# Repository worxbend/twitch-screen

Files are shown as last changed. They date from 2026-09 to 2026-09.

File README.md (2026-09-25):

<div align="center">

<p>🟣 STREAM CULTURE. TINY HARDWARE. BIG DESK ENERGY.</p>
<h1>✨ Twitch Screen</h1>
<p><strong>Your stream’s tiny desk bestie.</strong><br>
Live stats, little celebrations, and a front-row seat to the chaos.</p>

<p>
  
  
  
  
  
</p>

<p>
  <a href="docs/README.md"><strong>📖 Guidebook</strong></a> ·
  <a href="docs/guides/first-simulated-stream.md">🚀 Try the demo</a> ·
  <a href="docs/guides/device-build.md">🛠️ Build one</a> ·
  <a href="docs/guides/twitch-app-setup.md">🔗 Connect Twitch</a> ·
  <a href="CONTRIBUTING.md">💜 Contribute</a>
</p>

<a href="twitch-screen-cad-design/output/preview/01_front_hero.png">
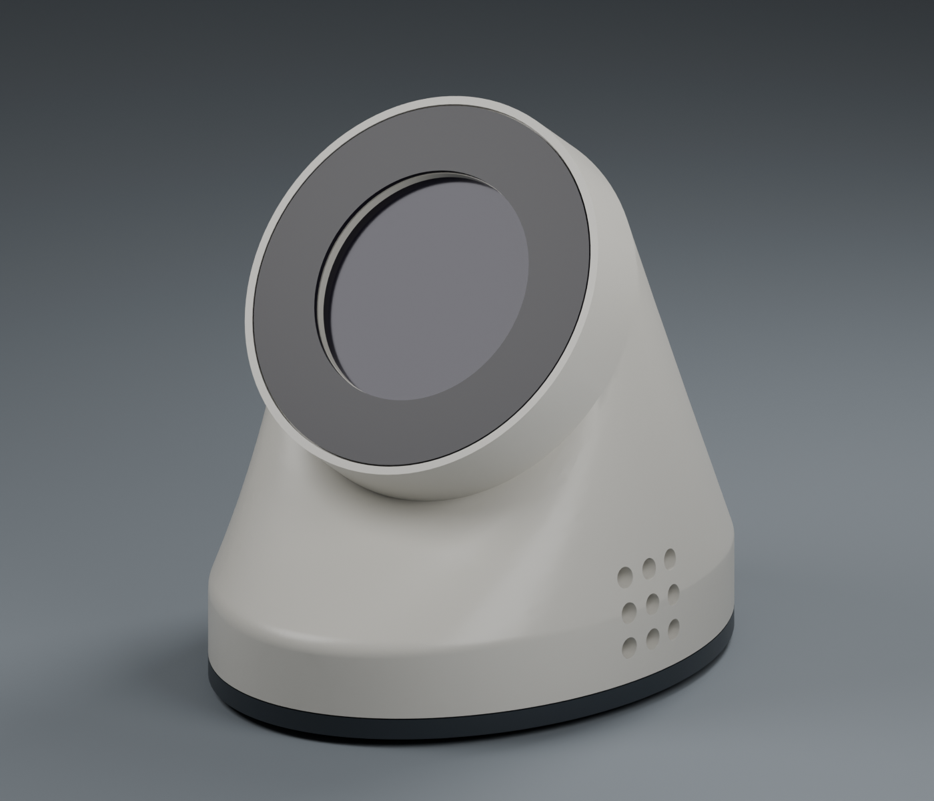
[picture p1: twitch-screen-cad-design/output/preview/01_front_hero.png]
CAD render of Twitch Screen: a warm white curved enclosure, tilted circular display, side vents, and dark removable base
  
</a>
<p><sub>Actual enclosure CAD render · screen shown unpowered · physical fit still needs validation</sub></p>

</div>

**Twitch Screen is a DIY ESP32 desk display that brings your Twitch stream into the physical world.** A 240 × 240 round LCD shows live viewers, uptime, followers, subscribers, and chat activity. Follow, sub, gift, raid, and bits events get their own animated notification cards. A Scala relay does the Twitch work; a printable little pod gives it a home. 🏡

Start with a simulated stream on your computer. Add the display when you’re ready. Connect your own Twitch channel after that. The full path is in the **[guidebook](docs/README.md)**.

## 📸 On a real desk

<p align="center">
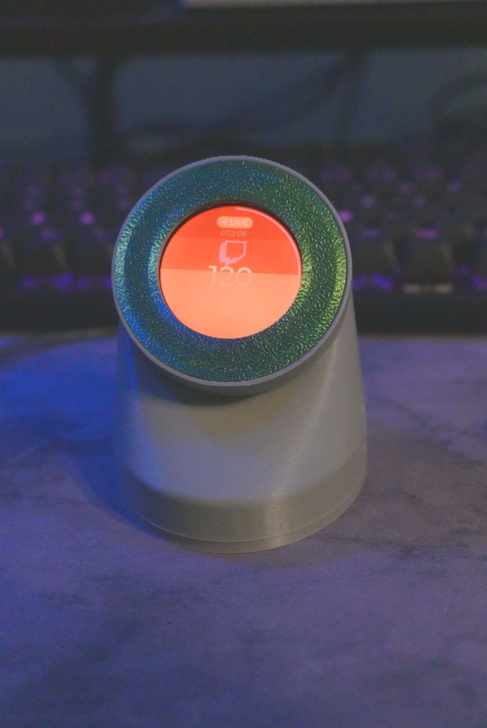
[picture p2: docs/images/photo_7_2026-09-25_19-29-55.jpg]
Assembled Twitch Screen showing live viewer stats
  
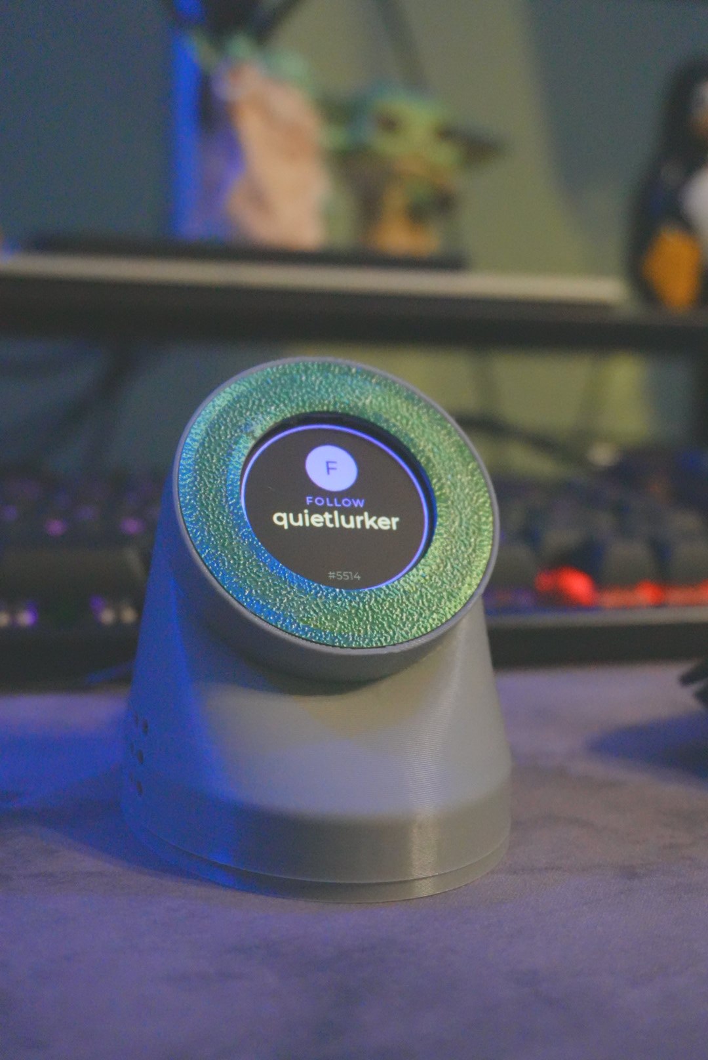
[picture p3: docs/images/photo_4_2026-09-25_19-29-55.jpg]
Front view of the assembled display showing a follow notification
  
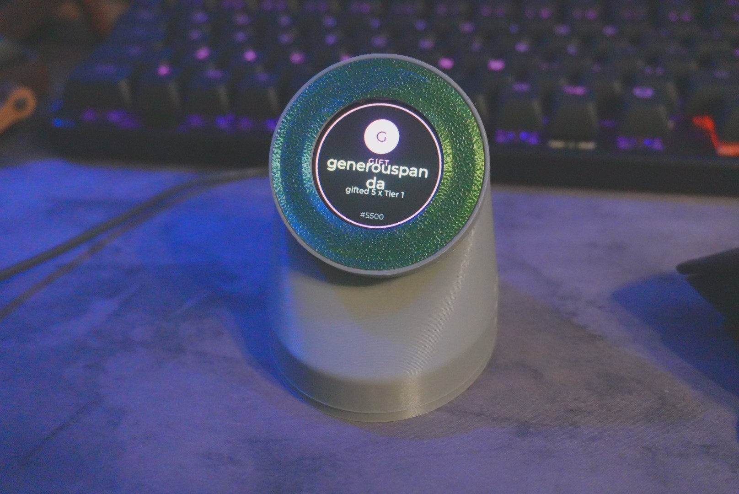
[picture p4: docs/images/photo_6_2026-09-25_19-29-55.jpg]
Assembled display showing a gift subscription notification
  
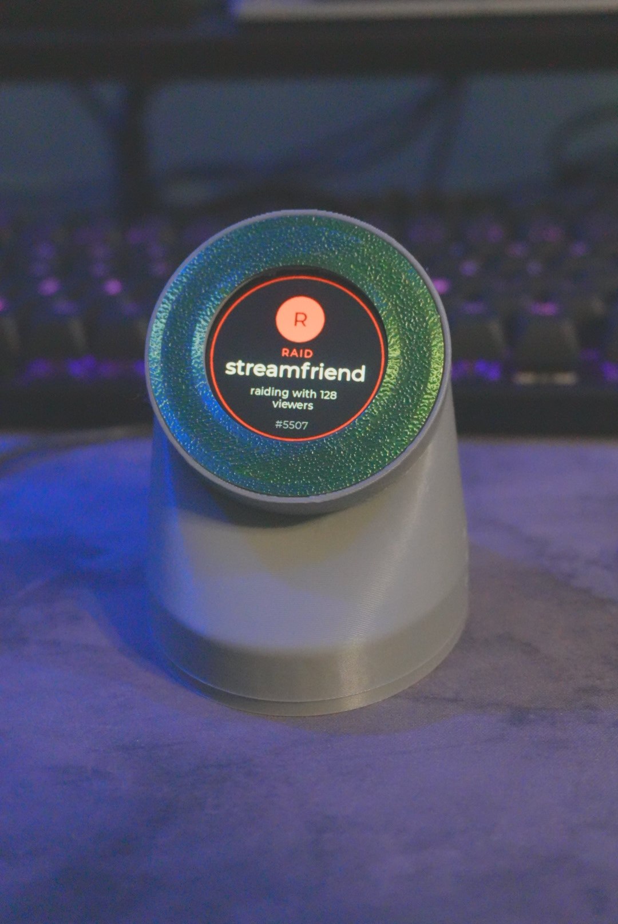
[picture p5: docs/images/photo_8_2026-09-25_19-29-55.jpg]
Front view of the assembled display showing a raid notification
  
</p>
<p align="center">
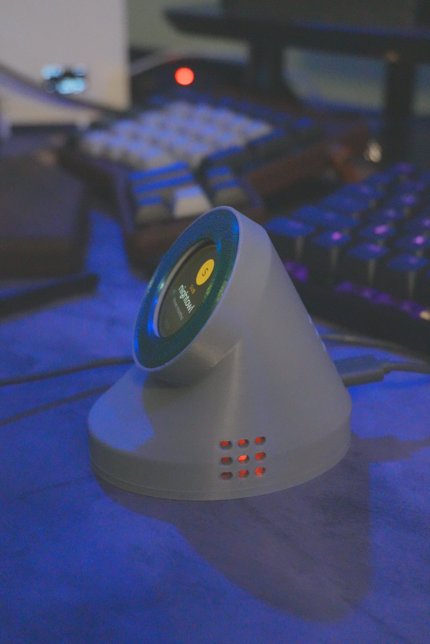
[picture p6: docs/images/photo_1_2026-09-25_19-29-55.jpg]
Side view of the assembled display on a desk
  
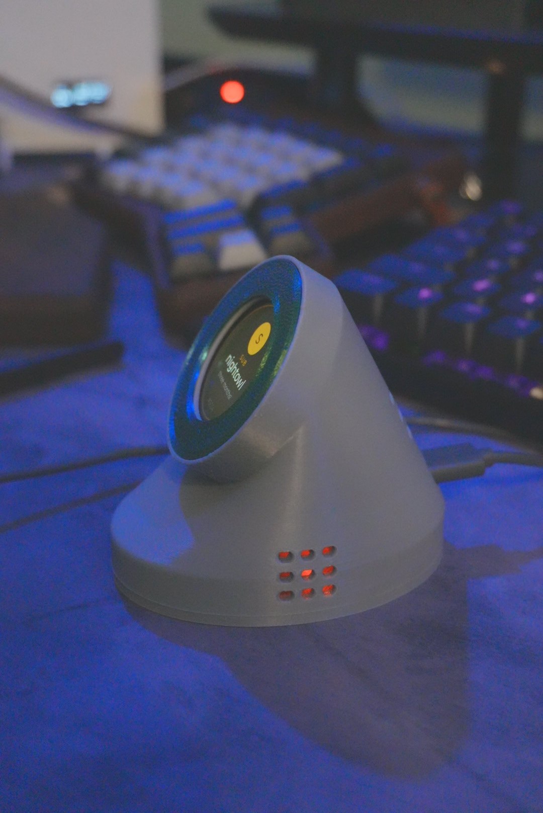
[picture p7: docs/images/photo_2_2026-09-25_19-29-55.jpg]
Angled view of the display enclosure and illuminated side vents
  
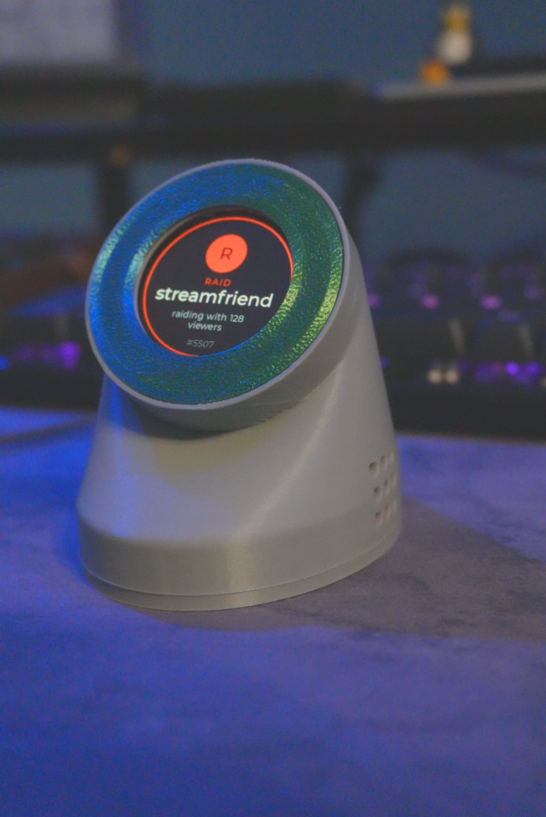
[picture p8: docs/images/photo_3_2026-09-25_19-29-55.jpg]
Angled view of the assembled display showing a raid notification
  
  <a href="docs/images/photo_5_2026-09-25_19-29-55.jpg">Side view of the enclosure showing the tilted screen and vent pattern</a>
</p>
<p align="center"><sub>Assembled prototype · select a photo to see it full size</sub></p>

## 👀 Small screen. Main-character energy.

| On your desk | Under the hood |
| :--- | :--- |
| 📊 **Stats at a glance** — live/offline state, audience totals, uptime, and a chat activity ring | LVGL 9 UI on a GC9A01 round LCD |
| 🎉 **A little celebration** — cards for follows, subs, gifts, bits, and raids | Twitch Helix, anonymous IRC, and EventSub feed the relay |
| 🧪 **No stream? Still a vibe.** — try a scripted audience without Twitch credentials | The real relay runs in `simulated` mode |
| 🔌 **Reconnect and carry on** — bounded replay helps recover recent notifications | Binary TSB/3 over one persistent TCP connection; replay lives in memory |
| 🖨️ **Print your desk buddy** — curved shell, dark base, rear USB-C | Four printable parts; editable FreeCAD, STEP, STL, and 3MF files included |
| 🛠️ **Make it yours** — inspect devices, disconnect a session, send test cards | Authenticated HTTP management API with Swagger UI |

Chat cards are hidden by default; chat still contributes to activity stats. No touch controls or on-device setup menu are implemented. Configure Wi-Fi and the relay address before flashing.

## 🧭 Pick your side quest

| You’re here to… | Start here | You’ll end up with… |
| :--- | :--- | :--- |
| **See what it does** 👋 | [First simulated stream](docs/guides/first-simulated-stream.md) | A working relay and observable events; no hardware or Twitch account needed |
| **Build the whole thing** 🔧 | [Parts, wiring & assembly](docs/guides/device-build.md) | A measured, wired, printed device ready for firmware |
| **Flash an ESP32** ⚡ | [Firmware setup](docs/guides/firmware-setup.md) | Wi-Fi, a relay address, and firmware on your board |
| **Use a real channel** 🟣 | [Twitch app setup](docs/guides/twitch-app-setup.md) | A registered app and broadcaster authorization |
| **Host the backend** 🖥️ | [Relay setup](docs/guides/relay-setup.md) | A configured local or Docker service with persistent tokens |
| **Use an assembled device** ☕ | [Everyday use](docs/guides/device-use.md) | An understanding of the screen, cards, and reconnect behavior |
| **Hack on the project** 🧑‍💻 | [Developer guide](docs/guides/development.md) | The toolchains, checks, source map, and contribution path |

## 🚀 First run: summon the pretend chat

You need Git, a POSIX shell (Linux, macOS, or WSL), `curl`, OpenSSL, and JDK 25 on your `PATH` for this setup. The included Mill launcher downloads its pinned tooling and Temurin JDK; older Linux systems use a JVM launcher that needs an existing Java installation to bootstrap. Follow the [Java setup notes](docs/guides/development.md#checkout-and-prerequisites) and allow network access and time for the initial build.

Run this in a terminal:

```sh
git clone https://github.com/worxbend/twitch-screen.git
cd twitch-screen/twitch-screen-relay
export RELAY_HTTP_AUTH_API_TOKEN="$(openssl rand -hex 32)"
RELAY_HTTP_HOST=127.0.0.1 RELAY_DEVICE_HOST=127.0.0.1 \
  RELAY_TWITCH_MODE=simulated ./mill run
```

Keep that terminal open. The generated token protects management routes, including in simulation. In a second terminal:

```sh
curl --fail http://localhost:8080/api/v1/health
curl --fail http://localhost:8080/api/v1/stats
```

Health returns `{"status":"Up"}`. Stats change as the simulator runs; allow around 30 seconds for the first audience telemetry snapshot. Open **[Swagger UI](http://localhost:8080/docs)** to explore the API. Public health and aggregate stats work without a token; management actions require authentication.

**🎯 First win unlocked:** the backend runs without Twitch credentials or an ESP32. Follow the [annotated tutorial](docs/guides/first-simulated-stream.md) for protected requests and a test notification. Stop the relay with **Ctrl+C**.

To connect real hardware, follow [relay setup](docs/guides/relay-setup.md) to listen on a trusted LAN interface, then [configure and flash the firmware](docs/guides/firmware-setup.md). The quick start above listens only on your computer.

## 🏡 Meet the pod

<table>
  <tr>
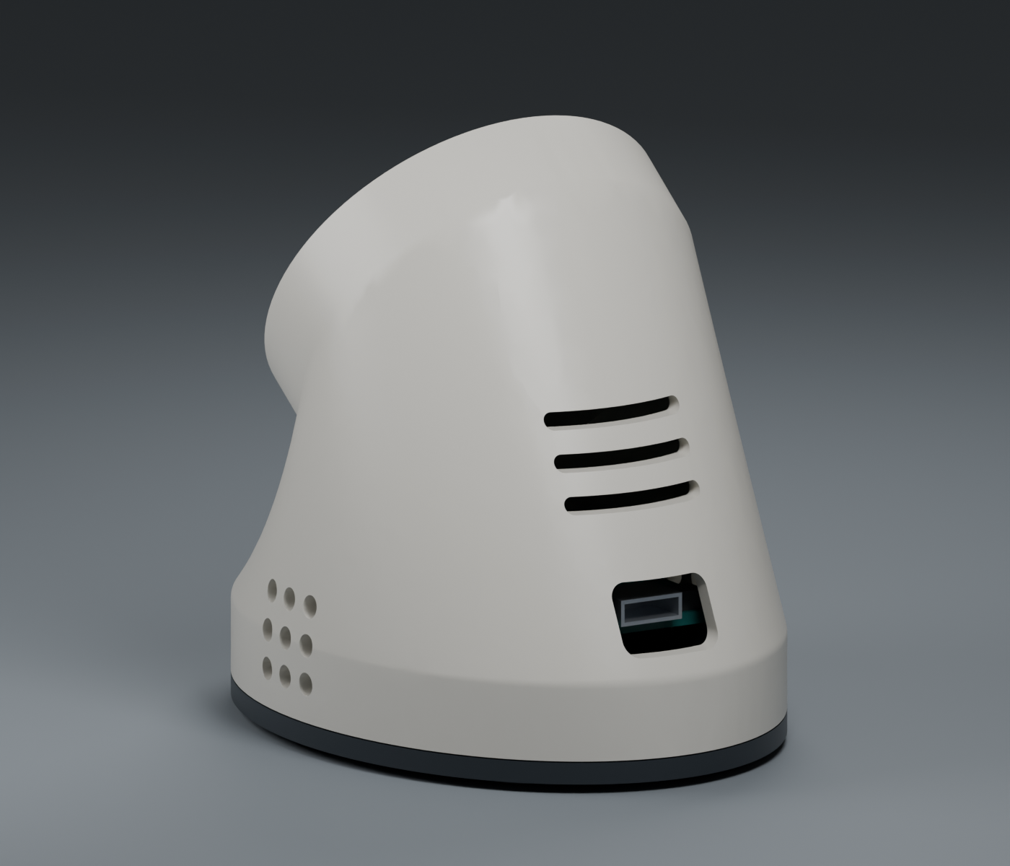
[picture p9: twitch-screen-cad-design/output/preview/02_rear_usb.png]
Rear CAD render showing the USB-C opening and ventilation
    <td align="center" width="50%"><br><strong>Business in the back 🔌</strong><br><sub>Rear USB-C and a removable base</sub></td>
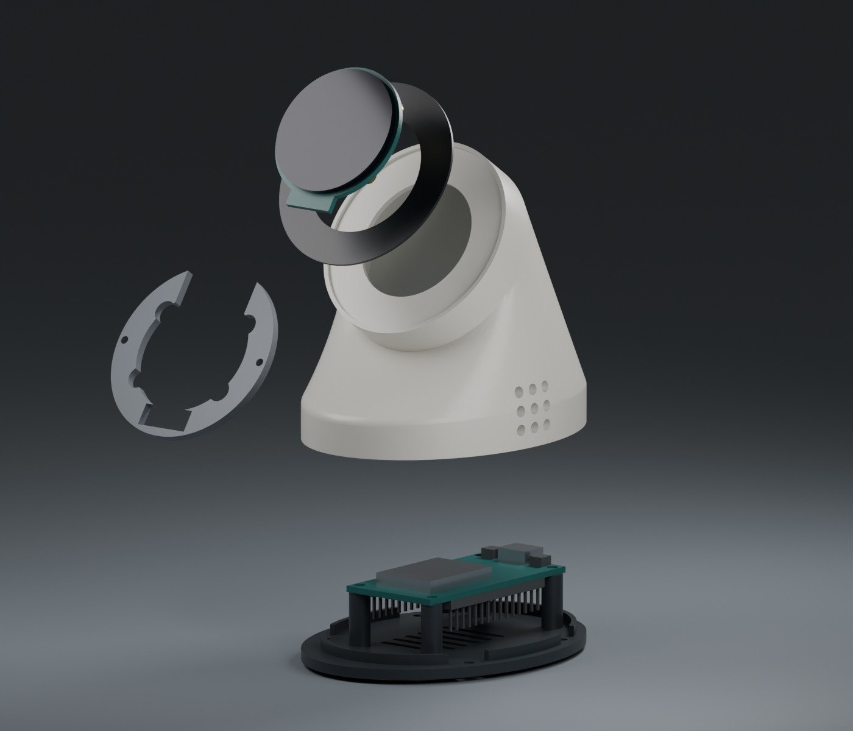
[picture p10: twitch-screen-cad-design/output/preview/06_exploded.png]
Exploded CAD render showing the round LCD, face insert, retainer, shell, ESP32, and base
    <td align="center" width="50%"><br><strong>Some assembly, much personality 🧩</strong><br><sub>Four printed parts around two boards</sub></td>
  </tr>
</table>

The nominal enclosure is **64 × 86 × 78.1 mm** before feet, with a **55° face tilt**. It targets a **30-pin ESP32 DevKit V1 Type-C** and **Waveshare 1.28inch LCD Module**. Clone boards vary: use the [measurement checklist](twitch-screen-cad-design/docs/measurement_checklist.md) before printing. Renders and automated geometry checks establish the design; a physical build must confirm fit and tolerances.

**[🖨️ Print plate](twitch-screen-cad-design/output/3mf/print_plate.3mf)** · **[📐 Editable CAD](twitch-screen-cad-design/output/freecad/TwitchScreen.FCStd)** · **[🔍 Cutaway render](twitch-screen-cad-design/output/preview/05_section.png)** · **[🛠️ Full build guide](docs/guides/device-build.md)**

## 🧠 How the magic gets to your desk

```mermaid
flowchart LR
    Twitch["🟣 Twitch<br>Helix · IRC · EventSub"] --> Relay["🖥️ Scala relay"]
    Demo["🧪 Simulated stream"] --> Relay
    Relay -->|"TSB/3 · TCP 8099"| ESP["⚡ ESP32"]
    ESP -->|SPI| LCD["📺 Round LCD"]
    Admin["🛠️ Management client"] <-->|"HTTP 8080"| Relay
```

The relay manages Twitch authorization, gathers events and stats, and pushes compact binary frames to the screen. The ESP32 manages Wi-Fi, the connection, and the UI. Live mode uses EventSub WebSocket by default, so a public webhook endpoint is unnecessary. Read the [architecture guide](docs/reference/architecture.md) for the event flow and trade-offs.

The device connection is **plain TCP without device authentication**. Keep port 8099 on a trusted LAN or private network; do not expose it directly to the internet. Remote management needs HTTPS in front of the relay. [Deployment details →](docs/guides/relay-setup.md)

## 🗂️ One repo, three workbenches

| Directory | What lives here | Tools |
| :--- | :--- | :--- |
| [`twitch-screen-relay/`](twitch-screen-relay/README.md) | Twitch integration, device server, HTTP API | Scala 3 · Mill · JDK 25 |
| [`twitch-screen-firmware/`](twitch-screen-firmware/README.md) | ESP32 firmware, UI assets, TSB/3 implementation | PlatformIO · Arduino · TFT_eSPI · LVGL 9 |
| [`twitch-screen-cad-design/`](twitch-screen-cad-design/README.md) | Parametric enclosure, print files, renders | FreeCAD · Blender |
| [`docs/`](docs/README.md) | Tutorials, setup guides, configuration and API references | GitHub Markdown |

Run each project’s commands from its own directory. There is no shared root build. The old Python demo server has been removed: its NDJSON v2 format is incompatible with the current TSB/3 firmware. Use the [Scala simulator](docs/guides/first-simulated-stream.md).

## 🧰 Commands you’ll actually use

| Working directory | Command | Purpose |
| :--- | :--- | :--- |
| `twitch-screen-relay` | `./mill test` | Relay tests |
| `twitch-screen-relay` | `./mill mill.scalalib.scalafmt/checkFormatAll` | Scala formatting check |
| `twitch-screen-relay` | `docker compose up --build` | Run the simulated relay in Docker; set management credentials first |
| `twitch-screen-firmware` | `pio run -e esp32dev` | Build firmware after creating `src/credentials.h` |
| `twitch-screen-firmware` | `pio run -e esp32dev -t upload --upload-port /dev/ttyUSB0` | Flash your board; replace the example port |
| `twitch-screen-firmware` | `pio test -e native` | Host protocol/session tests |
| Repository root | `python3 tools/check_protocol_vectors.py` | Check shared protocol vectors |

Tool installation, credentials, serial-port selection, sanitizers, containers, and CAD commands are covered in the [developer guide](docs/guides/development.md) and [guidebook](docs/README.md).

## 💜 Build with us

Found a weird pixel? A confusing setup step? A better way to mount the board? Contributions are welcome. Read **[CONTRIBUTING.md](CONTRIBUTING.md)**, run the relevant checks, and include what you observed. Hardware reports are especially useful with board measurements and photos.

[GitHub Actions](.github/workflows/ci.yml) covers relay compilation, tests, formatting and dependency auditing; firmware native/sanitizer tests and compilation; protocol vectors; CAD script syntax; and container build/smoke checks. Physical display behavior, live Twitch authorization, and printed fit need separate validation. Existing [review findings](tasks/review-status.md) and [verification evidence](tasks/review-judge.md) document those boundaries. Temporary [dependency audit exceptions](tasks/review-dependencies.md) expire on **2026-10-25**.

**Stuck?** Start with [troubleshooting](docs/guides/troubleshooting.md), then [open an issue](https://github.com/worxbend/twitch-screen/issues). Remove tokens, Wi-Fi passwords, and personal data from logs first.

**Project notes:** this is an independent DIY project, not an official Twitch product. No `LICENSE` file is currently checked in.

<div align="center">
<hr>
<p><strong>Made for the “one more stream” crowd. 🌙</strong><br>
<sub>May your packets arrive and your first layer stick.</sub></p>
</div>

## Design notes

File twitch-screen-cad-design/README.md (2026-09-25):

<div align="center">

<h1>🛠️ Twitch Screen · The Enclosure</h1>

<p><strong>A tiny pod with extremely important desk-job energy.</strong></p>
<p>Parametric FreeCAD · Four printable parts · Rear USB-C · 55° display face</p>

<p>
  <a href="../docs/guides/device-build.md">Build guide</a> ·
  <a href="output/3mf/print_plate.3mf">Print plate</a> ·
  <a href="docs/measurement_checklist.md">Measure your hardware</a> ·
  <a href="../docs/README.md">Guidebook</a>
</p>

CAD render of the warm-colored round display pod on its dark removable base

<p><em>Rendered from the project CAD. Nominal design validated; physical print and fit still require testing.</em></p>

</div>

Parametric FreeCAD enclosure for the photographed **30-pin ESP32 DevKit V1
Type-C** and **Waveshare 1.28inch LCD Module**, based on `PLAN.md`.

The circular face tilts 55° from horizontal. A warm-coloured pod meets a dark
removable base; all fasteners are concealed from the front. USB-C faces the rear.
Nominal envelope: **64 × 86 × 78.1 mm**, before adhesive feet.

## ✨ Take the tour

| Backstage access 🔌 | Every layer, explained 🧩 |
| --- | --- |
| Rear CAD render showing the recessed USB-C opening | Exploded CAD render showing the four printed parts and electronics |

New to the build? The [step-by-step device guide](../docs/guides/device-build.md) covers the parts list, exact GPIO wiring, slicer starting points and assembly. Prove the electronics with the [LAN-reachable simulated relay](../docs/guides/firmware-setup.md#start-a-relay-the-physical-device-can-reach), then close the case. 💜

All four hardware photos and five added concept screenshots were inspected.
The exterior follows their light curved pod, thin rim/dark face, side and rear
ventilation, vented underside and low base seam. The conflicting front USB in
one screenshot is overridden by PLAN.md's rear-only requirement.
See [reference analysis](docs/reference_analysis.md) and the
[measurement checklist](docs/measurement_checklist.md). Clone dimensions and
LCD thickness/connector dimensions remain provisional and editable.

## Repository layout

```
twitch-screen-cad-design/
├── parameters.json         all 57 design parameters — the input to everything
├── TwitchScreen.FCMacro    interactive entry point (must stay at this level)
├── scripts/                the model and the pipeline (must stay at this level)
│   ├── pod_geometry.py     pure BRep builder, no file I/O
│   ├── pod_document.py     wraps geometry in FreeCAD document objects
│   ├── export_project.py   writes every STEP/STL/3MF/FCStd + render meshes
│   ├── verify_*.py         exports, assembly and wall-thickness checks
│   ├── render_previews.py  Blender Cycles previews
│   └── package_project.py  gallery, manifest and deliverables zip
├── docs/                   reference analysis, measurement checklist, audit
├── refs/                   input imagery this design was derived from
│   ├── hardware/           photos of the actual ESP32 and LCD
│   ├── concepts/           concept screenshots
│   └── datasheets/         Waveshare dimension drawings
├── output/                 everything below is generated — see note
│   ├── freecad/            editable FCStd masters
│   ├── step/ stl/ 3mf/     CAD interchange and printable meshes
│   ├── preview/            Cycles renders + the Blender scene
│   ├── render_meshes/      intermediate meshes, consumed only by Blender
│   └── reports/            the four validation JSON reports
└── logs/                   run logs (ignored by git)
```

`output/` is committed on purpose: regenerating it needs FreeCAD 1.1.3 and
Blender 5.2, so on a machine without them these files are the only copy of the
design. `output/manifest.json` and `output/index.html` are the exceptions —
they are release artifacts, regenerated by `package_project.py`, and are
ignored by git because they go stale the moment any source file changes.

> **Do not move `scripts/` or `TwitchScreen.FCMacro`.** Every script derives
> its project root from `Path(__file__).resolve().parents[1]`, and the macro
> uses `.parent`, so both depend on their current depth. The saved `.FCStd`
> files also embed `module="pod_document"` with no path, so `pod_geometry.py`
> and `pod_document.py` must keep their filenames and stay side by side or
> existing documents can no longer recompute.

## Deliverables

| Use | File |
| --- | --- |
| Editable master | [TwitchScreen.FCStd](output/freecad/TwitchScreen.FCStd) |
| Open with parametric code loaded | [TwitchScreen.FCMacro](TwitchScreen.FCMacro) |
| CAD interchange assembly | [TwitchScreen_assembly.step](output/step/TwitchScreen_assembly.step) |
| Arranged printable parts | [print_plate.3mf](output/3mf/print_plate.3mf) |
| Individual printable meshes | [shell.stl](output/stl/shell.stl), [base.stl](output/stl/base.stl), [lcd_retainer.stl](output/stl/lcd_retainer.stl), [face_bezel.stl](output/stl/face_bezel.stl) |
| Rendered overview | [front](output/preview/01_front_hero.png), [rear USB](output/preview/02_rear_usb.png), [section](output/preview/05_section.png), [exploded](output/preview/06_exploded.png) |

Every printed part also has an individual STEP, 3MF and FCStd under `output/`.
STEP/FCStd preserve assembly coordinates. Individual STL/3MF files are rotated
into print orientation and placed on Z=0. The combined print plate contains
only four printed parts with 10 mm spacing. Files named `assembly_view_only`
include electronics reference shapes and are for inspection, not slicing.
Preview PNGs and the Blender scene are in `output/preview/`.

## Rebuild and verify

Uses the installed FreeCAD 1.1.3 Flatpak and Blender 5.2. No third-party FreeCAD
workbench is required. From this directory:

```sh
flatpak run --env=QT_QPA_PLATFORM=offscreen --command=FreeCADCmd org.freecad.FreeCAD -c 'import sys; sys.path.insert(0,"scripts"); import export_project; export_project.main()'
uv run --with trimesh --with numpy --with networkx python scripts/verify_exports.py
flatpak run --env=QT_QPA_PLATFORM=offscreen --command=FreeCADCmd org.freecad.FreeCAD -c 'import sys; sys.path.insert(0,"scripts"); import verify_assembly, verify_walls; verify_assembly.main(); verify_walls.main()'
blender -b --threads 8 --python scripts/render_previews.py
python scripts/package_project.py
```

If using a native FreeCAD installation, replace the Flatpak command prefix
with its `FreeCADCmd` executable. For interactive editing, run the supplied
macro from FreeCAD's Macro menu; keep it beside `scripts/` and `parameters.json`.
FCStd includes saved BRep shapes and can be inspected without the script, but
the feature proxies require the local geometry module to recompute.

`output/reports/geometry_validation.json` records exact solid checks, hardware
interference, rear-port position, mesh-volume comparison and STEP/FCStd reopen
checks. `mesh_validation.json` independently checks the written STL/3MF meshes
for closed surfaces, orientation, connectedness, dimensions and print placement.
`assembly_validation.json` covers screw-head envelopes, component insertion and
base extraction at 1 mm sampled positions (not continuous swept-volume proof),
editable-parameter recompute, and reopening
all native files. `wall_validation.json` records 695 exact surface-distance
samples; the minimum is the intended 1.5 mm bezel seat. These checks establish
nominal CAD validity, not physical fit or a tested print.

## Printing and assembly

Four printed parts: shell, base, LCD retainer and matte black face insert. Suggested starting settings:
PETG, 0.4 mm nozzle, 0.2 mm layers, four perimeters, five top/bottom layers and
20–30% infill. These are starting settings, not a tested printer profile.

The shell is supplied face-down; use supports for internal screw bosses and
inspect the rear USB roof in your slicer. Keep support interfaces away from
the LCD seat. The base prints underside-down, with its posts upward. The
retainer and face insert print flat. A brim can help the shell's narrow first-layer annulus.
The four-part plate uses two rows; inspect its reported dimensions in
`output/reports/mesh_validation.json` before adding brim/support expansion.
The current plate footprint is approximately **197 × 151 mm**; print parts
individually when your bed, brim or color choices call for a different layout.

Additional parts: the two electronic boards and supplied eight-wire loom;
four M2 × 6 mm pan-head screws (Ø3.8 mm heads) for the ESP32, four M2.5 × 8 mm low-profile
pan-head screws for the base, two M2 × 5 mm pan-head screws for the retainer,
four Ø8 × approximately 1.5 mm adhesive rubber feet, and 0.15 mm double-sided
adhesive film for the face insert. Screw heads must fit
the model's recesses (base Ø5.2 mm × 1.3 mm deep). Pilot holes are intended for
carefully formed plastic threads; verify fit on a coupon before committing.

1. Attach the matte black face insert inside the fine front rim using 0.15 mm
   adhesive film. Keep adhesive clear of the display opening and use film rated
   for the intended filament.
2. Remove the LCD protective film. Seat the LCD from inside the shell, with its
   tab down and rear connector up. The glass rests behind the bezel, with the
   active area unobstructed.
3. Fit the retaining ring behind the PCB, aligning the connector notch and tab
   relief. Tighten the two M2 screws lightly and evenly into the shell bosses.
4. Fix the ESP32 onto the four base posts. Its USB-C connector points toward
   +Y (rear); the PCB antenna points toward -Y (front). Connect the LCD loom to
   the appropriate GPIOs using your firmware's pin mapping.
5. Route wires through the side cavity, away from screw posts, antenna and glass.
   Leave a service loop so the base can be lowered before disconnecting wires.
6. Seat the locating lip and close the four underside base screws. Check cable
   insertion from the rear. EN/BOOT are reached by removing the base.
7. Attach the four feet in the shallow underside recesses.

No firmware, mains-power circuit, battery, or undocumented touch-screen variant
is part of this mechanical project. Hardware representations are fit envelopes,
not detailed manufacturer CAD. Physical assembly and print tolerances must be
confirmed against the actual boards using the measurement checklist.
The single rounded `cable_route` body is a Ø4.4 mm reserved corridor for the
eight-wire loom, not one thick wire or an electrical pin-mapping diagram.

## 📚 Next stops

- [Full device build guide](../docs/guides/device-build.md) — BOM, exact wiring and ordered assembly.
- [Firmware setup](../docs/guides/firmware-setup.md) — configure, build and upload over USB.
- [Using the device](../docs/guides/device-use.md) — understand the dashboard and event cards.
- [Troubleshooting](../docs/guides/troubleshooting.md) — fit checks, USB clearance and display issues.
- [Project overview](../README.md) and [complete guidebook](../docs/README.md).

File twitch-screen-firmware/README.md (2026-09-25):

<div align="center">

<h1>⚡ Twitch Screen · Firmware</h1>

<p><strong>240 × 240 pixels. A surprising amount of personality.</strong></p>
<p>ESP32 · Arduino · TFT_eSPI · LVGL 9 · TSB/3</p>

<p>
  <a href="../docs/guides/firmware-setup.md">Flash your device</a> ·
  <a href="../docs/guides/device-build.md">Wiring & build</a> ·
  <a href="../docs/guides/device-use.md">Daily use</a> ·
  <a href="../docs/README.md">Guidebook</a>
</p>

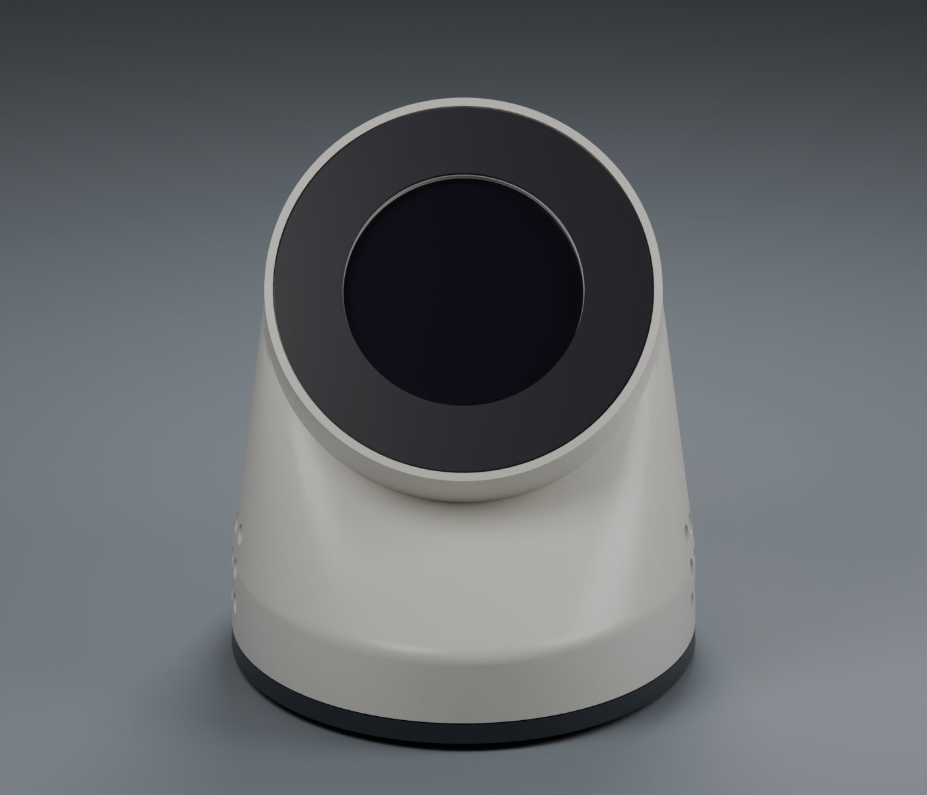
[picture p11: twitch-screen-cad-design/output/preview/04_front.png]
Front CAD render of the round display enclosure


<p><em>CAD visualization of the enclosure; physical fit remains to be validated.</em></p>

</div>

This firmware turns a classic ESP32 DevKit V1 and Waveshare GC9A01 LCD into an always-on stream dashboard. The [relay](../twitch-screen-relay/README.md) sends telemetry and notifications over persistent TCP; the device handles its own presentation, queue and reconnect loop. Your desk gets a tiny hype department. 💜

## ✨ What runs on the screen

- Animated **CONNECTING**, **OFFLINE** and **LIVE** states.
- Viewer count, stream uptime, follower/subscriber totals and observed chat total.
- A chat-activity ring and event cards for follows, subs, gifts, raids, Bits, chat and stream transitions.
- Automatic retries and bounded replay after connection interruptions.
- Custom INFO, MESSAGE, WARNING and ALERT cards supplied by the relay.

The current build has no touch/menu input, on-device provisioning, PWM brightness setting or OTA updater. Wi-Fi and relay settings are compiled in; USB is the update path. [Daily use](../docs/guides/device-use.md) explains timing, ASCII text support and recovery limits.

## 🚀 Quick start

From the **repository root**, install the pinned CLI and create the private header without replacing an existing one:

```sh
python3 -m venv .venv-pio
.venv-pio/bin/python -m pip install platformio==6.1.18
cd twitch-screen-firmware
if [ ! -e src/credentials.h ]; then
  cp src/credentials.example.h src/credentials.h
fi
```

Edit `src/credentials.h`: enter your Wi-Fi credentials, the relay computer's **LAN address**, TCP port `8099`, and optionally a unique device name. Leave `DEVICE_ID` empty for an automatic chip-derived identity. Do not commit this header or share a firmware binary containing your private settings.

The Wi-Fi password is recoverable from the firmware image/flash: this build does not enable flash encryption or secure boot. Use a trusted home network and physical device access; changing provisioning/security requires a separate migration with device recovery planning. HELLO identity/version control and non-ASCII bytes are replaced with `_` before transmission. The device TCP link is plaintext and unauthenticated; see the [protocol threat model](docs/PROTOCOL.md#2-transport-and-endianness).

Run these commands sequentially from `twitch-screen-firmware/`:

```sh
../.venv-pio/bin/pio test -e native
../.venv-pio/bin/pio run -e esp32dev
```

On Linux, also run the sanitizer gate:

```sh
../.venv-pio/bin/pio test -e native-sanitized
```

Once the correct device is connected, upload and inspect it:

```sh
../.venv-pio/bin/pio run -e esp32dev -t upload
../.venv-pio/bin/pio device monitor
```

The monitor uses 115200 baud. Close it before another upload. For explicit port selection, OS setup and BOOT-button recovery, use the complete [firmware setup guide](../docs/guides/firmware-setup.md).

Before first boot, start the [LAN-reachable simulated relay](../docs/guides/firmware-setup.md#start-a-relay-the-physical-device-can-reach) and leave it running. The [first simulated stream tutorial](../docs/guides/first-simulated-stream.md) is a separate local exercise whose loopback-only listener cannot accept a physical ESP32. Management authentication is required even in simulated mode. The old Python/NDJSON demo is incompatible with TSB/3.

## 🔌 Wiring

Disconnect power before changing connections.

| LCD | ESP32 label | GPIO |
| --- | --- | --- |
| VCC | 3V3 | — |
| GND | GND | — |
| DIN | D23 | 23 |
| CLK | D18 | 18 |
| CS | D5 | 5 |
| DC | RX2 | 16 |
| RST | D4 | 4 |
| BL | D15 | 15 |

The authoritative configuration is in [platformio.ini](platformio.ini): GC9A01, 240 × 240, 40 MHz SPI, `huge_app.csv`, pinned libraries and compiler flags. TFT_eSPI receives its setup through those flags; there is no library `User_Setup.h` to edit.

## 🧭 Source map

| File | Responsibility |
| --- | --- |
| [main.cpp](src/main.cpp) | Arduino setup/loop, queue admission and display dispatch |
| [link_client.cpp](src/link_client.cpp) | Transport-independent TSB/3 session, deadlines and retry state |
| [link_transport_esp32.cpp](src/link_transport_esp32.cpp) | ESP32 Wi-Fi, DNS and nonblocking TCP integration |
| [proto_codec.cpp](src/proto_codec.cpp) | Bounded binary encoder, decoder and stream framing |
| [notify_queue.h](src/notify_queue.h) | Eight-entry waiting queue, replay position and admission policy |
| [notification_wire.h](src/notification_wire.h) | Protocol fields converted into display notifications |
| [lv_port.cpp](src/lv_port.cpp) | LVGL/TFT bridge; one 19,200-byte synchronous partial draw buffer |
| [ui_idle.cpp](src/ui_idle.cpp) / [ui_notify.cpp](src/ui_notify.cpp) | Dashboard states and notification cards |
| [presentation.h](src/presentation.h) | Compact counts and readable chat colors |
| [include/lv_conf.h](include/lv_conf.h) | Project LVGL configuration |
| [test/](test/) | Host codec, queue, session, presentation and parser regressions |
| [tools/build_version.py](tools/build_version.py) | Source commit identifier embedded in the device greeting |

LVGL and application callbacks remain on the Arduino loop. Network work must keep that loop responsive. When the queue is full, event consumption pauses; defensive refusal reconnects before a later sequence can cross the gap. ACK reports queue admission, not completed on-screen presentation.

## 🧪 Verification and limits

From the repository root:

```sh
python3 tools/check_protocol_vectors.py
.venv-pio/bin/python twitch-screen-firmware/tools/test_runner_contract.py
```

This checks the shared normative protocol vectors. Native tests and an ESP32 compile establish software results; they do not establish physical LCD rendering, Wi-Fi outage recovery or watchdog behavior on hardware. Record those observations separately after any upload.

Boot logs report watchdog initialization/subscription status and the configured 10-second timeout. Every minute the loop reports its minimum free stack in bytes. Exercise live cards, long text, replay bursts and reconnects before recording hardware headroom; no measured minimum is asserted by host tests. LVGL allocation/assertion failures halt rendering with a repeated serial diagnostic while keeping the idle task/watchdog fed, avoiding an allocation-triggered reboot loop. UART diagnostics are dropped when the output buffer is full so replay cannot block the display loop.

Replay cards appear immediately without entrance effects. Routine live cards slide once; WARNING/ALERT retain the attention flash. Hidden dashboard timers and animations pause until visible again. Full-queue input pauses end after twice the relay's advertised idle timeout (180 seconds for the default 90-second idle), then reconnect for replay without advancing the queue sequence.

PlatformIO commands share a package store: do not run installs/builds concurrently. If an old global virtual environment stops importing PlatformIO after a Python update, use the isolated setup above.

## 📚 Keep exploring

- [TSB/3 specification](docs/PROTOCOL.md) — the normative wire contract and finite replay guarantees.
- [Hardware build guide](../docs/guides/device-build.md) — parts, printing, wiring and assembly.
- [Troubleshooting](../docs/guides/troubleshooting.md) — display colors, upload failures and connection logs.
- [Relay setup](../docs/guides/relay-setup.md) and [Twitch application setup](../docs/guides/twitch-app-setup.md).
- [PLAN.md](PLAN.md) — historical design notes and roadmap; some earlier status entries predate the current relay and enclosure.
- [Project overview](../README.md).

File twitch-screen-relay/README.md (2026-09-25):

<div align="center">

# 🛰️ twitch-screen-relay

**Your stream's backstage crew. Your tiny screen's very chatty friend.**

Twitch activity → Scala relay → TSB/3 → ESP32 desk display ✨

[🏠 Project overview](../README.md) · [📚 Guidebook](../docs/README.md) · [🎮 Connect Twitch](../docs/guides/twitch-app-setup.md) · [🔌 HTTP API](../docs/reference/http-api.md)

</div>

The relay watches a Twitch channel, turns activity into notification cards and live stats, and pushes them to ESP32 displays over persistent TCP. It also provides an authenticated management API, a simulator, diagnostics, and Swagger UI.

Built with **Scala 3**, **Ox**, synchronous **Tapir/Netty**, **jsoniter-scala**, **PureConfig**, **MacWire**, and **Twitch4J**. Versions are pinned in [build.mill](build.mill); the stack follows the [VirtusLab Scala Stack](https://vss.virtuslab.com/) approach.

## 🚀 First run: no Twitch account required

Have a Linux/macOS-style shell, Git, curl, OpenSSL, and **JDK 25 on `PATH`** ready. Mill's JVM launcher needs an installed Java runtime before it can download the pinned toolchain on platforms that cannot use its native launcher. See [native relay setup](../docs/guides/relay-setup.md#native-development-) for prerequisites and configuration.

From this directory:

```sh
export RELAY_HTTP_AUTH_API_TOKEN="$(openssl rand -hex 32)"
RELAY_TWITCH_MODE=simulated ./mill run
```

The launcher downloads the pinned Mill **1.1.9** and Temurin **25** toolchain on first use. Keep the generated management token privately; other terminals must use that same value. Management authentication is required in all modes.

Open **`http://localhost:8080/docs`** for Swagger UI. Check liveness:

```sh
curl --fail --silent --show-error http://localhost:8080/api/v1/health
```

Expected: `{"status":"Up"}`. The simulator produces a repeating stream of events, even with no device attached. Set firmware `SERVER_HOST` to this machine's LAN address and `SERVER_PORT` to **8099** to connect the display.

Send your first card from a terminal with the same token:

```sh
curl --fail --silent --show-error \
  -H "Authorization: Bearer $RELAY_HTTP_AUTH_API_TOKEN" \
  -H 'Content-Type: application/json' \
  --data '{"type":"info","title":"Hello, tiny world","body":"The desk lore begins."}' \
  http://localhost:8080/api/v1/notifications
```

Want the guided version? Start with [your first simulated stream](../docs/guides/first-simulated-stream.md), then [run the relay](../docs/guides/relay-setup.md).

## 🎛️ Pick a mode

| Mode | What happens | Twitch credentials |
|---|---|---|
| `disabled` | Manual API notifications and device services | None |
| `simulated` | Synthetic follows, subs, gifts, raids, Bits, chat, totals, and an initial stream-start event | None |
| `live` | Real Twitch Helix, IRC, and EventSub integration | Client ID/secret, then broadcaster consent |

The native default is `disabled`; the supplied Compose file uses `simulated`. Chat cards default to **hidden** so follows and raids can have their moment. Accepted chat still contributes to counters.

## 🎮 Connect your channel

Use the [complete Twitch setup guide](../docs/guides/twitch-app-setup.md) to register a **Confidential** app, set the exact callback, configure live mode, and grant consent as the broadcaster. The relay resolves the broadcaster's numeric ID from the channel login.

The default callback is `http://localhost:8080/api/v1/twitch/callback`. Start consent at the **management-protected** `/api/v1/twitch/authorize`; use Basic browser login or obtain the redirect with a Bearer-capable client. Tokens are saved in `data/twitch-token.json`, refreshed before expiry, and validated periodically. The ESP32 never stores Twitch credentials.

Default EventSub delivery uses an outbound **WebSocket**, which suits a home LAN. Webhooks are also supported with a public HTTPS callback. Live event sources are deliberately split:

| Source | Responsibility |
|---|---|
| Anonymous IRC | Chat, subscriptions, gifts, Bits, raids |
| EventSub | Follows, stream online/offline, channel updates |
| Helix polling | Viewer, follower, and subscriber totals |

Default scopes are `moderator:read:followers` and `channel:read:subscriptions`. IRC event types are not backed up by EventSub subscriptions in this version. Real-account provider acceptance and sustained recovery still require validation with actual Twitch credentials.

## 🧠 How it fits together

```mermaid
flowchart LR
  Twitch["Twitch: IRC / EventSub / Helix"] --> Source["TwitchSource"]
  Simulator["Simulated source"] --> Source
  Source --> Bus["EventBus"]
  Bus --> Router["NotificationRouter"]
  Bus --> Stats["StatsAggregator"]
  Bus --> Diagnostics["Activity / alerts / metrics"]
  Router --> Hub["DeviceHub"]
  Stats --> Hub
  API["HTTP notification API"] --> Hub
  Hub -->|"TSB/3 · TCP 8099"| ESP32["ESP32 displays"]
```

`DeviceHub` serializes sequence allocation and retains two bounded replay rings: **64 non-chat notifications** by default and **16 chat notifications**. A reconnect can replay retained events; relay restarts reset that history. TSB/3 provides best-effort replay, not durable delivery.

Internal consumers have bounded queues so slow diagnostics cannot stall Twitch ingestion. Per-device backpressure protects event ordering: a failed event enqueue closes the affected connection before later events can pass it; stats frames may be dropped. Device sessions and workers live inside the application lifetime managed by Ox.

The binary [TSB/3 specification](../twitch-screen-firmware/docs/PROTOCOL.md) defines the shared contract. NDJSON v2 peers cannot connect. Device TCP trusts the LAN and has **no authentication or TLS**; keep it private.

## 🐳 Docker, persistence, and configuration

From this directory, with your management token exported:

```sh
docker compose up --build -d
docker compose logs --tail=100 relay
```

Compose publishes ports **8080** and **8099**, starts simulated mode, sets a **512 MiB** starting memory budget, and persists the token directory in a named volume. See [relay deployment](../docs/guides/relay-setup.md) for live-mode overrides, private environment files, backups, HTTPS, and headless consent.

Common settings:

| Variable | Default | Purpose |
|---|---|---|
| `RELAY_HTTP_AUTH_API_TOKEN` | None | Management Bearer credential; Basic is an alternative |
| `RELAY_HTTP_PORT` | `8080` | Management listener |
| `RELAY_DEVICE_PORT` | `8099` | ESP32 TCP listener |
| `RELAY_TWITCH_MODE` | `disabled` | Select source |
| `RELAY_CHAT_NOTIFICATIONS` | `hide` | Show/hide individual chat cards |
| `RELAY_NOTIFICATION_TTL` | `8 seconds` | Default duration for manually posted cards |
| `RELAY_STATS_INTERVAL` | `5 seconds` | Device dashboard push cadence |

The [complete configuration reference](../docs/reference/relay-configuration.md) distinguishes environment overrides from advanced HOCON settings. Config is read at startup; authenticated `GET /api/v1/config` shows effective values with secrets masked. OpenTelemetry exports are opt-in through standard `OTEL_*` variables.

## 🔌 Your control room

| Endpoint | Use |
|---|---|
| `GET /api/v1/health` | Public HTTP liveness |
| `GET /api/v1/stats` | Public aggregate stats |
| `GET /api/v1/status` | Authenticated integration/device readiness |
| `GET /api/v1/devices` | Device identities and traffic diagnostics |
| `POST /api/v1/notifications` | Publish a card to all connected displays |
| `GET /api/v1/activity`, `/alerts`, `/logs` | Recent activity and operational diagnostics |

Swagger is at `/docs`. The [HTTP API reference](../docs/reference/http-api.md) covers every route, authentication, filters, response contracts, and the current stream-kind JSON spelling limitation. Notification POST returns **200**; retries can publish duplicates.

Use an HTTPS proxy or SSH tunnel for management requests across networks. The relay requires at least one valid Basic or Bearer method; health, stats, documentation, and protocol-validated callbacks remain public.

## 🧑‍💻 Developer commands

Run these from `twitch-screen-relay/`:

| Command | Purpose |
|---|---|
| `./mill compile` | Compile with warnings treated as errors |
| `./mill test` | MUnit suites, including HTTP and real-socket regressions |
| `./mill test.testOnly twitchscreen.relay.http.ApiSuite` | Focused HTTP API suite |
| `./mill run` | Start with the current environment |
| `./mill assembly` | Build `out/assembly.dest/out.jar` |
| `./mill mill.scalalib.scalafmt/` | Format Scala sources |
| `./mill mill.scalalib.scalafmt/checkFormatAll` | Check formatting |

Run repository-wide checks from the repository root:

```sh
python3 tools/check_protocol_vectors.py
python3 tools/audit_relay_dependencies.py
docker build -t twitch-screen-relay:review twitch-screen-relay
python3 tools/smoke_container.py
```

The dependency audit uses OSV and fails on new advisories or incomplete scans. Existing exact exceptions expire on **2026-10-25**; see the [dependency assessment](../tasks/review-dependencies.md). The container smoke exercises the selected image under its memory budget, HTTP protection/redaction, TSB/3 handshake, and shutdown.

## 🗂️ Find your way around

| Location | Responsibility |
|---|---|
| `Main.scala`, `ApplicationLifetime.scala` | Entry point and application lifecycle |
| `Dependencies.scala`, `Apis.scala` | Dependency and endpoint assembly |
| `config/` | Typed configuration and validation |
| `protocol/` | TSB/3 types, frame readers, encoders/decoders |
| `device/` | TCP listener, sessions, replay hub, notification API |
| `twitch/` | Live/simulated/disabled sources, OAuth, IRC/EventSub/Helix adapters |
| `bus/`, `stats/` | Internal events and aggregate stream state |
| `activity/`, `alerts/`, `health/` | Operational state and diagnostics |
| `http/`, `observability/` | HTTP infrastructure, authentication, logging, telemetry |
| `test/src/` | Regression suites |

Paths are under `src/twitchscreen/relay/` unless stated otherwise. One small [Java factory](src/twitchscreen/relay/twitch/EventSubFactory.java) bridges Twitch4J's Lombok-generated builder types; the surrounding integration remains Scala.

Contributors should keep protocol changes coordinated with firmware, preserve direct-style resource ownership, and run relevant suites. Start with the [guidebook](../docs/README.md) and [protocol](../twitch-screen-firmware/docs/PROTOCOL.md). New endpoints declare public, callback, or management access explicitly; unclassified routes fail startup.

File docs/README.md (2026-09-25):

<div align="center">
<h1>📖 The Twitch Screen guidebook</h1>
<p><strong>From “cute little screen” to “I built that.” ✨</strong><br>
A home for streamers, makers, and the people who read the source for fun.</p>
<p><a href="../README.md">🏠 Project overview</a> · <a href="guides/first-simulated-stream.md">🚀 First run</a> · <a href="guides/troubleshooting.md">🧯 Get unstuck</a></p>
</div>

Twitch Screen has three pieces: a relay running on a computer, ESP32 firmware driving a round LCD, and a printable enclosure. You can learn the relay first without buying parts or registering a Twitch app.

## 🧭 Choose your starting point

| Your starting point | Your path |
| :--- | :--- |
| **Curious, no hardware yet** | [First simulated stream](guides/first-simulated-stream.md) → [Architecture](reference/architecture.md) |
| **Building from scratch** | [Parts & assembly](guides/device-build.md) → [Relay setup](guides/relay-setup.md) → [Firmware setup](guides/firmware-setup.md) → [Twitch app setup](guides/twitch-app-setup.md) |
| **Already have an assembled device** | [Relay setup](guides/relay-setup.md) → [Firmware setup](guides/firmware-setup.md) → [Twitch app setup](guides/twitch-app-setup.md) → [Everyday use](guides/device-use.md) |
| **Developing or contributing** | [Developer guide](guides/development.md) → [Architecture](reference/architecture.md) → [Contribution guide](../CONTRIBUTING.md) |

## 🛠️ The complete build journey

Follow these milestones in order. Each guide supplies the detailed steps and checks.

| Step | Guide | Checkpoint before moving on |
| :--- | :--- | :--- |
| **1 · Meet the software** 🧪 | [First simulated stream](guides/first-simulated-stream.md) | Relay health responds; simulated stats and activity appear |
| **2 · Gather and measure** 📏 | [Device build](guides/device-build.md) | Your actual ESP32, LCD, connector, and screws match the intended fit |
| **3 · Wire on the bench** 🔌 | [Wiring and assembly](guides/device-build.md) | Unpowered connections match the firmware pin map |
| **4 · Host the relay** 🖥️ | [Relay setup](guides/relay-setup.md) | Management auth works and TCP 8099 is reachable from your trusted LAN |
| **5 · Configure and flash** ⚡ | [Firmware setup](guides/firmware-setup.md) | Board joins Wi-Fi and receives simulated stats/cards |
| **6 · Print and close up** 🖨️ | [Printing and assembly](guides/device-build.md) | Fit, cable routing, and USB access pass a real inspection |
| **7 · Bring your channel** 🟣 | [Twitch app setup](guides/twitch-app-setup.md) | App registration, callback, and broadcaster consent succeed |
| **8 · Stream with it** 🎉 | [Everyday use](guides/device-use.md) | You understand live/offline states, cards, and recovery |

Test the electronics before closing the enclosure. CAD validation and a render cannot prove that your particular clone board fits.

## 📚 Guides by task

| Guide | What you’ll find |
| :--- | :--- |
| [First simulated stream](guides/first-simulated-stream.md) | A linear, annotated lesson using only your computer |
| [Register and authorize a Twitch app](guides/twitch-app-setup.md) | Developer Console, client credentials, exact redirect URL, scopes, consent, and optional webhook setup |
| [Configure and run the relay](guides/relay-setup.md) | Native and Docker startup, authentication, network exposure, storage, and operations |
| [Build the device](guides/device-build.md) | Bill of materials, wiring, measurements, printing, assembly, and fit checks |
| [Configure and flash firmware](guides/firmware-setup.md) | PlatformIO, Wi-Fi credentials, device identity, upload, serial monitor, and display checks |
| [Use your screen](guides/device-use.md) | What appears on screen, notification behavior, restarts, and everyday care |
| [Develop the project](guides/development.md) | Repository layout, toolchains, tests, quality gates, and CAD regeneration |
| [Troubleshoot a problem](guides/troubleshooting.md) | Symptom → diagnostic check → next action |

## 🔎 Reference shelf

| Reference | Use it when… |
| :--- | :--- |
| [Relay configuration](reference/relay-configuration.md) | You need a setting’s exact name, default, or environment override |
| [HTTP API](reference/http-api.md) | You need endpoints, authentication, request bodies, and response behavior |
| [Architecture](reference/architecture.md) | You want to understand event flow, ownership, and system limits |
| [TSB/3 wire protocol](../twitch-screen-firmware/docs/PROTOCOL.md) | You are changing or implementing a device/relay protocol peer |
| [CAD measurement checklist](../twitch-screen-cad-design/docs/measurement_checklist.md) | You need to confirm dimensions before printing |
| [CAD completion audit](../twitch-screen-cad-design/docs/completion_audit.md) | You want the scope and limits of mechanical validation |
| [Documentation decisions](decisions/README.md) | You are changing how this guidebook is organized |

## 🧑‍💻 Component workbenches

**[Relay README](../twitch-screen-relay/README.md)** · **[Firmware README](../twitch-screen-firmware/README.md)** · **[CAD README](../twitch-screen-cad-design/README.md)**

The root README is the tour. This guidebook is the route map. Component READMEs are the workbench notes you want beside a terminal or soldering station.

## 🧾 About this documentation

The guides describe the checked-in implementation. Historical plans and review reports remain available, but current source and configuration win when they disagree. Configuration defaults and third-party setup instructions were reviewed on **2026-09-25**; official Twitch links are included where the provider’s requirements matter.

The [documentation maintenance guide](maintaining-documentation.md) explains source checking, visuals, tone, and review. [Documentation validation notes](../tasks/docs-quality-review.md) record what was verified and what still requires a real device or Twitch account.

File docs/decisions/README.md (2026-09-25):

# 🧾 Documentation decisions

Architecture decision records preserve the context behind consequential choices. This directory starts with the documentation structure chosen for this guidebook. It does not retroactively assign approval dates or rejected alternatives to the existing firmware and relay.

| Record | Status | Scope |
| :--- | :--- | :--- |
| [0001 — Organize the guidebook around reader journeys](0001-guidebook-structure.md) | Accepted | Documentation |
| [0002 — Make the device-link trust boundary explicit](0002-device-link-trust-boundary.md) | Accepted | TSB/3 deployment security |

New records use sequential four-digit filenames, a short title, and the sections **Status**, **Date**, **Context**, **Decision**, **Alternatives considered**, and **Consequences**. Preserve old records; a replacement should reference the record it supersedes.

For the current system’s architecture and source-backed trade-offs, read [Architecture](../reference/architecture.md). For writing and reviewing a guide, read [Documentation maintenance](../maintaining-documentation.md).

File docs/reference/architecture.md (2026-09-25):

# Architecture

Twitch Screen separates internet integration from a small embedded display. A Scala relay ingests Twitch observations, keeps the current stream state, and sends compact binary frames to an ESP32. The ESP32 owns Wi-Fi, connection recovery, its card queue, and the 240 × 240 round interface. The CAD project supplies the enclosure and exported manufacturing files.

This page describes the implementation and the reasoning recorded in source comments, the normative protocol, and commit history. It does not introduce new architectural decisions or assign retrospective approval to undocumented alternatives. For a runnable introduction, start with [your first simulated stream](../guides/first-simulated-stream.md).

## System boundaries

```mermaid
flowchart LR
  subgraph Sources
    TW[Twitch: IRC, EventSub, Helix]
    SIM[Deterministic simulation]
  end
  subgraph Relay
    FILTER[Display-name bot filter]
    BUS[Internal event bus]
    ROUTER[Notification routing]
    STATS[Statistics fold]
    DIAG[Activity, alerts, metrics]
    HUB[Device hub]
    HTTP[HTTP management API]
    TCP[TCP device sessions]
    FILTER --> BUS
    BUS --> ROUTER
    BUS --> STATS
    BUS --> DIAG
    ROUTER --> HUB
    STATS --> HUB
    HTTP --> HUB
    HUB --> TCP
  end
  subgraph Device
    LINK[TSB/3 client]
    QUEUE[Eight-card queue]
    UI[LVGL interface]
    LCD[TFT_eSPI and GC9A01]
    LINK --> QUEUE
    QUEUE --> UI
    LINK --> UI
    UI --> LCD
  end
  TW --> FILTER
  SIM --> FILTER
  TCP --> LINK
```

| Boundary | Contract | Responsibility |
|---|---|---|
| Twitch → relay | IRC, Helix, EventSub via twitch4j | Translate provider observations into domain events and maintain authorization/recovery. |
| Inside relay | `RelayEvent` on a bounded event bus | Keep ingestion independent of cards, statistics, and diagnostics. |
| Operator → relay | HTTP `/api/v1`, default port 8080 | Configuration inspection, diagnostics, manual cards, device control, and live Twitch authorization. |
| Relay ↔ firmware | TSB/3 over device-initiated TCP, default port 8099 | Negotiate capabilities, push events and absolute statistics, heartbeat, report teardown, and attempt bounded replay. |
| Firmware → LCD | LVGL → TFT_eSPI → SPI | Render the local idle screen and notification cards. |
| CAD source → deliverables | `parameters.json` and Python geometry pipeline | Generate and validate enclosure solids, printable meshes, assemblies, and previews. |

The HTTP API and TSB/3 are separate interfaces. JSON sent to `/api/v1/notifications` is a management request, not a device wire frame. The device does not use HTTP or Twitch credentials. The former Python `demo-server` and its retirement notice have been removed; use the Scala relay's simulated mode for TSB/3 events.

## Relay assembly and lifetime

The relay uses Scala 3, Ox structured concurrency on JVM virtual threads, synchronous Tapir endpoints on Netty, PureConfig for HOCON configuration, jsoniter for JSON, and MacWire for compile-time wiring. Exact versions belong in [build.mill](../../twitch-screen-relay/build.mill).

[Dependencies.scala](../../twitch-screen-relay/src/twitchscreen/relay/Dependencies.scala) assembles the graph in dependency order. It creates the bus and hub, registers activity/alert/metric consumers, then installs notification routing and statistics aggregation before selecting a Twitch source. Registering consumers before producers prevents initial events from disappearing into an empty bus. It then creates the device listener and HTTP APIs.

[Main.scala](../../twitch-screen-relay/src/twitchscreen/relay/Main.scala) starts HTTP and then starts live ingestion. The live integration can therefore receive callbacks before registering subscriptions. The simulated source publishes its initial observations when it is created, after the consumers are registered; it does not need the live startup callback.

The application scope owns listeners, device sessions, consumers, and the live Twitch resources. [ApplicationLifetime](../../twitch-screen-relay/src/twitchscreen/relay/ApplicationLifetime.scala) gives the hub a bounded shutdown phase before cancelling that scope. The hub queues `SERVER_SHUTDOWN` BYE messages, permits device writers to drain for up to two seconds, and closes the sockets. This ordering matters because cancelling writers first would prevent an orderly goodbye from reaching a device.

## From a source observation to a card

[TwitchSource](../../twitch-screen-relay/src/twitchscreen/relay/twitch/TwitchSource.scala) chooses one of three implementations:

| Mode | Behavior | Required Twitch credentials |
|---|---|---|
| `disabled` | No Twitch ingestion; HTTP card publishing and device connections still work. | None. |
| `simulated` | Fixed scripts publish a stream-start observation, audience events, chat, and totals. | None. |
| `live` | twitch4j integrates IRC, Helix polling, and the selected EventSub transport. | Application credentials and, for scoped operations, a broadcaster user grant. |

The simulator and live source share the downstream bus, filter, routing, and aggregation. This is why simulated development exercises the production card path without needing a live account. Simulation does not prove that Twitch accepts the configured application or grant.

For live mode, IRC supplies chat, subscriptions, gifted subscriptions, cheers, and raids. EventSub handles follows, stream lifecycle, and channel updates. Helix supplies viewer, follower, and subscriber totals. The default EventSub transport is WebSocket; the webhook alternative has callback authentication and deduplication. See [Twitch application setup](../guides/twitch-app-setup.md) for its authorization and network prerequisites.

[BotFilter](../../twitch-screen-relay/src/twitchscreen/relay/twitch/BotFilter.scala) rejects configured display names before publication. Matching uses trimmed, lowercase **display names**, not Twitch user IDs or logins. This early placement prevents a filtered account from consuming bus capacity, a sequence number, a replay slot, or chat statistics. Display-name changes can therefore change whether a sender is filtered.

[NotificationRouter](../../twitch-screen-relay/src/twitchscreen/relay/device/NotificationRouter.scala) maps audience observations to structured `EventRequest` values. A person goes in `actor`, their message in `text`, and event-specific counts and tiers remain numeric. For example, a raid retains its viewer count instead of burying it in a sentence. Bits are a count; the current integration has no donation source or monetary values.

Manual HTTP notification requests enter the hub directly. They supply generic title/body content and a display duration, even when the request names an audience or lifecycle kind. Posting a card is not equivalent to observing a Twitch event: a manually posted follow does not update follower totals, and a manually posted stream-start card does not change the observed stream state.

## Statistics and lifecycle ordering

[StatsState](../../twitch-screen-relay/src/twitchscreen/relay/stats/StatsState.scala) folds observations into a value: offline/live state, viewers, followers, subscribers, recent chat timestamps, and the cumulative non-bot chat count. The current totals come from observations; a follow card does not itself increment the follower total.

The cumulative message count resets when a stream starts and remains available after a stream ends. Chat rate uses a one-minute sliding window by default. Hiding chat cards does not suppress either count because visibility is decided later, at device delivery.

[StatsAggregator](../../twitch-screen-relay/src/twitchscreen/relay/stats/StatsAggregator.scala) merges events and timer ticks into one stateful flow, avoiding shared mutable state between those inputs. It normally publishes every five seconds. Stream start and end are special: the resulting lifecycle card and its updated statistics pass through one hub operation, so the device receives the event followed by the corresponding snapshot. This prevents a new lifecycle card from being followed by stale state from before that transition.

The wire `STATS` payload is an absolute snapshot. A missed earlier frame does not need to be reconstructed before the next snapshot makes sense. `GET /api/v1/stats` exposes a summary of the hub's latest statistics: state, viewers, followers, subscribers, uptime, and chat rate. It does not expose every wire field, including the cumulative message count.

## Concurrency and bounded memory

The relay has two distinct ordering boundaries.

- [EventBus](../../twitch-screen-relay/src/twitchscreen/relay/bus/EventBus.scala) gives every subscriber its own bounded queue and worker. A slow subscriber loses events once its queue fills; it cannot stop Twitch ingestion or another consumer. Concurrent producers have no global ordering guarantee on the bus. `/api/v1/status` exposes delivery and drop counters per subscriber.
- [DeviceHub](../../twitch-screen-relay/src/twitchscreen/relay/device/DeviceHub.scala) serializes device attachment, sequence assignment, replay storage, and outbound publication in an actor. Device-visible sequence order is established here. The actor offers messages without blocking; session writers encode and write frames outside it.
- **Actor mailboxes.** Every relay actor is created with Ox's `Actor.create` and keeps Ox's default mailbox of 16 pending operations; the relay sets no `BufferCapacity` override. The four actors are DeviceHub, the Twitch credential transitions in [TwitchAuth](../../twitch-screen-relay/src/twitchscreen/relay/twitch/TwitchAuth.scala), [ChannelStateTracker](../../twitch-screen-relay/src/twitchscreen/relay/twitch/ChannelStateTracker.scala), and [TwitchRuntimeHealth](../../twitch-screen-relay/src/twitchscreen/relay/twitch/TwitchRuntimeHealth.scala). When a mailbox is full, `ask` blocks the calling thread until a slot frees: EventSub and other Twitch callback threads, the Helix poller, the token maintenance loop, HTTP handler threads, and device-session threads. That is backpressure, not dropping. The bound therefore relies on every actor operation being short: operations never block on a socket or a queue, and network calls to Twitch (token exchange, refresh, validation, revocation) run outside the actor. The one exception is credential persistence, which writes or deletes the small local token file inside the credential actor. `DeviceHub.connectedCount` reads an atomic counter and deliberately bypasses the mailbox.

Encoding per session keeps the hub independent of slow sockets and permits a per-device text policy. The current firmware does not advertise `CAP_UTF8_TEXT`; the relay applies its wire text policy accordingly. That is separate from the UTF-8 JSON management interface.

The default capacities are explicit and finite:

| Resource | Default or fixed limit | Full-capacity behavior |
|---|---:|---|
| Internal bus subscriber queue | 1,024 events | That subscriber drops further offers and increments its drop counter. |
| TCP sessions, including handshakes | 64 | Additional accepted sockets are closed. |
| Per-device outbound queue | 128 frames | An event delivery gap closes that device connection; replaceable statistics can be dropped. |
| Relay actor mailbox (DeviceHub, credential transitions, channel state tracker, Twitch runtime health) | 16 pending operations (Ox default) | `ask` blocks the calling thread until a slot frees; nothing is dropped. See [Actor mailboxes](#actor-mailboxes). |
| Non-chat replay ring | 64 events | Oldest records are evicted. |
| Chat replay ring | 16 events | Oldest chat records are evicted without evicting non-chat records. |
| Firmware card queue | 8 cards | Pauses EVENT consumption until a slot frees; defensive refusal preserves the accepted sequence and reconnects. |
| Activity history | 500 entries | Retains a bounded recent history. |
| Alert history | 100 entries | Retains a bounded alert history. |
| Log history | 500 records | Retains a bounded recent log tail. |

Configuration defaults are in [application.conf](../../twitch-screen-relay/resources/application.conf); protocol limits and invariants are in [PROTOCOL.md](../../twitch-screen-firmware/docs/PROTOCOL.md). A protected diagnostic request can reveal a dropped-event condition, but diagnostics do not turn these bounded queues into durable storage.

## Reconnects and delivery limits

The [TSB/3 specification](../../twitch-screen-firmware/docs/PROTOCOL.md) is the authoritative contract for both independent implementations. It defines fixed-offset little-endian payloads, an eight-byte checked header, a 256-byte maximum frame, and explicit handshake/refusal behavior. Fixed records make field layout unambiguous across Scala and C++; absolute telemetry makes a captured snapshot useful when diagnosing the screen.

```mermaid
sequenceDiagram
  participant ESP as ESP32
  participant Relay as Relay session and hub
  ESP->>Relay: TCP connect and HELLO(last_seq, capabilities)
  Relay->>ESP: WELCOME(latest_seq, negotiated capabilities)
  opt Eligible reconnect with retained newer events
    Relay->>ESP: EVENT frames in ascending sequence, REPLAY flag set
  end
  Relay->>ESP: STATS snapshot
  Relay->>ESP: Live EVENT and periodic STATS
  ESP->>Relay: ACK for accepted event sequence
  Note over ESP,Relay: Heartbeats run independently of card presentation
```

On a fresh boot, the device sends `last_seq = 0`. It baselines to the relay's current sequence and receives no historical backlog. A reconnect with `0 < last_seq <= latest_seq` is eligible for retained events newer than that mark, subject to device capabilities and chat policy. A device ahead of the relay's current sequence rebaselines. The random relay session ID is diagnostic; it is not a persistent recovery identity.

The device's sequence mark tracks **accepted cards**, not cards already shown. An ACK therefore does not prove that a viewer saw a notification. While the queue is full, the link pauses EVENT consumption so queued cards can finish rendering. If queue admission nevertheless refuses a card, the firmware preserves the earlier accepted cards and high-water mark and reconnects for a replay attempt.

Replay is best effort within finite memory. Evicted events are lost; a device reboot loses its queue; a relay restart loses its rings and sequence state. After a restart, a numeric sequence overlap cannot establish that the device and relay refer to the same old event history. TSB/3 does not provide durable delivery or an end-to-end exactly-once guarantee.

The relay maintains one active connection per claimed device ID, reclaiming an older session when that ID reconnects and bounding repeated reclaims. IDs are not credentials. The TCP link has no TLS or cryptographic device authentication and belongs on a trusted network. HTTP management authentication protects a different boundary and does not secure port 8099.

## Firmware ownership and rendering

[main.cpp](../../twitch-screen-firmware/src/main.cpp) runs LVGL pumping, connection progress, queue consumption, and card presentation on the Arduino loop. Display callbacks remain on that loop. The transport adapter handles platform-specific network work; the transport-independent [link_client.cpp](../../twitch-screen-firmware/src/link_client.cpp) can also run in native tests with a controlled transport.

The receive path is a resumable parser with fixed buffers and per-loop work budgets. The display continues to pump during connection attempts and partial network frames. The notification queue and presentation helpers are separately testable without Arduino or an LCD.

[lv_port.cpp](../../twitch-screen-firmware/src/lv_port.cpp) uses one static 19,200-byte partial draw buffer: 240 pixels × 40 lines × two bytes. LVGL renders swapped RGB565 for the GC9A01's SPI byte order; flushing is synchronous through TFT_eSPI. This concrete arrangement is why changes to color format or SPI transfer ownership need physical display checks as well as compilation.

The idle UI displays connection and stream state plus statistics. The card UI displays one accepted notification at a time for its assigned duration before advancing the queue. A locally ticking uptime label is re-anchored by incoming statistics snapshots. Rendering tests on a host do not establish the panel's colors, wiring, Wi-Fi behavior, or watchdog behavior on a board.

## Management, observability, and persistence

Management endpoints require configured Basic authentication or a Bearer token, including in simulated and disabled modes. Missing or invalid credential configuration fails startup. Health, aggregate statistics, and Swagger UI are public. Live OAuth and EventSub callbacks use their own state/signature checks. [Http](../../twitch-screen-relay/src/twitchscreen/relay/http/Http.scala) classifies each endpoint; [ManagementAuth](../../twitch-screen-relay/src/twitchscreen/relay/http/ManagementAuth.scala) refuses unclassified endpoints during assembly.

Health is deliberately a liveness check. It stays useful when Twitch is unavailable; the richer protected status endpoint reports component health, connected devices, queue drops, and diagnostic counts. Alert acknowledgement records that an operator has seen an alert; it does not make an unresolved condition disappear. OpenTelemetry configuration is supplied through standard `OTEL_*` environment variables. The application installs context propagation for its virtual-thread work so traces and log context can remain connected.

| State | Location | Survives process or device restart? |
|---|---|---|
| Relay configuration | HOCON defaults and process environment | Only through the configuration supplied on the next start. |
| Twitch access and refresh tokens | Configured token file; `data/twitch-token.json` by default | Yes, while that file persists; Compose mounts its directory in `relay-data`. |
| Card replay, sequence counter, stream statistics | Relay memory | No. |
| Activity, alerts, buffered logs | Relay memory | No; external log or telemetry collection is separate. |
| Firmware Wi-Fi and relay settings | Ignored `credentials.h`, compiled into the firmware | Yes, as part of the flashed image. |
| Firmware accepted-card queue and sequence mark | Device memory | No. |
| Enclosure design and exported models | CAD source and versioned `output/` | Yes, as repository files. |

See [relay setup](../guides/relay-setup.md) for configuration and [troubleshooting](../guides/troubleshooting.md) for the observation sequence used to diagnose failures.

## Mechanical project and recorded design context

The enclosure is an independent parametric FreeCAD project. [parameters.json](../../twitch-screen-cad-design/parameters.json) feeds geometry and document creation; export, validation, rendering, and packaging are separate scripts. Versioned STEP, STL, 3MF, FCStd, and preview files let a reader inspect the design without running the CAD toolchain. The release manifest, gallery, and delivery ZIP are generated packaging artifacts.

The model's source layout is part of its recompute contract: scripts locate the project by their path depth, and stored FreeCAD proxies refer to `pod_document`. Moving or renaming those modules can leave an existing document readable but unable to recompute. Nominal geometry checks and sampled assembly clearances do not establish tolerances against a printed part or a particular board clone. See [device build](../guides/device-build.md) and the [CAD README](../../twitch-screen-cad-design/README.md).

The repository already records design rationale rather than a separate ADR series:

- [Protocol section 1](../../twitch-screen-firmware/docs/PROTOCOL.md#1-decisions-taken-from-the-design-review) records the binary record layout, absolute statistics, sequencing, and unsupported monetary fields.
- Commit `eb00a94` replaced NDJSON v2 with TSB/3 on both sides; the legacy demo remains retired.
- Commit `12a6737` paired lifecycle cards with their resulting statistics; `fd42e6a` added supervised Twitch recovery and serialized lifecycle transitions.
- Commit `a9cce0e` closed device connections before event gaps; `390a93f` ordered shutdown so writers can drain before application cancellation.
- [Review status](../../tasks/review-status.md) and [validation evidence](../../tasks/review-judge.md) record the remaining boundaries of exercised behavior.

Future decisions can be documented when they are made, with their actual alternatives and consequences. Existing source comments and history should remain evidence rather than being rewritten as new decisions.

Continue with [development and verification](../guides/development.md), or return to the [guidebook](../README.md).

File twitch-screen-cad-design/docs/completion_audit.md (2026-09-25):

# Completion audit against PLAN.md and requested deliverables

Scope: a complete nominal mechanical CAD project and exported artifacts.
The plan explicitly permits unverified hardware dimensions when exposed as
parameters requiring measurement. Physical manufacture/fit was not performed.

| Requirement | Evidence |
| --- | --- |
| Recursively inspect project; identify and view every relevant supplied image | Four original JPGs and five later-added screenshots individually opened; all classified in `reference_analysis.md` |
| Separate hardware evidence from industrial-design references | Four owned-hardware photos distinguished from five concept/appearance screenshots; concept dimensions and internals not treated as measured facts |
| Identify owned hardware without substituting another dev board | 30-pin DevKit V1 TYPEC, four corner holes, two headers, EN/BOOT and Type-C; Waveshare non-touch eight-wire LCD; clone maker/revision remains unknown |
| Do not infer manufacturing dimensions from perspective photos | Manufacturer LCD specification/drawing saved and cited; all unverified fit dimensions listed in measurement checklist and parameters |
| Document nine image-analysis topics before geometry implementation | `docs/reference_analysis.md`: inspected files, classifications, appearance brief, visible constraints, verified/unverified dimensions, assumptions and internal layout |
| Explicit coordinate and front/back convention | Analysis and geometry use +X right, +Y back, +Z up; front display faces -Y |
| Tilted circular face, wedge/pod, curved transitions, bezel and rounded base | Actual CAD views; dark fascia inside fine light rim, curved loft, 3 mm shoulder blend, side/rear/bottom ventilation, low base seam and four foot pockets |
| Independently valid internal architecture | Board envelopes, LCD perimeter retainer, connector/harness space, screw supports and removable base; four brass-mount reliefs use explicitly provisional, measurable parameters and do not assume a mating LCD thread |
| USB-C faces back; opening on back only | `usb_placement()` applies board placement to connector position; same result creates socket and rear cutout; geometry report checks +Y and probes intact front wall |
| Mechanically valid nominal solids | Four single, valid BRep solids; pairwise print-part/hardware clearance checks; exact cavity containment; sampled wall separation; base and LCD assembly-path checks |
| Editable FreeCAD output | Master plus four per-part FCStd files reopen; module-backed feature proxies update USB position and display angle; opening macro loads geometry code |
| STEP output | Four printed-part STEP files plus labelled full assembly; solid validity and roundtrip checks |
| STL output | Four oriented print meshes and a full assembly view mesh; printed meshes pass independent watertightness, winding, component and volume checks |
| 3MF output | Four individual parts, separated print plate, and full assembly view; real millimetre OPC/3MF packages with named mesh objects |
| Preview renders | Ten PNGs: front hero, rear USB, side, front, section, exploded, and individual views of shell, base, retainer and face insert; generated from CAD meshes |
| Reproducibility and handoff | Source, parameters, build commands, measurement checklist, assembly/printing instructions, reports, file index and checksummed package |

## Limits of the evidence

The exact clone PCB dimensions, stack heights and cable dimensions still require
caliper measurements. Concept dimensions were changed to fit the nominal real
hardware envelope; one concept's front USB was explicitly rejected. Hardware
objects are fit envelopes; the loom is a reserved routing corridor. Assembly
sweeps and wall checks are explicitly sampled, not exhaustive motion planning or
structural analysis. Default PETG settings have not been tested on a printer.

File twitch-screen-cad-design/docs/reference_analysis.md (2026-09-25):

# Reference analysis — before CAD implementation

The initial recursive inspection found four hardware photos, all opened on
2026-09-25. A final scan found five newly added enclosure screenshots; all were
opened and the model was revised to incorporate them. PLAN.md is the supplied
written plan. Both the initial hardware study and later design study are below.

| File | Classification | Observations |
| --- | --- | --- |
| `refs/hardware/1000011984.jpg` | Physical hardware, underside | ESP32 DEVKIT V1 TYPEC label; two populated header rows; four corner mounting holes; connector at one short end. |
| `refs/hardware/1000011986.jpg` | Physical hardware, component side | 30 pins (15 per side), ESP-32 metal shield, PCB antenna at opposite end from Type-C, CP2102-family bridge marking, EN and BOOT buttons beside USB. Manufacturer/revision cannot be established from visible markings. |
| `refs/hardware/1000011987.jpg` | Physical hardware, LCD rear / wiring | Waveshare 1.28inch LCD Module 240×240, eight-way side-entry connector with installed loom, four brass mounting points; board is round with a tab. |
| `refs/hardware/1000011988.jpg` | Physical hardware, LCD front | Circular glass, flat/tab at the ribbon end, protective film still attached; cable assembly visible. |
| `refs/concepts/screenshot_2026-09-25_06-08-08.png` | Previous concept/blueprint; shape, proportions and orientation reference | Front round display, tapered curved pod, 60° face concept, side 3×3 vents, rear horizontal slots/USB, low removable base and feet. Printed 60×55×62 dimensions are concept annotations, not hardware measurements. |
| `refs/concepts/screenshot_2026-09-25_06-08-21.png` | Desired appearance and previous detail concept | Light smooth shell, thin light outer rim, dark circular face, low dark base, rear horizontal vents, side perforations. USB, vent and boss dimensions are design examples, not verified owned-board dimensions. |
| `refs/concepts/screenshot_2026-09-25_06-08-40.png` | Concept section / internal layout reference | Display above a horizontal ESP32 with wiring space and screw base. The depicted 51 mm board, 8 mm posts, LCD stack and mount layout are not copied as facts; photographed Type-C hardware and current fit model govern. |
| `refs/concepts/screenshot_2026-09-25_06-09-02.png` | Desired frontal appearance; conflicting previous orientation | Large dark face with fine light rim and a subtle base seam. Front USB is explicitly rejected by PLAN.md. |
| `refs/concepts/screenshot_2026-09-25_06-09-10.png` | Base appearance / assembly concept | Rounded footprint, four circular feet, six underside ventilation slots and understated perimeter seam. |

At first only the written industrial-design brief was available. The final
design now incorporates all five added screenshots: a dark circular face insert
with a 1.15 mm light outer rim, sloping curved pod, 3×3 side perforations, three
rear horizontal slots, six underside slots, four foot recesses and a dark base
seam. The rear-only USB rule takes precedence over the conflicting frontal image.

The real 32.4 mm active LCD area cannot fill a concept's roughly 50 mm black
face. A thin black printed fascia surrounds the actual display instead of
enlarging or inventing the LCD. The 64 × 86 × 78.1 mm enclosure is larger than
the concept because the provisional 55 mm Type-C board, downward headers,
plug, screw heads and wire housings need real clearance. The conceptual 55 mm
depth cannot enclose a 55 mm PCB plus connector and walls. The 55° face is an
adjustable design choice close to the concept's tilted display language.

## Coordinates

Millimetres. +X device right, +Y device rear, +Z upward. FRONT is the display
side (negative Y); BACK is USB-C side (positive Y). The display local axes are
u = +X, v = up the tilted face, n = outward toward the viewer. Rotate local
coordinates about +X by the face angle. The ESP32 is horizontal with USB toward
+Y and its antenna toward -Y. USB cutout comes from the connector transform.

## Authoritative dimensions and uncertainty

[Waveshare's official product documentation](https://docs.waveshare.net/1.28inch_LCD_Module/)
identifies SKU 19192, GC9A01, active display diameter 32.4 mm, overall module
40.4 × 37.5 mm, 240×240 resolution and eight SPI/power signals. These dimensions
are used without estimating scale from photographs.

No authoritative mechanical drawing for the exact ESP32 Type-C clone has been
identified. Do not substitute an Espressif DevKitC or micro-USB DOIT outline.
Provisional starting envelope: 55 × 28 × 1.6 mm; all connector positions,
heights, mounting-hole centres, diameter, pin projection and component heights
must be measured on the user's board. Likewise LCD stack thickness, rear
connector envelope, mounting-thread size and hole pattern need verification.
The CAD parameter definitions and measurement checklist distinguish these
assumptions from verified dimensions. The output is a complete nominal CAD
design; physical fit remains conditional on those measurements.

The official [dimensioned outline image](https://www.waveshare.com/img/devkit/LCD/1.28inch-LCD-Module/1.28inch-LCD-Module-details-size.jpg)
was subsequently retrieved and visually inspected as `refs/datasheets/waveshare_dimensions.jpg`.
It confirms the 37.50 mm circular outline, 40.40 mm overall length and 14.28 mm
tab width (3.59 mm lower tab segment). It does not dimension hole centres or
thickness. `refs/datasheets/waveshare_rear.jpg` was also inspected; despite the filename,
it is the official development-board wiring/use photograph, not another owned
hardware photo or an enclosure design reference. It confirms a flexible loom.

## Proposed arrangement and design assumptions

- 55° display plane from horizontal, circular bezel on a smooth lofted pod.
- Horizontal ESP32 on four base standoffs; header pins face downward with space
  for female jumper housings. EN/BOOT are accessible after removing the base.
- LCD behind the integral front bezel, retained from inside by a removable
  peripheral ring; connector, tab and four brass mounts receive explicit
  clearance. Brass mount envelopes/pattern remain provisional parameters;
  the retainer does not fasten into their undocumented threads.
- Eight-wire harness routes through the side cavity to the downward headers;
  keep slack to separate base from shell during servicing.
- USB insertion direction +Y, rear opening projected from the board's actual
  connector location. A plug-overmould keepout is checked as well as the socket.
- Shell and base close with recessed underside screws into pilot-hole bosses;
  no front USB port. Small replaceable feet are purchased adhesive parts.
- A 0.8 mm matte black fascia is attached with 0.15 mm double-sided adhesive;
  the original 1.5 mm structural bezel remains intact underneath it. This keeps
  the thin-rim appearance without making the LCD or the shell wall fictitious.
- Printed parts are nominal PETG, 0.4 mm nozzle, with assembly clearance exposed
  as a parameter. These are manufacturing choices, not measured hardware facts.

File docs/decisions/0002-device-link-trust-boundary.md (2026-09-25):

# ADR-0002: Make the TSB/3 deployment trust boundary explicit

## Status

Accepted for the Kimi review remediation. Reaffirmed by the owner on
2026-09-25: no device-link authentication (API key/HMAC) or TLS will be added;
the trusted-home-LAN boundary is the deployment requirement.

## Date

2026-09-25

## Context

TSB/3 sends display events over plaintext TCP and identifies a device by its
self-declared name. Review finding H2 correctly identifies impersonation and
replacement attacks. Adding a token to HELLO would change its frozen layout and
would not authenticate a rogue relay or hide credentials on the LAN.

## Decision

Use H2's explicit trusted-home-LAN option for the existing protocol. Document the
trust boundary and impersonation consequences in [PROTOCOL §2](../../twitch-screen-firmware/docs/PROTOCOL.md#2-transport-and-endianness).
Operators must restrict the listener to a segment whose hosts they trust. HTTP
management authentication is a separate boundary and requires HTTPS when
credentials cross an untrusted network.

Retain the protocol's uncapped `retry_after_s` minimum, including its maximum
65535-second suppression, as a trusted-relay instruction. Bound local queue
backpressure separately so a lost relay does not leave a device apparently
online indefinitely. Document that firmware credentials in unencrypted flash
also assume trusted physical access.

## Alternatives considered

Pinned-certificate TLS could authenticate the relay and protect traffic. It
requires provisioning, certificate rotation and device recovery design, plus
physical validation. A pre-shared HELLO token alone protects neither secrecy nor
relay identity and requires a versioned wire migration. These remain options for
deployments outside the documented trust boundary.

## Consequences

Existing devices retain byte-compatible TSB/3. This change does not add network
authentication, encrypted flash, secure boot or OTA. A malicious reachable LAN
host can still impersonate a peer. Such networks need an authenticated encrypted
transport before this deployment assumption is valid.

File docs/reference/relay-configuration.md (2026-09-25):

# ⚙️ Relay configuration reference

[Guidebook](../README.md) · [Relay setup](../guides/relay-setup.md) · [Twitch setup](../guides/twitch-app-setup.md) · [HTTP API](http-api.md)

The source of truth is [resources/application.conf](../../twitch-screen-relay/resources/application.conf), with startup validation in [Config.scala](../../twitch-screen-relay/src/twitchscreen/relay/config/Config.scala) and [HttpAuthConfig.scala](../../twitch-screen-relay/src/twitchscreen/relay/config/HttpAuthConfig.scala). Settings are read at startup. The HTTP configuration endpoint is read-only.

The tables below list **every explicit `RELAY_*` environment override** in the shipped configuration. Advanced settings further down have HOCON keys only; an invented environment name has no effect.

## Management HTTP and authentication 🔑

| Environment variable | HOCON key | Default | Meaning / constraint |
|---|---|---|---|
| `RELAY_HTTP_HOST` | `http.host` | `0.0.0.0` | HTTP bind address |
| `RELAY_HTTP_PORT` | `http.port` | `8080` | HTTP port, 1–65535 |
| `RELAY_HTTP_AUTH_API_TOKEN` | `http.auth.api-token` | Empty | Bearer credential; at least 32 UTF-8 bytes in the accepted ASCII alphabet |
| `RELAY_HTTP_AUTH_BASIC_USERNAME` | `http.auth.basic-username` | Empty | Basic username; no colon, control characters, or surrounding whitespace |
| `RELAY_HTTP_AUTH_BASIC_PASSWORD_HASH` | `http.auth.basic-password-hash` | Empty | Salted PBKDF2-SHA256 verifier; requires a Basic username |

At least one complete authentication method is mandatory **in every mode**. If both are configured, either can authorize a request. Half-configured Basic credentials fail startup even with a valid Bearer token.

The Bearer alphabet is `A–Z`, `a–z`, `0–9`, `.`, `_`, `~`, `+`, `/`, `-`, with optional trailing `=`. `openssl rand -hex 32` generates an accepted 64-character random value. An ordinary sentence, token with spaces, or short default is rejected.

The exact Basic verifier format is `pbkdf2-sha256$600000$<base64-salt>$<base64-key>`, with a 16–64-byte salt and 32-byte derived key. Generate it with `python3 tools/hash_management_password.py` from `twitch-screen-relay/`. Keep literal dollar signs by single-quoting a saved verifier in shell or Compose environment files.

Neither listener terminates TLS. See the [network guide](../guides/relay-setup.md#network-boundaries-and-https-) before exposing management credentials beyond localhost.

## Device listener 📡

| Environment variable | HOCON key | Default | Meaning / constraint |
|---|---|---|---|
| `RELAY_DEVICE_HOST` | `device-link.host` | `0.0.0.0` | TCP bind address |
| `RELAY_DEVICE_PORT` | `device-link.port` | `8099` | TCP port, 1–65535; match firmware `SERVER_PORT` |
| `RELAY_DEVICE_IDLE_TIMEOUT` | `device-link.idle-timeout` | `90 seconds` | Accepted duration must have 1–65535 whole seconds; longer than ping interval |

The listener accepts **TSB/3** only. The firmware connects to the relay's reachable address, not the listener's `0.0.0.0` wildcard. There is no device authentication or encryption; use a trusted device network.

## Twitch mode and application 🎮

| Environment variable | HOCON key | Default | Meaning / constraint |
|---|---|---|---|
| `RELAY_TWITCH_MODE` | `twitch.mode` | `disabled` | `disabled`, `simulated`, or `live`; case-insensitive |
| `RELAY_TWITCH_CHANNEL` | `twitch.channel` | Empty | Channel **login**, without URL or `#`; mandatory in live mode |
| `RELAY_TWITCH_CLIENT_ID` | `twitch.client-id` | Empty | Twitch application Client ID; mandatory in live mode |
| `RELAY_TWITCH_CLIENT_SECRET` | `twitch.client-secret` | Empty | Twitch application secret; mandatory in live mode |
| `RELAY_TWITCH_POLL_INTERVAL` | `twitch.poll-interval` | `30 seconds` | Positive Helix polling interval |
| `RELAY_SIMULATION_INTERVAL` | `twitch.simulation.interval` | `12 seconds` | Positive interval between scripted synthetic events |

| Mode | Source behavior | Needs Twitch application credentials? |
|---|---|---|
| `disabled` | No Twitch connection; manual notification API still works | No |
| `simulated` | Repeating synthetic stream activity and chat | No |
| `live` | Helix polling, anonymous IRC, and EventSub | Yes, plus broadcaster consent for scoped data |

The Dockerfile defaults to `disabled`; **Compose overrides this to `simulated`**. The numeric broadcaster ID is resolved from the login. The selected mode determines which Twitch HTTP routes exist.

## Broadcaster OAuth 🔐

| Environment variable | HOCON key | Default | Meaning / constraint |
|---|---|---|---|
| `RELAY_TWITCH_REDIRECT_URL` | `twitch.oauth.redirect-url` | `http://localhost:8080/api/v1/twitch/callback` | Exact registered callback; path must be `/api/v1/twitch/callback` |
| `RELAY_TWITCH_SCOPES` | `twitch.oauth.scopes` | `moderator:read:followers,channel:read:subscriptions` | Comma-separated requested scopes; replaces defaults |
| `RELAY_TWITCH_TOKEN_FILE` | `twitch.oauth.token-file` | `data/twitch-token.json` | Nonempty storage path in live mode; relative to process working directory |

Live callback validation accepts HTTPS or HTTP on the recognized loopback hosts `localhost`, `127.0.0.1`, and IPv6 loopback. It rejects a query string, fragment, user-info, or any different path. Register the exact chosen URL with Twitch; the default localhost spelling is the documented setup path.

The backend receives access and refresh tokens through consent; there is **no user-access-token environment setting**. The grant's login must match `RELAY_TWITCH_CHANNEL`. A missing grant keeps relevant integrations awaiting authorization; it is not a reason to paste a Twitch token into firmware.

Changing scope configuration requires a new consent round to obtain new permissions. Readiness checks require only configured scopes. Reduced-scope grants still receive scope-free stream lifecycle and channel updates; follow and subscriber polling require their respective scopes. Scope names must be distinct and nonblank; an empty list is supported.

## EventSub transport 📬

| Environment variable | HOCON key | Default | Meaning / constraint |
|---|---|---|---|
| `RELAY_TWITCH_EVENTSUB_TRANSPORT` | `twitch.event-sub.transport` | `websocket` | `websocket` or `webhook`; case-insensitive |
| `RELAY_TWITCH_EVENTSUB_CALLBACK_URL` | `twitch.event-sub.callback-url` | Empty | Required for live webhook mode; HTTPS on port 443, path `/api/v1/twitch/eventsub` |
| `RELAY_TWITCH_EVENTSUB_SECRET` | `twitch.event-sub.secret` | Empty | Required for live webhook mode; 10–100 ASCII characters |

WebSocket transport opens an outbound connection. Webhook transport requires Twitch to reach your HTTPS callback. Its URL cannot include user-info, a query, or a fragment. See [Twitch setup](../guides/twitch-app-setup.md#optional-use-eventsub-webhooks-) for callback routing and secret-rotation limitations.

## Notifications and display cadence ✨

| Environment variable | HOCON key | Default | Meaning / constraint |
|---|---|---|---|
| `RELAY_NOTIFICATION_TTL` | `notifications.default-ttl` | `8 seconds` | Default for manual HTTP notifications only; 1–6553500 milliseconds |
| `RELAY_CHAT_NOTIFICATIONS` | `notifications.chat` | `hide` | `show` or `hide`; case-insensitive |
| `RELAY_IGNORED_DISPLAY_NAMES` | `notifications.ignored-display-names` | `streamelements,nightbot,moobot,streamlabs,fossabot,sery_bot` | Comma-separated display names; replaces the default list |
| `RELAY_STATS_INTERVAL` | `stats.broadcast-interval` | `5 seconds` | Positive interval between device stats broadcasts |

Chat `hide` suppresses individual chat **cards**; accepted chat still feeds counters. Ignored display names are filtered **at source**, so their authored events also do not enter the bus, replay, or chat counters. Matching uses a trimmed, lowercase **display name**, not a stable user ID or login. A renamed bot can evade this list, and a person choosing a matching display name can be suppressed.

Customizing the ignored list replaces it wholesale. Include the defaults in your value when you want to add one more bot. List parsing accepts either a HOCON list or a comma-separated environment value.

Live and simulated Twitch event cards use protocol-defined TTLs: follows/chat 6 seconds; subs/gifts/Bits and generic kinds 8 seconds; raids and stream transitions 10 seconds. `RELAY_NOTIFICATION_TTL` affects only `POST /api/v1/notifications` when `ttlMs` is omitted. Wire TTL is encoded in deciseconds; see the [protocol](../../twitch-screen-firmware/docs/PROTOCOL.md) for rounding and payload limits.

## Activity and alerts 🚨

| Environment variable | HOCON key | Default | Meaning / constraint |
|---|---|---|---|
| `RELAY_ACTIVITY_BUFFER_SIZE` | `activity.buffer-size` | `500` | 1–65536 retained activity entries |
| `RELAY_ALERT_NO_DEVICES_FOR` | `alerts.no-devices-connected-for` | `2 minutes` | Positive duration before the no-device rule triggers |
| `RELAY_ALERT_TWITCH_DISCONNECTED_FOR` | `alerts.twitch-disconnected-for` | `1 minute` | Positive duration for the Twitch-disconnected rule |
| `RELAY_ALERT_STREAM_OFFLINE_FOR` | `alerts.stream-offline-for` | Unset | Positive duration to enable the offline-stream rule |

Alert evaluation runs every 15 seconds by default. Leaving `RELAY_ALERT_STREAM_OFFLINE_FOR` unset retains the normal behavior: an offline stream alone does not trigger that optional rule. For rules enabled by an application default, merely unsetting the environment variable restores the default; use a HOCON `null` override to disable an optional duration. Zero or a negative duration is invalid.

## Advanced HOCON settings 🧩

These settings have **no explicit environment override** in the shipped file:

| HOCON key | Default | Constraint / purpose |
|---|---|---|
| `device-link.protocol-version` | `3` | Must be exactly 3 |
| `device-link.accept-backlog` | `16` | Positive TCP accept backlog |
| `device-link.handshake-timeout` | `5 seconds` | At least 1 ms to receive the device greeting |
| `device-link.ping-interval` | `20 seconds` | 1–65535 whole seconds; shorter than idle timeout |
| `device-link.outbound-queue-capacity` | `128` | Must hold at least `replay-buffer-size + 18` greeting frames; at most 65553 |
| `device-link.replay-buffer-size` | `64` | 1–65535 retained non-chat notifications; chat has a separate fixed 16-record ring |
| `device-link.max-frame-length` | `256` | Must be exactly 256 bytes, including header |
| `twitch.oauth.refresh-before` | `15 minutes` | Positive lead time for token refresh |
| `twitch.simulation.chat-interval` | `2 seconds` | Positive synthetic-chat interval |
| `bus.subscriber-queue-capacity` | `1024` | 1–65536 entries per consumer |
| `stats.chat-rate-window` | `1 minute` | Positive rolling rate window |
| `alerts.evaluation-interval` | `15 seconds` | Positive rule evaluation cadence |
| `alerts.buffer-size` | `100` | 1–65536 retained alerts |
| `alerts.error-rate-threshold` | `10` | Nonnegative threshold within the error-rate window |
| `alerts.error-rate-window` | `5 minutes` | At least 1 second |
| `observability.log-buffer-size` | `500` | 1–65536 retained log records |

For a standalone JAR, an external HOCON file can include application defaults and override selected keys. For example, save this as `data/relay-local.conf` beneath `twitch-screen-relay/`:

```hocon
include classpath("application.conf")

alerts.no-devices-connected-for = null
observability.log-buffer-size = 1000
```

From that directory, with your authentication environment configured and the assembly built:

```sh
java -Dconfig.file=data/relay-local.conf -jar out/assembly.dest/out.jar
```

This disables the no-device duration rule and retains 1000 log records. Explicit values in the external file override the included values; the environment substitutions still apply to settings you leave inherited. Keep secret values in the configured environment rather than this sample file.

**Unknown keys fail startup.** Every key inside the relay's sections (`http`, `http.auth`, `device-link`, `twitch` and its `oauth`, `event-sub` and `simulation` subsections, `notifications`, `bus`, `stats`, `activity`, `alerts`, `observability`) must be one the relay reads. A misspelled key such as `twitch.client-secert` in `application.conf` or a `-Dconfig.file` source stops startup with `Unknown key` and its full path; every unknown key is listed, not just the first. Upgrade note: earlier versions silently ignored such a key and ran with the intended setting unset, so check any external HOCON file before upgrading. Keys supplied **only** as JVM `-D` system properties are exempt, because the JDK's own `http.proxyHost`, `http.nonProxyHosts`, `http.auth.preference` and similar properties share the `http` namespace. A misspelled relay key passed only as `-D` is therefore ignored without an error; prefer the `RELAY_*` variables or a config file. Keys outside the relay's sections are not checked.

Polling, simulation, aggregation and alert evaluation intervals must be at least 1 ms; statistics and failure-rate windows must be at least 1 second. TCP accept backlog is bounded to 1–1024.

Additional fixed limits in code include 64 simultaneous TCP sessions, 128 HTTP connections, 65536-byte HTTP request bodies, and list `pageSize` values of 1–500. They are not deployment knobs in this version. HTTP connections also have a 30-second decoded-read deadline, including incomplete headers, and each request has a 30-second whole-request deadline from its decoded headers to its final body chunk that a slowly trickled body cannot extend; Tapir bounds response production and idle connections. Non-loopback plaintext HTTP emits a startup warning: use a trusted TLS proxy and restrict direct access.

## OpenTelemetry and JVM options 📊

OpenTelemetry uses standard `OTEL_*` settings independently of the `RELAY_*` tree. Traces, metrics, and logs default to exporter `none`; service name defaults to `twitch-screen-relay`.

| Variable | Typical value | Use |
|---|---|---|
| `OTEL_SERVICE_NAME` | `twitch-screen-relay` | Service identity in your telemetry backend |
| `OTEL_TRACES_EXPORTER` | `otlp` | Enable trace export |
| `OTEL_METRICS_EXPORTER` | `otlp` | Enable metrics export |
| `OTEL_LOGS_EXPORTER` | `otlp` | Enable log export |
| `OTEL_EXPORTER_OTLP_ENDPOINT` | `http://collector:4317` | Reachable collector endpoint |
| `JAVA_OPTS` | `-XX:MaxRAMPercentage=70 -XX:+ExitOnOutOfMemoryError` | Consumed by the Docker entrypoint; not automatically applied by a direct `java -jar` invocation |

The base Compose file forwards only its listed environment keys. Add additional `RELAY_*` or `OTEL_*` values to an override file to pass them into the container. An arbitrary variable in your host shell or Compose `.env` does not become a container variable by itself.

## Verify the effective configuration ✅

```sh
curl --fail --silent --show-error \
  -H "Authorization: Bearer $RELAY_HTTP_AUTH_API_TOKEN" \
  http://localhost:8080/api/v1/config
```

The response is `{"settings":{...}}`, using dotted HOCON keys and string values. The Basic verifier, API token, Twitch client secret, and EventSub secret are replaced by `***`, and so is any key in a relay section that the relay does not read, such as an ignored `-D` system property. The broadcaster token is not part of this configuration endpoint. `/config` is still protected because settings reveal deployment details.

Values such as `"30 seconds"` require shell quoting when assigned on a command line. Durations must be finite; use readable units rather than guessing milliseconds. For malformed settings, the relay fails startup with validation context instead of silently running a partially configured integration.

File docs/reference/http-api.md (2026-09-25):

# 🔌 Relay HTTP API

[Guidebook](../README.md) · [Relay setup](../guides/relay-setup.md) · [Configuration](relay-configuration.md)

Base URL for local development: `http://localhost:8080/api/v1`. Open **`http://localhost:8080/docs`** on the running relay for generated Swagger UI and schemas. The device itself uses binary TCP on port 8099; these HTTP endpoints manage the relay and publish cards.

## Authentication and shared behavior 🔑

Protected requests accept **one** `Authorization` header, using either:

```http
Authorization: Bearer <your-relay-management-token>
```

or HTTP Basic credentials. `curl --user admin` prompts for the plaintext management password. The relay stores a PBKDF2 verifier for Basic login. Twitch's Client Secret and broadcaster access token are separate credentials and cannot authenticate management requests.

Health, aggregate stats, Swagger documentation, and the exact OAuth/EventSub callbacks are public. Callbacks validate their own protocol credentials. Every other route below requires management authentication. Basic password verification permits two concurrent checks; excess checks receive `503` and can retry. Bearer authentication does not use that budget. Only `401` includes `WWW-Authenticate`. Cross-site browser requests using Basic credentials can receive `403`; use the relay directly in the address bar and preserve the public Host header through an HTTPS proxy.

| Contract | Behavior |
|---|---|
| Error body | JSON object with an `error` string, including ordinary route/decode errors |
| Diagnostic list query | Notifications, activity, logs, and alerts accept `pageSize` from **1 to 500**, newest first. Devices and alert rules are unpaged. |
| List envelopes | Named arrays such as `devices`, `notifications`, `entries`, `alerts`, or `records` |
| Enum casing | Most management enums use names such as `Live`, `Offline`, `Warning`, `Info`; notification kinds use lowercase JSON names |
| HTTP body limit | **65536 bytes**, including chunked requests |
| Persistence | Diagnostic lists and replay history are in memory and reset on restart |
| Delivery | A successful publication does not prove a device displayed the card |

## Route map 🗺️

All paths in this table are relative to `/api/v1`.

| Method | Path | Access | Result |
|---|---|---|---|
| `GET` | `/health` | Public | HTTP liveness |
| `GET` | `/stats` | Public | Latest aggregate stream stats sent to devices |
| `GET` | `/status` | Management | Integration readiness, device/bus/buffer counts |
| `GET` | `/config` | Management | Effective configuration with secrets masked |
| `GET` | `/devices` | Management | All current device connections |
| `GET` | `/devices/{connection}` | Management | One current connection |
| `POST` | `/devices/{connection}:disconnect` | Management | Close one connection; return its snapshot |
| `GET` | `/notifications` | Management | Retained notification records |
| `POST` | `/notifications` | Management | Publish one card to all attached devices |
| `GET` | `/activity` | Management | Recent activity records |
| `POST` | `/activity:export` | Management | Plain-text activity report download |
| `GET` | `/alerts` | Management | Raised alert records |
| `GET` | `/alertRules` | Management | Configured rules |
| `POST` | `/alerts/{id}:acknowledge` | Management | Acknowledge an active alert |
| `GET` | `/logs` | Management | Buffered application log records |
| `GET` | `/twitch/authorize` | Management; live mode | `302` redirect to Twitch consent |
| `GET` | `/twitch/callback` | OAuth state; live mode | HTML consent success/failure page |
| `GET` | `/twitch/authorization` | Management; live mode | Held grant's identity, scopes, and expiry |
| `DELETE` | `/twitch/authorization` | Management; live mode | Forget grant and attempt Twitch revocation |
| `POST` | `/twitch/eventsub` | Twitch HMAC; live webhook mode | EventSub challenge or delivery response |

Disabled/simulated modes do not mount the Twitch OAuth routes. The EventSub callback also requires webhook transport. A `404` for one of these routes can therefore be a mode mismatch.

## Send a card 💌

Use the same token as the running relay:

```sh
curl --fail --silent --show-error \
  -H "Authorization: Bearer $RELAY_HTTP_AUTH_API_TOKEN" \
  -H 'Content-Type: application/json' \
  --data '{"type":"info","title":"Desk check","body":"The tiny screen has entered the chat.","ttlMs":8000}' \
  http://localhost:8080/api/v1/notifications
```

HTTP `200` returns the assigned replay record. Example shape, with illustrative sequence/time:

```json
{
  "seq": 1,
  "id": "ntf-0001",
  "type": "info",
  "title": "Desk check",
  "body": "The tiny screen has entered the chat.",
  "at": "2026-09-25T12:00:00Z",
  "ttlMs": 8000
}
```

| Input field | Required? | Contract |
|---|---|---|
| `type` | Yes | Notification JSON kind; see the compatibility note below |
| `title` | Yes | Nonblank after trimming; at most 4096 characters |
| `body` | Yes | May be empty; at most 4096 characters |
| `ttlMs` | No | Integer 1–6553500; omitted uses `RELAY_NOTIFICATION_TTL` |

Useful kinds are `info`, `message`, `warning`, `alert`, `follow`, `sub`, `gift`, `raid`, `chat`, and `bits`. Text can be shortened when encoded for the 240 × 240 display. This endpoint posts a generic card; it does not expose all native Twitch event metadata such as a subscription tier or gift count.

> [!IMPORTANT]
> **Existing stream-kind compatibility issue:** the generated schema advertises `stream_start` and `stream_end`, but the current JSON codec accepts and emits `streamstart` and `streamend`. The underscored spellings return `400`. Prefer the ordinary kinds above for integrations; binary TSB/3 stream event codes are unaffected. This behavior was checked against the local assembly and the [JSON codec](../../twitch-screen-relay/src/twitchscreen/relay/http/ApiJson.scala).

Every accepted POST creates a **new** notification. Retrying after an interrupted response can create a duplicate; there is no idempotency key. The response confirms publication and retention in the current process, including when no device is attached. It does not confirm rendering on a screen.

HTTP `503` with `{"error": "TSB/3 sequence space exhausted (§10.1); …"}` means the relay has assigned the last `u32` sequence number, 4294967295. The relay never wraps the sequence, so it publishes nothing more until it is restarted. A restart begins a new sequence space, and devices re-baseline on it. The relay reports this once: an error log line and one `device-hub failed` relay failure, which appears in the activity log and the failure metrics. `GET /status` then reports `deviceLink.sequenceExhausted: true`. Retrying the POST does not help.

Read recent cards:

```sh
curl --fail --silent --show-error \
  -H "Authorization: Bearer $RELAY_HTTP_AUTH_API_TOKEN" \
  'http://localhost:8080/api/v1/notifications?pageSize=20'
```

Notifications with no known source timestamp omit `at`; they no longer claim the Unix epoch. Locally published cards have a timestamp.

The default `pageSize` is 20. The response combines the two replay rings: up to 64 non-chat notifications by default and a separate fixed 16 chat notifications. Requesting 500 does not create a longer history.

## Health, readiness, and stats 🩺

`GET /health` returns:

```json
{"status":"Up"}
```

It only establishes that the HTTP server can respond. Docker's health check uses it so a Twitch outage does not restart a relay that can still serve devices.

`GET /stats` returns `state`, `viewers`, `followers`, `subscribers`, `uptimeSeconds`, and `chatRate`. `state` is `Live` or `Offline`; `chatRate` is messages per minute. This HTTP DTO is a subset of the full TSB/3 STATS payload; it does not expose `messagesTotal` or `streamStartedAt`.

`GET /status` is the operator's readiness snapshot:

| Field | What to inspect |
|---|---|
| `version`, `startedAt`, `uptimeSeconds` | Running version and process lifetime |
| `twitch` | `mode`, `health`, `channel`, `detail` |
| `deviceLink` | Connected devices, accepted connections, `connectionsRefused` (connections closed at the 64-session limit, pending handshakes included; also exported as the `relay.device.connections.refused` metric; a rising value means too many devices, or a connection leak or flood), published notifications, latest sequence, replay count, and `sequenceExhausted` (true once the `u32` sequence space is spent; restart the relay) |
| `subscribers` | Internal event-bus subscriber statistics: per subscriber `name`, `enqueued`, `delivered` and `dropped` |
| `activityEntries`, `activeAlerts`, `bufferedLogRecords` | Current in-memory diagnostic counts |

Twitch health may be `Disabled`, `Connecting`, `Connected`, `Degraded`, or `Disconnected`. Read the detail with it; HTTP can be healthy while the broadcaster grant is missing. The status route reads a nonblocking hub snapshot and does not convert every degraded condition into a failing HTTP status. For each subscriber, `enqueued` counts events accepted into its queue, `delivered` counts handler calls that have finished (a failed call counts too), and `dropped` counts events lost to a full queue. `enqueued - delivered` is the current backlog, including an event whose handler is still running. Repeated failures update an open alert’s message without reopening or unacknowledging it.

## Inspect and reconnect a device 📡

```sh
curl --fail --silent --show-error \
  -H "Authorization: Bearer $RELAY_HTTP_AUTH_API_TOKEN" \
  http://localhost:8080/api/v1/devices
```

The `devices` array includes numeric `connection`, firmware `device` identity, `remoteAddress`, `protocolVersion`, `connectedAt`, `baselineSeq`, and a nested `traffic` object. `traffic` contains last-seen timestamps, acknowledged sequence, byte/frame counts, dropped/skipped frame counts, invalid-field counters, and resynchronization counts. Clients using formerly top-level traffic fields must now read them under `traffic`. The listener permits at most 64 sessions, including pending handshakes.

Use the current **connection number**, not the device name, in per-connection URLs. For example, when the list reports connection 7:

```sh
curl --fail --silent --show-error \
  -H "Authorization: Bearer $RELAY_HTTP_AUTH_API_TOKEN" \
  http://localhost:8080/api/v1/devices/7

curl --fail --silent --show-error --request POST \
  -H "Authorization: Bearer $RELAY_HTTP_AUTH_API_TOKEN" \
  http://localhost:8080/api/v1/devices/7:disconnect
```

Disconnect drains accepted frames, sends a final operator-disconnect BYE, closes the socket, and returns its snapshot. It does not permanently block a device; firmware reconnects on its backoff schedule. A stale connection number returns `404`. This is useful for checking reconnect behavior while retained replay remains available.

## Activity, logs, and alerts 🧾

| Endpoint | Query parameters | Defaults |
|---|---|---|
| `GET /activity` | `pageSize`, optional `category` | 100, all categories |
| `POST /activity:export` | `pageSize`, optional `category` | 100, all categories |
| `GET /logs` | `pageSize`, `minLevel` | 100, `Info` |
| `GET /alerts` | `pageSize`, optional `severity`, `activeOnly` | 50, all severities, `false` |

Activity categories are `Channel`, `Audience`, `Twitch`, `Device`, `Notification`, and `Failure`. Log levels are `Trace`, `Debug`, `Info`, `Warn`, and `Error`. Alert severities are `Warning` and `Critical`. Query values are case-sensitive enum names.

```sh
curl --fail --silent --show-error \
  -H "Authorization: Bearer $RELAY_HTTP_AUTH_API_TOKEN" \
  'http://localhost:8080/api/v1/logs?minLevel=Warn&pageSize=50'

curl --fail --silent --show-error \
  -H "Authorization: Bearer $RELAY_HTTP_AUTH_API_TOKEN" \
  'http://localhost:8080/api/v1/alerts?activeOnly=true'

curl --fail --silent --show-error --request POST \
  -H "Authorization: Bearer $RELAY_HTTP_AUTH_API_TOKEN" \
  --output relay-activity.txt \
  'http://localhost:8080/api/v1/activity:export?category=Device&pageSize=100'
```

The report returns plain text with download filename `relay-activity.txt`. Review its contents before sharing; activity and logs can contain channel or device details.

`GET /alertRules` returns rule names, severity, and descriptions. Acknowledging an active alert uses its numeric ID:

```sh
curl --fail --silent --show-error --request POST \
  -H "Authorization: Bearer $RELAY_HTTP_AUTH_API_TOKEN" \
  http://localhost:8080/api/v1/alerts/3:acknowledge
```

Replace 3 with an active alert ID from your list. An unknown ID returns `404`; an alert that is no longer active returns `409`. Acknowledgement stops it counting as active; it does not fix its cause. States are `Active`, `Acknowledged`, and `Resolved`. Rules are configured at startup, not edited through HTTP.
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

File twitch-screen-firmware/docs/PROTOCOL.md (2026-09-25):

# TSB/3 — Twitch Screen Binary Protocol, version 3

**Status: normative.** This document is the complete and only specification of the wire
protocol spoken between the relay (`twitch-screen-relay`, Scala 3) and the device
(`twitch-screen-firmware`, ESP32) over the persistent TCP link on port **8099**.

The two implementations are written independently from this document. Anything this
document does not pin down is a defect in this document, not a licence to choose.
MUST / MUST NOT / SHOULD / MAY carry RFC 2119 force.

## 0. What this replaces

* **This supersedes NDJSON protocol v2** in every respect. v2 and v3 peers cannot
  interoperate and MUST NOT try: a v2 peer's first byte is `{` (`0x7b`), which fails this
  protocol's frame magic immediately, and a v3 peer's first byte is `0xa7`, which is not
  legal UTF-8 start-of-text. The v2→v3 cutover is a flag day: flash the device and restart
  the relay together. It is the last one (§16).
* `demo-server/twitch_server.py` speaks NDJSON v2 and is therefore **obsolete**. Do not
  update it, do not test against it, and do not treat its behaviour as normative for
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

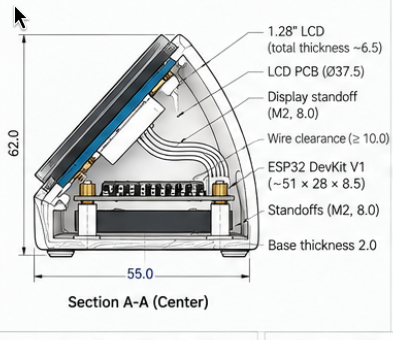
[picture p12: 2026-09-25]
twitch-screen-cad-design/refs/concepts/screenshot_2026-09-25_06-08-40.png

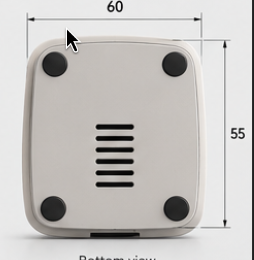
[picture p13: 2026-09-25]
twitch-screen-cad-design/refs/concepts/screenshot_2026-09-25_06-09-10.png

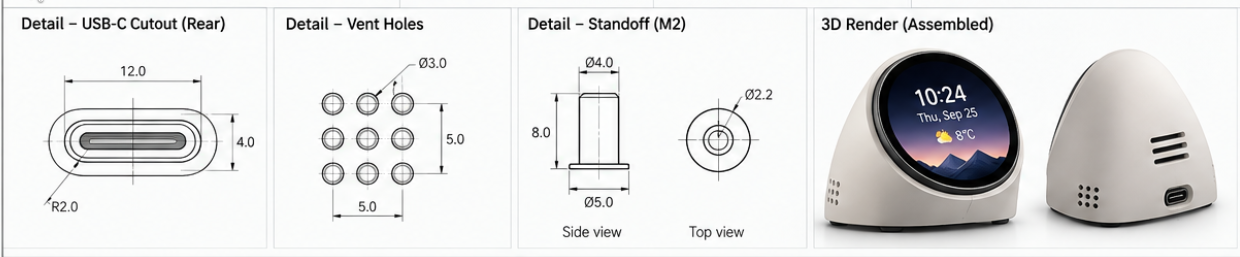
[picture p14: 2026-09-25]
twitch-screen-cad-design/refs/concepts/screenshot_2026-09-25_06-08-21.png

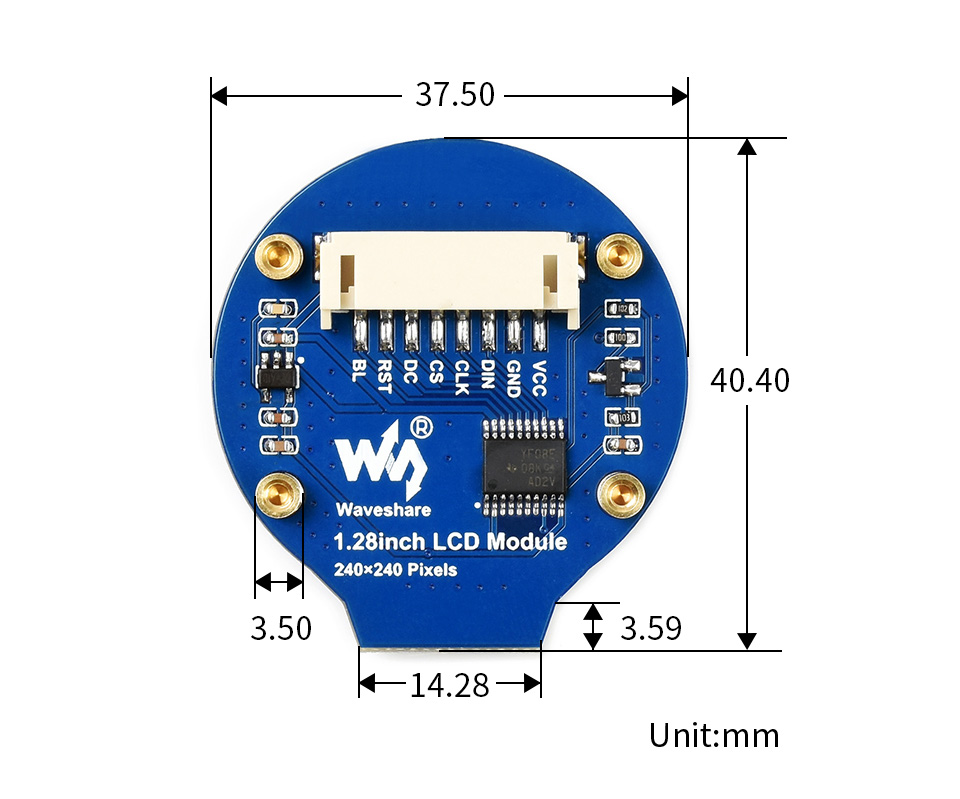
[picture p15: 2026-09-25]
twitch-screen-cad-design/refs/datasheets/waveshare_dimensions.jpg

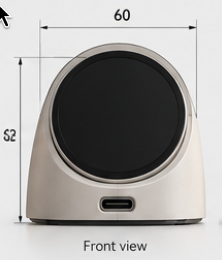
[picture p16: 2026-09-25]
twitch-screen-cad-design/refs/concepts/screenshot_2026-09-25_06-09-02.png

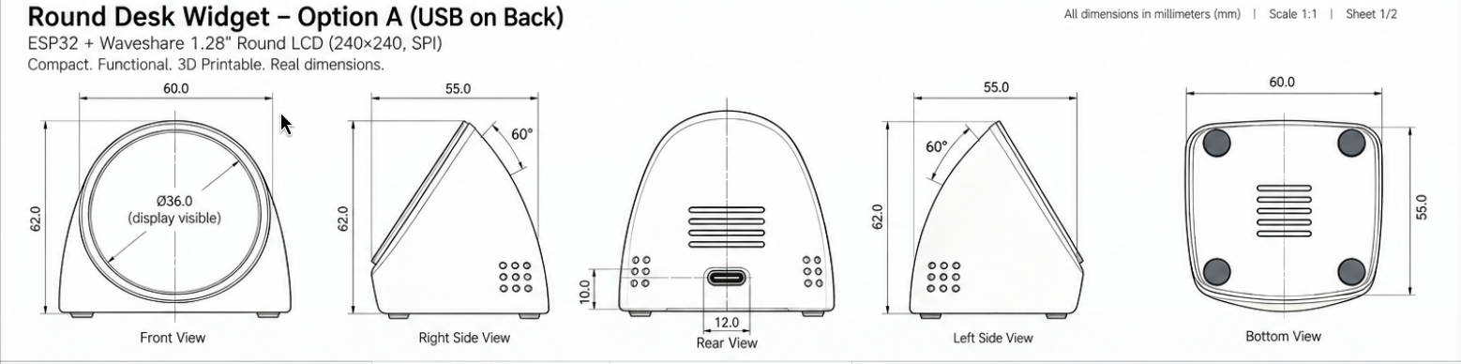
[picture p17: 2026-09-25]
twitch-screen-cad-design/refs/concepts/screenshot_2026-09-25_06-08-08.png

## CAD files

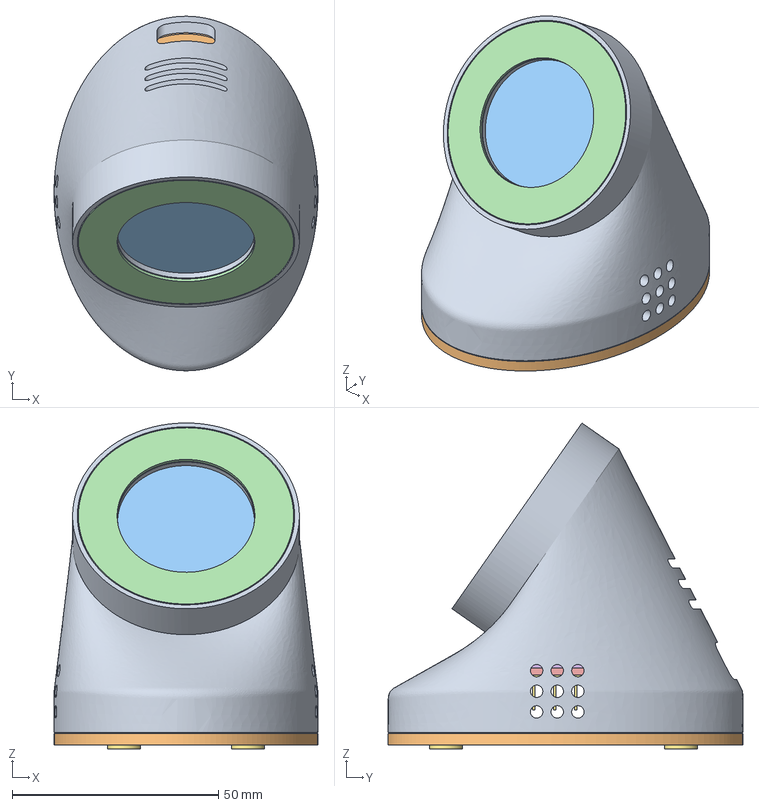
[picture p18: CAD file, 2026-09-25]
twitch-screen-cad-design/output/3mf/TwitchScreen_assembly_view_only.3mf
64.0 x 86.0 x 79.1 mm
base
lcd_retainer
face_bezel
esp32_pcb
esp32_shield
esp32_headers
usb_socket
buttons
lcd_pcb
lcd_glass
lcd_connector
lcd_brass_mounts
cable_route
rubber_feet

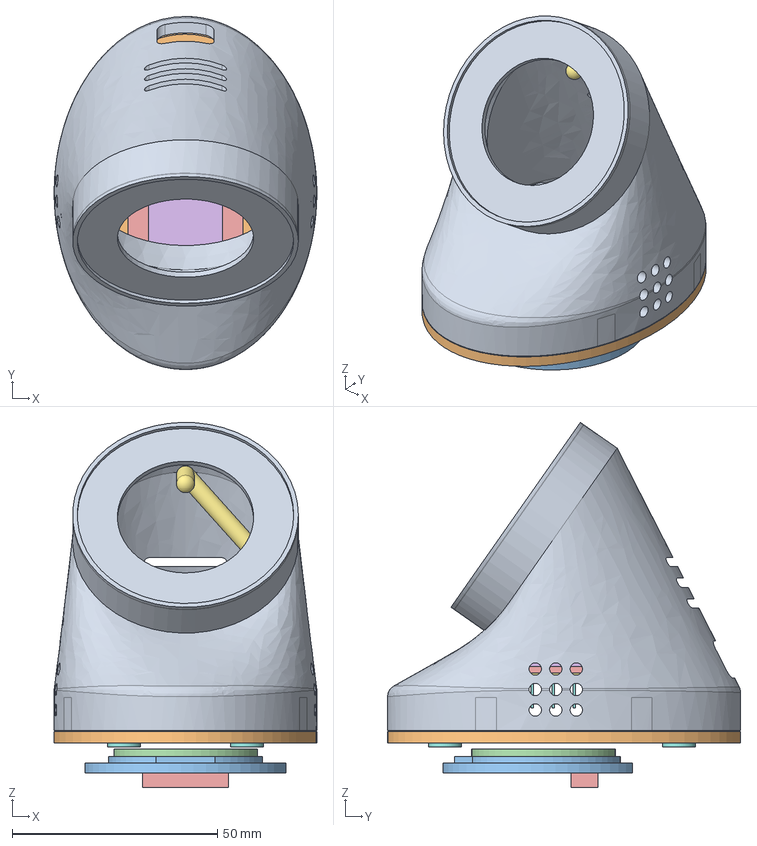
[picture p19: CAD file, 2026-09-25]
twitch-screen-cad-design/output/step/TwitchScreen_assembly.step
64.0 x 86.0 x 89.0 mm
Base
Lcd Retainer
Face Bezel
Esp32 Pcb (reference)
Esp32 Shield (reference)
Esp32 Headers (reference)
Usb Socket (reference)
Buttons (reference)
Lcd Pcb (reference)
Lcd Glass (reference)
Lcd Connector (reference)
Lcd Brass Mounts (reference)
Cable Route (reference)
Rubber Feet (reference)

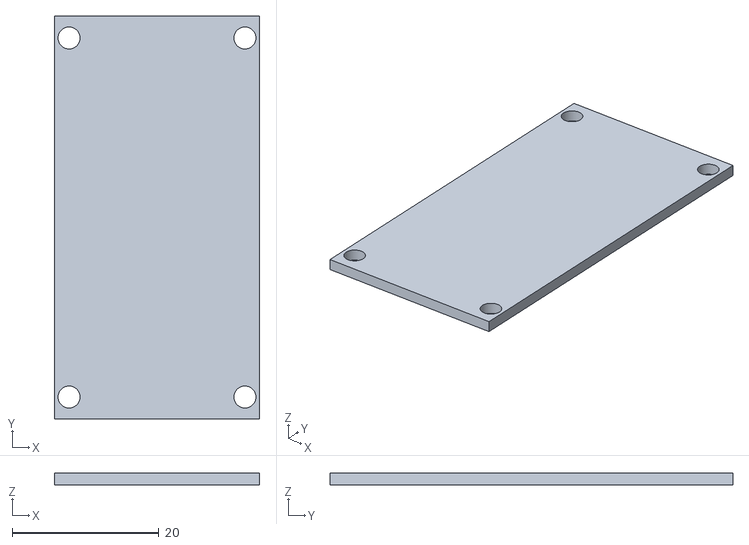
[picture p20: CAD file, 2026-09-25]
twitch-screen-cad-design/output/render_meshes/esp32_pcb.stl
28.0 x 55.0 x 1.60

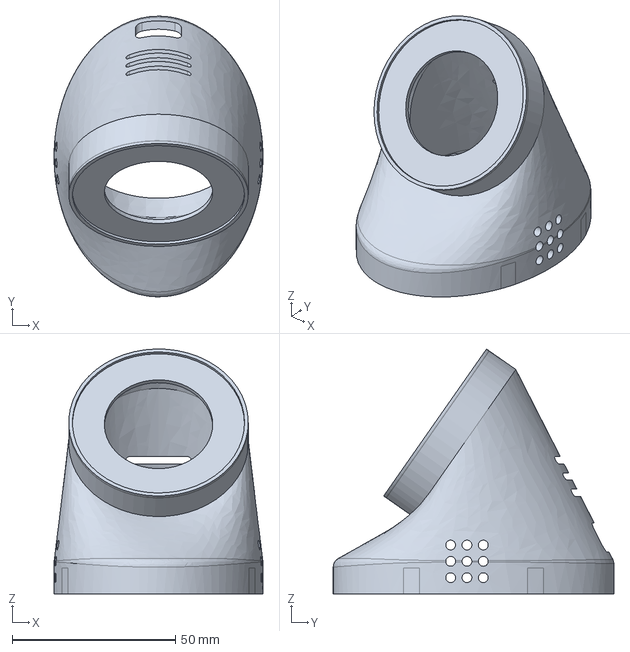
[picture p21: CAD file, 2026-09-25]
twitch-screen-cad-design/output/step/shell.step
64.0 x 86.0 x 75.1 mm

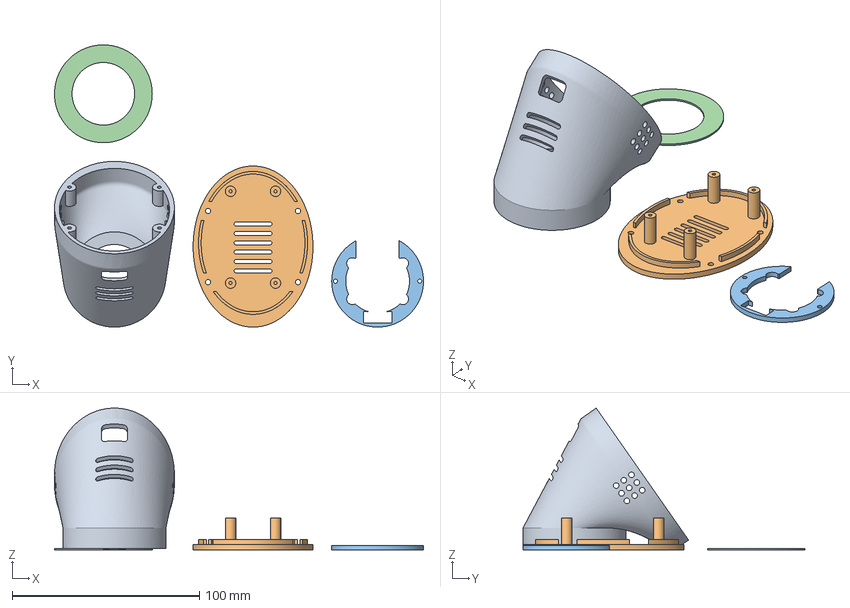
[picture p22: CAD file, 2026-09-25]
twitch-screen-cad-design/output/3mf/print_plate.3mf
197.0 x 150.6 x 75.7 mm
base
lcd_retainer
face_bezel

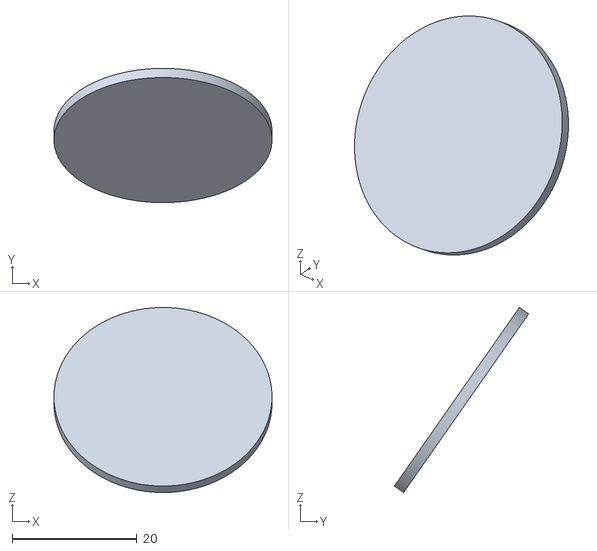
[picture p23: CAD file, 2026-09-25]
twitch-screen-cad-design/output/render_meshes/lcd_glass.stl
35.0 x 21.5 x 29.7

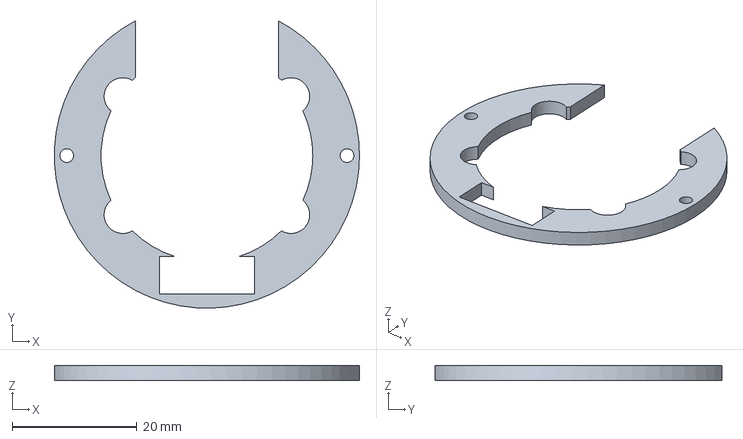
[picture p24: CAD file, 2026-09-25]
twitch-screen-cad-design/output/step/lcd_retainer.step
49.0 x 46.1 x 2.40 mm

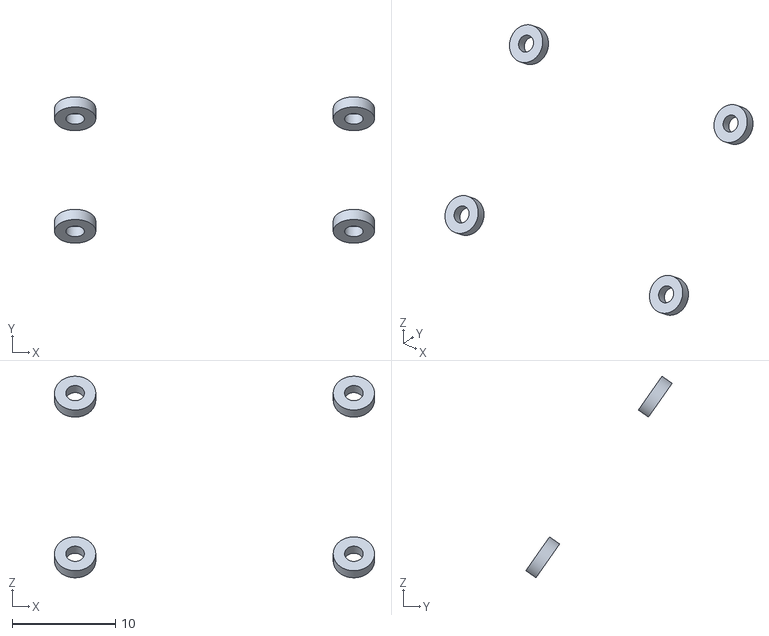
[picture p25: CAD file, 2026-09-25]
twitch-screen-cad-design/output/render_meshes/lcd_brass_mounts.stl
31.0 x 14.2 x 19.5

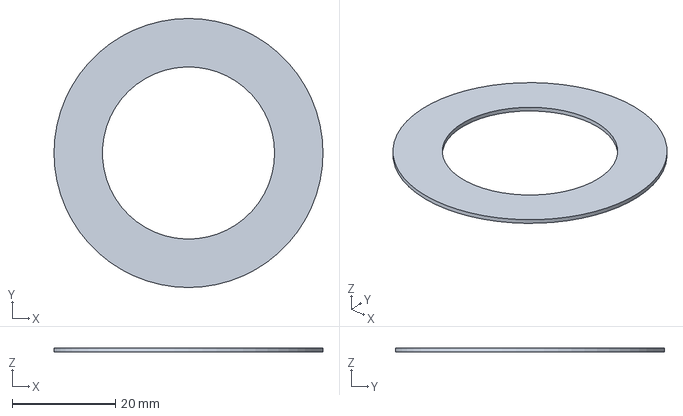
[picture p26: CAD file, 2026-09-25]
twitch-screen-cad-design/output/step/face_bezel.step
52.2 x 52.2 x 0.8 mm

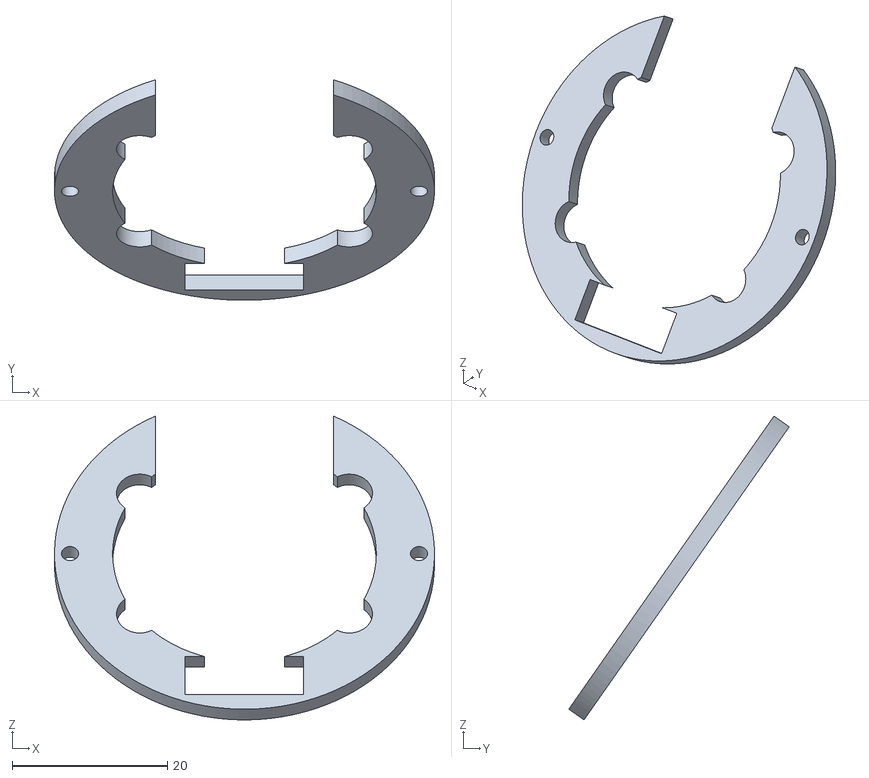
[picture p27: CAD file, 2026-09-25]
twitch-screen-cad-design/output/render_meshes/lcd_retainer.stl
49.0 x 28.4 x 39.2

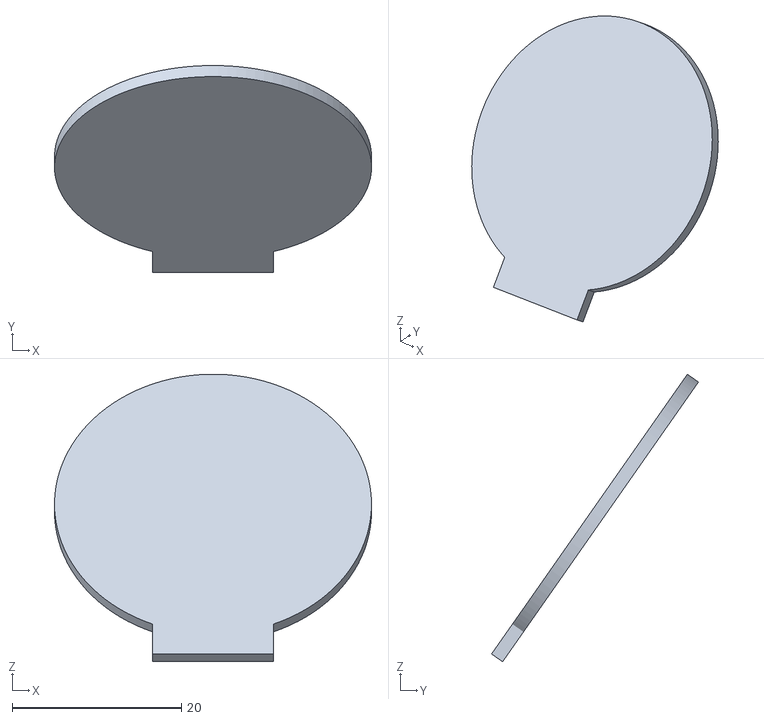
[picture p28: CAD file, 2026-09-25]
twitch-screen-cad-design/output/render_meshes/lcd_pcb.stl
37.5 x 24.5 x 34.0

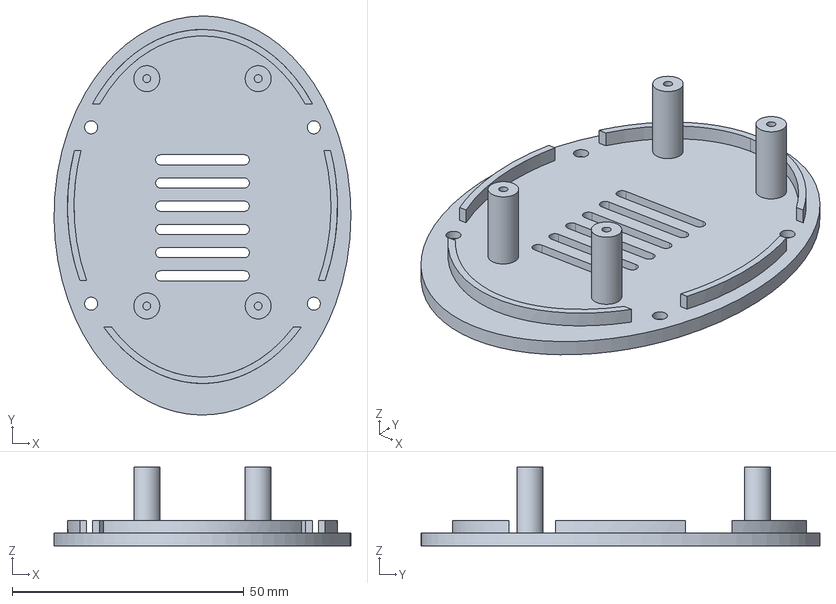
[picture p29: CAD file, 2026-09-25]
twitch-screen-cad-design/output/step/base.step
64.0 x 86.0 x 17.0 mm

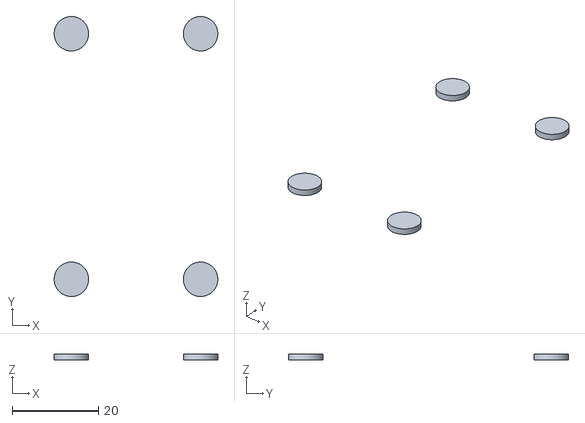
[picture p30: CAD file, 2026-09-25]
twitch-screen-cad-design/output/render_meshes/rubber_feet.stl
38.0 x 65.0 x 1.50

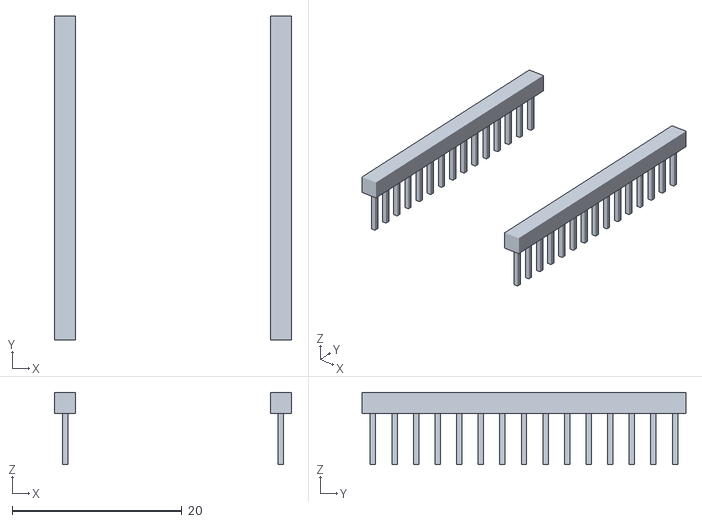
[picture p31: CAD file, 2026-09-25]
twitch-screen-cad-design/output/render_meshes/esp32_headers.stl
27.9 x 38.1 x 8.50

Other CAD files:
twitch-screen-cad-design/output/freecad/TwitchScreen.FCStd
twitch-screen-cad-design/output/render_meshes/shell.stl
twitch-screen-cad-design/output/render_meshes/usb_socket.stl
twitch-screen-cad-design/output/render_meshes/esp32_shield.stl
twitch-screen-cad-design/output/3mf/base.3mf
twitch-screen-cad-design/output/3mf/face_bezel.3mf
twitch-screen-cad-design/output/3mf/lcd_retainer.3mf
twitch-screen-cad-design/output/3mf/shell.3mf
twitch-screen-cad-design/output/freecad/base.FCStd
twitch-screen-cad-design/output/freecad/face_bezel.FCStd
twitch-screen-cad-design/output/freecad/lcd_retainer.FCStd
twitch-screen-cad-design/output/freecad/shell.FCStd
twitch-screen-cad-design/output/preview/TwitchScreen.blend
twitch-screen-cad-design/output/render_meshes/base.stl
twitch-screen-cad-design/output/render_meshes/buttons.stl
twitch-screen-cad-design/output/render_meshes/cable_route.stl
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

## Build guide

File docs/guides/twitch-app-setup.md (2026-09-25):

# 🎮 Connect your Twitch channel

[Guidebook](../README.md) · [Relay setup](relay-setup.md) · [Configuration reference](../reference/relay-configuration.md)

Turn your desk display into a little witness to your stream's main-character moments. This guide registers your Twitch application, connects the **broadcaster's account**, and checks that the relay can receive real events.

Start with a working [simulated stream](first-simulated-stream.md). You need a Twitch account, a browser, and a relay host with internet access. No Twitch credentials belong on the ESP32; it only connects to your relay.

> [!NOTE]
> The default setup uses an outbound EventSub **WebSocket**. You do not need to publish a webhook or open a router port to Twitch. The browser still needs to reach the OAuth callback during consent.

## 1. Understand the three credentials 🔑

| Credential | What it unlocks | Where it belongs |
|---|---|---|
| Relay management token or Basic password | Your relay's management API | Your terminal, browser, or deployment secret store |
| Twitch application Client ID and Client Secret | The relay's connection to Twitch | Relay environment only |
| Broadcaster access and refresh tokens | The broadcaster's approved Twitch data | Created by consent; saved by the relay in its token file |

The relay implements Twitch's **authorization code grant**. You start consent on the relay, Twitch redirects your browser back with a code, and the relay exchanges that code for tokens. This is why the Twitch application must support a server-held client secret. Choose **Confidential** if the Developer Console asks for a client type; a Public client is limited to Twitch's device-code flow. [Twitch OAuth documentation](https://dev.twitch.tv/docs/authentication/getting-tokens-oauth/)

## 2. Register the application 📝

1. Verify your Twitch account's email and enable two-factor authentication.
2. Open the [Twitch Developer Console](https://dev.twitch.tv/console/apps), sign in, and choose **Applications → Register Your Application**.
3. Give it a unique name, such as your own variation of `Desk Stream Buddy`.
4. Add this **OAuth Redirect URL**, including its complete path:

   ```text
   http://localhost:8080/api/v1/twitch/callback
   ```

5. Choose the category that best describes your integration. Select **Confidential** if prompted for client type.
6. Complete the verification and create the application.
7. Open **Manage**, copy the **Client ID**, and use **New Secret** to generate the **Client Secret**. Save the secret privately; generating another invalidates the old one.

These are Twitch's registration requirements; console labels can evolve. The [official registration guide](https://dev.twitch.tv/docs/authentication/register-app/) is the current authority.

**The redirect URL is the callback, not `/authorize`.** The scheme, hostname, port, and path you register must match `RELAY_TWITCH_REDIRECT_URL`. There is no trailing slash, query string, or fragment in this project's callback URL.

## 3. Make the browser-to-relay route work 🌐

For a relay running on the same computer as your browser, keep the localhost callback above.

For a headless Linux box or Raspberry Pi, open an SSH tunnel **on the computer running the browser**. Replace `your-user@relay-host` with your SSH destination:

```sh
ssh -N -L 8080:127.0.0.1:8080 your-user@relay-host
```

Keep that terminal open. Your browser's `http://localhost:8080` now reaches port 8080 on the relay host. The callback remains the same, and the ESP32 continues using the relay's LAN address on port 8099.

When local port 8080 is occupied, use a different local tunnel port, then update **both** the registered redirect and `RELAY_TWITCH_REDIRECT_URL` to match. For example, a local tunnel on 18080 needs `http://localhost:18080/api/v1/twitch/callback` even when the relay itself still listens on 8080.

For a hosted relay, use an HTTPS reverse proxy and register `https://your-relay.example/api/v1/twitch/callback`. The relay validates HTTPS callbacks or HTTP loopback callbacks only. A plain `http://192.168.…` callback fails its startup validation. See [network boundaries](relay-setup.md#network-boundaries-and-https-).

## 4. Configure live mode ⚙️

Run these commands from `twitch-screen-relay/`. The placeholders below must be replaced before starting. Use your **channel login**, such as the `yourchannel` in `twitch.tv/yourchannel`; omit `https://`, `@`, and `#`.

```sh
export RELAY_TWITCH_MODE=live
export RELAY_TWITCH_CHANNEL='yourchannel'
export RELAY_TWITCH_CLIENT_ID='replace-with-your-client-id'
export RELAY_TWITCH_CLIENT_SECRET='replace-with-your-client-secret'
export RELAY_TWITCH_REDIRECT_URL='http://localhost:8080/api/v1/twitch/callback'
export RELAY_TWITCH_EVENTSUB_TRANSPORT=websocket
```

Use a private environment file or secret manager for ongoing operation; avoid putting a real secret in shared shell history. [Relay setup](relay-setup.md) explains local environment files and the Docker configuration.

The relay resolves the numeric **broadcaster ID** from the configured login through Twitch's Get Users API. There is no `RELAY_TWITCH_BROADCASTER_ID` setting and no manual account-ID lookup step.

Keep the default scopes:

| Requested scope | How this relay uses it |
|---|---|
| `moderator:read:followers` | Follow EventSub subscription and follower totals |
| `channel:read:subscriptions` | Subscriber totals |

These permissions are described in Twitch's [scope reference](https://dev.twitch.tv/docs/authentication/scopes/). The follow subscription uses the broadcaster ID as both broadcaster and moderator; the broadcaster moderates their own channel. [Follow subscription requirements](https://dev.twitch.tv/docs/eventsub/eventsub-subscription-types/#channel-follow)

The source reads chat anonymously. Subs, gifts, Bits, and raids arrive through that IRC connection; it does **not** subscribe to the corresponding EventSub event types. Adding `bits:read` or chat scopes does not switch transports or create new features.

## 5. Start the relay and grant consent ✅

Management authentication is required before startup. For convenient browser login, generate a Basic password verifier:

```sh
export RELAY_HTTP_AUTH_BASIC_USERNAME='admin'
export RELAY_HTTP_AUTH_BASIC_PASSWORD_HASH="$(python3 tools/hash_management_password.py)"
./mill run
```

The helper prompts twice without echoing the password and requires at least 12 characters. The relay stores a salted verifier, not that password. You can keep a management Bearer token configured too; either method is sufficient.

Open `http://localhost:8080/api/v1/twitch/authorize` directly in the browser address bar. When prompted by the browser, use your **relay Basic credentials**. Then sign in on Twitch as the **same broadcaster named in `RELAY_TWITCH_CHANNEL`** and approve the requested permissions.

The successful callback page says **Twitch connected** and identifies the authorized login. The token is saved automatically. No manual token copy and no firmware rebuild are involved.

> [!TIP]
> Already using Bearer authentication? Request the redirect without following it:
>
> ```sh
> curl --silent --show-error --dump-header - --output /dev/null \
>   -H "Authorization: Bearer $RELAY_HTTP_AUTH_API_TOKEN" \
>   http://localhost:8080/api/v1/twitch/authorize
> ```
>
> Copy the `Location:` value into your browser. It includes a temporary OAuth state value. Keep it private and complete consent within ten minutes. Do not add your relay token to the browser URL.

The relay retains up to 16 pending consent requests. Each state is single-use and expires after ten minutes; restarting the relay also discards pending states. Start a fresh request when the callback reports an unknown or expired request.

## 6. Check the account and event pipeline 🔍

In a second terminal, use Basic authentication; `curl` prompts for the management password:

```sh
curl --fail --silent --show-error --user admin \
  http://localhost:8080/api/v1/twitch/authorization
```

Check that `authorized` is `true`, `login` matches your configured channel, and `missingScopes` is empty. `userId` is the Twitch ID of the consenting account. This endpoint never returns the access or refresh token. `authorized: true` means a token is held; the following readiness check is needed to assess whether the integration is currently usable.

```sh
curl --fail --silent --show-error --user admin \
  http://localhost:8080/api/v1/status
curl --fail --silent --show-error \
  http://localhost:8080/api/v1/stats
```

EventSub notices a new grant on its next maintenance pass, approximately every 30 seconds. Scoped totals update on the configured Helix polling interval, 30 seconds by default. Check `twitch.health` and `twitch.detail` in status; a running HTTP server alone does not establish Twitch readiness.

What to expect:

| Source | Data | Useful observation |
|---|---|---|
| Helix polling | Stream state, viewers, followers, subscribers | Aggregate stats update after a successful poll |
| EventSub | Follows, stream online/offline, channel title/category updates | Activity records reflect incoming events |
| Anonymous IRC | Chat, subscriptions, gifted subs, Bits, raids | IRC must be connected for these notifications |

Chat cards are hidden by default, while chat still contributes to counters. Set `RELAY_CHAT_NOTIFICATIONS=show` and restart to display them. A single harmless manual notification can confirm the relay-to-device path without generating real Twitch activity; see the [HTTP API example](../reference/http-api.md#send-a-card-).

## 7. Keep consent across restarts 💾

The default token file is `data/twitch-token.json`, relative to the relay's working directory. Native runs from `twitch-screen-relay/` keep it beneath that directory. Docker uses `/home/relay/data/twitch-token.json`; the supplied Compose file persists `/home/relay/data` in a named volume.

The token file contains credentials in plaintext JSON. On POSIX filesystems, the relay creates token files with owner-only permissions and replaces them atomically. On other filesystems, set appropriate OS access controls yourself. Keep the directory private, include it only in protected backups, and do not commit it. The relay can keep a grant in memory after a persistence failure, so check logs when consent unexpectedly disappears after a restart.

Maintenance runs every minute, refreshing near expiry and validating at least hourly while the token is not in its refresh window. Twitch requires ongoing validation. [Token validation requirements](https://dev.twitch.tv/docs/authentication/validate-tokens/)

To disconnect the account intentionally:

```sh
curl --silent --show-error --user admin --request DELETE \
  --write-out '\nHTTP %{http_code}\n' \
  http://localhost:8080/api/v1/twitch/authorization
```

HTTP `204` means the relay cleared the in-memory grant and attempted saved-file deletion and revocation at Twitch; `404` means none was held. File-deletion and provider failures are logged; confirm that the saved token file is gone before relying on sign-out across a restart. Reauthorize after changing the broadcaster, application credentials, or requested scopes. Editing the scopes setting cannot add permissions to an existing grant.

## Optional: use EventSub webhooks 📬

Webhooks need a public HTTPS callback on port 443. Twitch must reach it without a browser login challenge. [Twitch webhook requirements](https://dev.twitch.tv/docs/eventsub/handling-webhook-events/)

Configure these settings alongside the live configuration:

```sh
export RELAY_TWITCH_EVENTSUB_TRANSPORT=webhook
export RELAY_TWITCH_EVENTSUB_CALLBACK_URL='https://your-relay.example/api/v1/twitch/eventsub'
export RELAY_TWITCH_EVENTSUB_SECRET="$(openssl rand -hex 32)"
```

Persist the generated secret privately. It must contain 10–100 ASCII characters. The OAuth callback `/api/v1/twitch/callback` and EventSub callback `/api/v1/twitch/eventsub` are separate endpoints with separate purposes.

Keep the raw webhook body and Twitch headers intact through your proxy. The relay verifies HMAC signatures, timestamps, and delivery IDs. Do not put proxy Basic authentication in front of these exact callbacks; management routes still require the relay's authentication. The relay creates and reconciles its own subscriptions; you do not manually register them in the Developer Console. Twitch uses app tokens for webhook subscription management and user tokens for WebSocket subscriptions. [Subscription management](https://dev.twitch.tv/docs/eventsub/manage-subscriptions/)

Changing an EventSub signing secret requires coordinating the existing provider subscriptions too: the current reconciliation finds an enabled subscription by condition and callback and does not compare its hidden signing secret. A fresh callback hostname with the same required path lets the relay create new subscriptions; retire the old subscriptions in your Twitch administration workflow. Simply changing the local secret can make existing deliveries fail HMAC verification.

Webhooks do not replace the IRC connection for subscription, gift, Bits, or raid notifications. When IRC is unavailable, those event types remain unavailable.

## When Twitch says “not today” 🛠️

| Symptom | Check |
|---|---|
| `/authorize` returns `401` | Supply relay management credentials; Twitch credentials do not authenticate this API |
| Twitch rejects the redirect | Compare the registered URL and relay URL character for character |
| Callback cannot connect on a headless host | Keep the SSH tunnel running on the browser's computer |
| Callback state expired | Start at `/authorize` again; do not reuse an old callback URL |
| Wrong account was authorized | Revoke, sign in as the configured broadcaster, and consent again |
| Missing follower/subscriber totals | Inspect `missingScopes`, authorized login, readiness detail, and provider errors |
| `/twitch/authorization` is `404` | These endpoints exist only in `live` mode |
| Follows work but subs/raids do not | Check the anonymous IRC connection; those events are not EventSub subscriptions here |
| Healthy container, disconnected Twitch | Health checks cover HTTP liveness; inspect authenticated `/status` |

The real-account path still needs operator acceptance with actual Twitch credentials and sustained reconnect testing. Source-level and simulated checks cannot prove provider acceptance. Continue with [troubleshooting](troubleshooting.md), [relay operations](relay-setup.md), or [firmware setup](firmware-setup.md).

Source trail: [OAuth implementation](../../twitch-screen-relay/src/twitchscreen/relay/twitch/TwitchAuth.scala), [live source](../../twitch-screen-relay/src/twitchscreen/relay/twitch/LiveTwitchSource.scala), [event routing](../../twitch-screen-relay/src/twitchscreen/relay/twitch/TwitchEventHandlers.scala), and [configuration validation](../../twitch-screen-relay/src/twitchscreen/relay/config/Config.scala). Official Twitch guidance checked on 2026-09-25.

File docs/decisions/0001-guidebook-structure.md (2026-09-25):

# ADR-0001: Organize the guidebook around reader journeys

## Status

Accepted for this documentation revision.

## Date

2026-09-25

## Context

Twitch Screen combines a Scala relay, ESP32 firmware, and a parametric enclosure. The component READMEs hold useful local instructions, but a newcomer also needs a continuous path across tool installation, Twitch registration, networking, wiring, flashing, and daily use. The requested root README needs a visual, friendly introduction without making every visitor read the complete build manual.

## Decision

Use the root README as a visual project overview with real CAD renders, a local simulator quick start, and links by audience. Put the guidebook index at `docs/README.md`, step-by-step material in `docs/guides/`, and configuration/API/architecture material in `docs/reference/`. Keep component READMEs as entry points beside their tools and preserve the existing detailed protocol and CAD records.

Offer one linear, hardware-free simulator tutorial. Put choices such as Docker versus native execution and WebSocket versus webhook operation in task-focused guides. Render everything as ordinary GitHub Markdown. Use emoji and humor in navigation and introductions while keeping identifiers, commands, and troubleshooting precise.

This organization follows the reader needs described by [Diátaxis](https://diataxis.fr/start-here/) and the overview/getting-started/navigation role described in [GitHub’s README guidance](https://docs.github.com/en/repositories/managing-your-repositorys-settings-and-features/customizing-your-repository/about-readmes).

## Alternatives considered

### One exhaustive root README

It keeps everything in one file, but makes first impressions and focused maintenance harder. Readers need different levels of detail. Keep a concise tour and link to complete guides.

### Only component READMEs

It keeps commands near their source, but leaves cross-component tasks without a route map. Retain those READMEs and connect them through the guidebook.

### A new documentation website with sbt/mdoc

A site could add search and compile Scala snippets. This task is documentation-only, the relay already uses Mill, and these guides teach shell workflows rather than a Scala library API. Adding a second build and deployment system would expand the task beyond its need. Use Markdown and validate the existing commands directly.

## Consequences

Readers can enter by goal and progress through the whole build. Repository-relative links work in clones and on branches. CAD imagery stays tied to the checked-in design.

Maintainers must update overview links and focused reference pages together when behavior changes. A documentation review must check command context, defaults, source claims, local links, and rendering. mdoc compilation is not a validation claim for this repository; firmware builds, relay checks, and targeted command walkthroughs remain the relevant evidence.

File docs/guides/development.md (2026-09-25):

# Development and verification

Each project has its own build directory. There is no root build that compiles the relay, firmware, and CAD together. Use the root-level Python checks to verify shared contracts, and use the component tools for compilation and tests.

For a first run, follow [your first simulated stream](first-simulated-stream.md). For the system model and ownership boundaries, read [architecture](../reference/architecture.md).

## Checkout and prerequisites

```sh
git clone https://github.com/worxbend/twitch-screen.git
cd twitch-screen
```

The first command creates the checkout; the second enters the repository root used by the root-level commands below. Existing checkouts can start there directly.

| Work | Tools | Version source |
|---|---|---|
| Relay | JDK 25 on `PATH`, bundled `./mill` launcher, and internet for initial toolchain and dependency downloads | [build.mill](../../twitch-screen-relay/build.mill): Mill 1.1.9, Temurin JDK 25, Scala 3.9.0. |
| Firmware and native suites | Python 3, PlatformIO 6.1.18; a host C++ compiler for native tests | [platformio.ini](../../twitch-screen-firmware/platformio.ini) pins platform and library versions. CI uses Python 3.13 on Ubuntu 24.04. |
| Root checks | Python 3 standard library; dependency audit also uses Mill and reaches OSV | [tools/](../../tools). |
| Container checks | Docker Engine and Docker CLI; Compose for the supplied deployment file | [Dockerfile](../../twitch-screen-relay/Dockerfile), [compose.yaml](../../twitch-screen-relay/compose.yaml). |
| CAD regeneration | FreeCAD 1.1.3, Blender 5.2, `uv` for mesh-check dependencies | [CAD README](../../twitch-screen-cad-design/README.md) and scripts. |
| Firmware image asset regeneration | Python with Pillow | [make_glitch.py](../../twitch-screen-firmware/tools/make_glitch.py). |

These are the repository's configured or recorded tool versions, not a recommendation to substitute the newest available release. The first Mill or PlatformIO run downloads dependencies. Native checks can run without a connected board; ESP32 compilation needs a local credentials header, but it does not contact Wi-Fi or flash hardware.

Install JDK 25 using [Adoptium's installation guide](https://adoptium.net/installation), then confirm the runtime selected by your shell:

```sh
java -version
```

The command should report major version **25**. The bundled launcher downloads Mill 1.1.9 and the configured Temurin JDK 25; on older Linux systems it uses a JVM launcher that needs an existing Java installation to bootstrap. The checked-in launcher selects its Linux native binary only when it detects glibc 2.39 or newer. See [Mill's launcher requirements](https://mill-build.org/mill/cli/installation-ide.html#_mill_native_and_jvm_executables) for the distinction between native and JVM launchers.

Create the isolated PlatformIO environment from the repository root:

```sh
python3 -m venv .venv-pio
.venv-pio/bin/python -m pip install platformio==6.1.18
```

The first line creates an ignored environment; the second installs the same PlatformIO version used in CI. The firmware commands below use its explicit path so they do not depend on an unrelated global installation.

## Choose the check that proves the change

| Change | First checks | Additional evidence when relevant |
|---|---|---|
| Relay logic or HTTP behavior | Relevant MUnit suite, relay compilation, formatting check | Full relay suite before integration; simulated runtime for visible behavior. |
| TSB/3 bytes or semantics | Golden-vector drift check, relay protocol suites, firmware native suites | Real-socket relay suites, native sanitizer suite, ESP32 compilation. |
| Firmware parser, queue, or session | Native suite and native sanitizer suite | ESP32 compilation; authorized device observations for Wi-Fi and timing. |
| Display layout, colors, or assets | Presentation tests and ESP32 compilation | Physical GC9A01 rendering; host tests do not prove it. |
| Dependency or container change | Dependency audit, relay tests, Docker build and smoke | Real workload sizing beyond the smoke's 512 MiB limit. |
| Enclosure geometry or parameters | Export and all CAD geometry/mesh/assembly/wall checks | Inspect previews and slicer output, then measure the actual parts. |
| Documentation | Verify commands against their implementation and check relative links | Run the demonstrated local path when practical; distinguish observed results from examples. |

Run PlatformIO commands sequentially because they share package and build state. Prefer a focused suite while developing, then the relevant integration gates once the change is ready.

## Relay commands

Run these in `twitch-screen-relay/`:

| Command | Purpose |
|---|---|
| `./mill compile` | Compile application code with warnings treated as errors. |
| `./mill test` | Run the full MUnit suite, including real-socket device tests. |
| `./mill test.testOnly twitchscreen.relay.http.ApiSuite` | Run one named suite; replace the class with the relevant test. |
| `./mill mill.scalalib.scalafmt/checkFormatAll` | Check Scala formatting without changing files. |
| `./mill mill.scalalib.scalafmt/` | Format Scala sources; review the resulting diff. |
| `./mill run` | Run using the current environment and HOCON defaults. Management credentials are required. |
| `./mill --no-server run` | Run without a persistent Mill server, used by the local tutorial. |
| `./mill assembly` | Produce the application assembly used by the container build. |
| `./mill show resolvedRunMvnDeps` | Print resolved runtime artifacts for dependency inspection or auditing. |
| `./mill resolve _` | List available build targets when discovering a task. |
| `./mill inspect compile` | Inspect a particular build target. |
| `python3 tools/hash_management_password.py` | Prompt for a management password and emit its PBKDF2 verifier. |

The compiler enables `-Werror`, `-deprecation`, `-feature`, `-Wunused:all`, `-Wvalue-discard`, and `-Wnonunit-statement`. Scalafmt and MUnit are configured. Scalafix and WartRemover are not installed as build gates; skill guidance about them does not make them active checks.

Useful focused suites include:

| Area | Suite |
|---|---|
| Golden protocol bytes | `twitchscreen.relay.protocol.Tsb3GoldenVectorSuite` |
| Framing and partial input | `twitchscreen.relay.protocol.FrameReaderSuite` |
| Protocol field boundaries | `twitchscreen.relay.protocol.ProtocolBoundarySuite` |
| Real TCP sessions | `twitchscreen.relay.device.DeviceLinkSuite` |
| Slow-device behavior | `twitchscreen.relay.device.DeviceBackpressureSuite` |
| Lifecycle event/statistics ordering | `twitchscreen.relay.device.LifecycleOrderingSuite` |
| Application shutdown | `twitchscreen.relay.device.ApplicationShutdownSuite` |
| Management authentication | `twitchscreen.relay.http.ManagementAuthSuite` and `ManagementRoutesSuite` in the same package |
| Twitch recovery adapters | `twitchscreen.relay.twitch.TwitchRecoverySuite` |
| Webhook signatures and duplicate delivery | `twitchscreen.relay.twitch.EventSubWebhookSuite` and `WebhookDeduplicationSuite` in the same package |
| Configuration validation | `twitchscreen.relay.config.ConfigSuite` |

The test sources under [relay/test/src](../../twitch-screen-relay/test/src/twitchscreen/relay) are the full inventory. A scripted Twitch adapter test does not validate provider acceptance of a real account's application or grant.

For an interactive local relay, configure credentials and choose the simulated source:

```sh
export RELAY_HTTP_AUTH_API_TOKEN="$(openssl rand -hex 32)"
RELAY_TWITCH_MODE=simulated ./mill run
```

The first line creates a management token in the shell; the second selects the simulator for this run. The default listeners bind to all interfaces on ports 8080 and 8099. Use the [local tutorial](first-simulated-stream.md) for loopback-only operation or [relay setup](relay-setup.md) for LAN and persistent settings. Stop the foreground process with Ctrl+C.

New endpoint groups belong to their feature package, extend `ServerEndpoints`, use the synchronous `.handle` or `.handleSuccess` API, and are collected through [Apis.scala](../../twitch-screen-relay/src/twitchscreen/relay/Apis.scala). Select the appropriate management, public, or callback endpoint base in `Http`; unclassified endpoints fail assembly. Update documentation when an endpoint's input, output, access, or failure behavior changes.

## Firmware commands

Run these in `twitch-screen-firmware/`, after creating the root `.venv-pio` environment:

| Command | Purpose |
|---|---|
| `../.venv-pio/bin/pio test -e native` | Compile and run host tests for the codec, wire handling, link session, presentation, and deterministic parser fuzz cases. |
| `../.venv-pio/bin/pio test -e native -f test_link_session` | Run a single test directory while working on link behavior. |
| `../.venv-pio/bin/pio test -e native-sanitized` | Run native suites with AddressSanitizer and UndefinedBehaviorSanitizer; this is the Linux host gate used in CI. |
| `../.venv-pio/bin/pio run -e esp32dev` | Compile the ESP32 application. |
| `../.venv-pio/bin/pio run -e esp32dev -t upload` | Flash a connected board over USB; select the intended device before running. |
| `../.venv-pio/bin/pio device list` | List detected serial ports. |
| `../.venv-pio/bin/pio device monitor` | Open the serial monitor at the configured 115200 baud. |

Before the ESP32 build, create the local header only when absent:

```sh
test -f src/credentials.h || cp src/credentials.example.h src/credentials.h
```

`test -f` preserves an existing local configuration; `cp` creates the ignored header from the example only when needed. Set its Wi-Fi credentials and relay LAN address for a real board. CI copies the example into its fresh workspace purely to compile; its placeholder values do not connect a device.

The native build compiles the transport-independent codec and link client with a host compiler. Its custom runner treats a plain test program's exit status as the result. The ESP32 build adds Arduino, TFT_eSPI, LVGL, and the platform transport; application sources use `-Wall -Wextra -Werror`. [Firmware setup](firmware-setup.md) covers wiring configuration, device selection, and upload/monitor use.

`tools/build_version.py` and `tools/sanitizers.py` are PlatformIO build hooks, not standalone Python entry points. The first embeds a short Git revision and a dirty suffix in the firmware version; the second adds the sanitizer linker flags. Run them through their configured PlatformIO environment.

## Shared protocol vectors

The [protocol specification](../../twitch-screen-firmware/docs/PROTOCOL.md) is normative. Its 20 golden vectors are shared with the relay test literals and generated firmware header. From the repository root:

```sh
python3 tools/check_protocol_vectors.py
```

This extracts a fresh firmware header into a temporary directory, compares it with the committed header, and compares the relay's V1–V20 bytes with the specification. Success prints `All 20 TSB/3 vectors match the specification, relay and firmware.` It checks fixture agreement; run both implementations' test suites to verify codec behavior.

After an intentional reviewed change to normative vectors, regenerate the firmware header from `twitch-screen-firmware/`:

```sh
python3 test/test_proto_codec/gen_vectors.py docs/PROTOCOL.md test/test_proto_codec/vectors.h
```

The generator reads the first path and overwrites the second. Review that diff and the corresponding relay fixture changes, then rerun the root drift check and both protocol suites. Do not regenerate fixtures merely to hide an unexplained mismatch.

## Dependency audit

From the repository root:

```sh
python3 -m unittest discover -s tools/tests -v
python3 tools/audit_relay_dependencies.py
```

The first command tests the audit tool. The second resolves the relay's runtime dependencies with Mill, checks them against OSV, and applies the exact reviewed exceptions in [relay_dependency_exceptions.json](../../tools/relay_dependency_exceptions.json).

The audit returns `0` when all findings have valid exceptions, `1` for unexcepted advisories, and `2` when the scan or its inputs are incomplete or invalid. Network failures are not a clean audit. Exception records are constrained to a package, version, advisory, review date, expiry, owner, and reason; expired or stale exceptions fail validation. The currently recorded legacy exceptions expire on 2026-10-25; [the dependency assessment](../../tasks/review-dependencies.md) explains their disposition.

For a reusable input and full JSON report, first run this in the relay directory:

```sh
./mill show resolvedRunMvnDeps > /tmp/twitch-screen-runtime-deps.json
```

This writes the resolved runtime artifact list without starting the application. Then, from the repository root:

```sh
python3 tools/audit_relay_dependencies.py \
  --resolved /tmp/twitch-screen-runtime-deps.json \
  --output /tmp/twitch-screen-dependency-audit.json
```

`--resolved` supplies the saved resolution instead of invoking Mill; `--output` writes the full report. OSV is still queried. `--exceptions PATH` selects a different exception file for an explicitly reviewed audit input; it is not a general ignore switch.

## Container checks

Run from the repository root with a working Docker daemon:

```sh
docker build --check twitch-screen-relay
docker build -t twitch-screen-relay:review twitch-screen-relay
python3 tools/smoke_container.py twitch-screen-relay:review
```

The first command checks Dockerfile build configuration. The second builds the image. The third starts an isolated simulated container with a generated management token, ephemeral loopback ports, and a 512 MiB memory limit. It checks public/protected HTTP, credential redaction, a real TSB/3 `WELCOME`, and `SERVER_SHUTDOWN` BYE followed by EOF after SIGTERM. It removes its container in cleanup. Omitting the image argument uses `twitch-screen-relay:review`.

This smoke does not flash hardware, call live Twitch, or prove memory requirements for a sustained real workload. A healthy container also does not establish that an ESP32 can reach the host's LAN port.

For a persistent local Compose run, use `docker compose up --build` from `twitch-screen-relay/` with management credentials configured. The supplied Compose file selects simulated mode and publishes ports 8080 and 8099. `docker compose down` stops its services; the named token volume persists unless explicitly removed. Deployment configuration is covered in [relay setup](relay-setup.md).

## CAD and generated assets

The exported enclosure is versioned, so inspecting the design does not require regeneration. A geometry change should be followed by the complete pipeline from `twitch-screen-cad-design/`:

```sh
flatpak run --env=QT_QPA_PLATFORM=offscreen --command=FreeCADCmd org.freecad.FreeCAD -c 'import sys; sys.path.insert(0,"scripts"); import export_project; export_project.main()'
uv run --with trimesh --with numpy --with networkx python scripts/verify_exports.py
flatpak run --env=QT_QPA_PLATFORM=offscreen --command=FreeCADCmd org.freecad.FreeCAD -c 'import sys; sys.path.insert(0,"scripts"); import verify_assembly, verify_walls; verify_assembly.main(); verify_walls.main()'
blender -b --threads 8 --python scripts/render_previews.py
python3 scripts/package_project.py
```

- The first line loads the project scripts in FreeCAD and exports the solids, meshes, native documents, and geometry report.
- The second checks the written STL/3MF files using the mesh-analysis dependencies.
- The third runs assembly-clearance/recompute and wall-thickness checks inside FreeCAD.
- The fourth renders the previews using Blender.
- The fifth packages the gallery, manifest, and delivery archive from the generated outputs.

The [CAD README](../../twitch-screen-cad-design/README.md) explains the native FreeCAD command equivalent, output semantics, provisional measurements, and why script locations and filenames must stay stable. `pod_geometry.py`, `pod_document.py`, and `render_settings.py` support the pipeline; they are not additional command-line stages. Interactive recomputation uses the project-root `TwitchScreen.FCMacro` through FreeCAD's Macro menu.

To regenerate the firmware's RGB565 logo assets, use an environment with Pillow and run from `twitch-screen-firmware/`:

```sh
python3 tools/make_glitch.py
```

This overwrites `src/assets/twitch_glitch.h` and the 48- and 84-pixel PNG previews in `assets/`. Review generated image and header changes together. It does not alter the display driver or run a firmware build.

## What CI actually runs

[`.github/workflows/ci.yml`](../../.github/workflows/ci.yml) runs on pushes and pull requests, with independent jobs on Ubuntu 24.04. A newer run for the same workflow/ref cancels the older one.

| Job | Gates |
|---|---|
| `relay` | JDK 25 setup; `./mill compile`; audit-tool unit tests; resolved runtime dependency audit; `./mill test`; Scalafmt check. |
| `protocol` | Golden-vector drift check; Python syntax compilation for CAD scripts, firmware tools, and root tools. |
| `firmware` | Python 3.13 and PlatformIO 6.1.18; native tests; native sanitizer tests; copy example credentials into the fresh checkout; ESP32 compilation. |
| `container` | Docker build configuration check; build `twitch-screen-relay:ci`; run the container smoke against that image. |

The Python syntax gate can be reproduced from the repository root:

```sh
python3 -m compileall -q twitch-screen-cad-design/scripts twitch-screen-firmware/tools tools
```

This compiles Python syntax and writes ignored bytecode caches. It does not import FreeCAD, run Blender, execute PlatformIO hooks, or validate geometry.

CI does **not** run FreeCAD/Blender regeneration, print an enclosure, inspect a physical LCD, upload firmware, or obtain live Twitch consent. There is no configured Markdown/mdoc build. These limits explain why a passing CI run can coexist with an unverified physical fit or live-account setup.

## Keep a reviewable working tree

Run `git status --short` before and after a change. Local `.env` files, Twitch token data, `src/credentials.h`, `.venv-pio`, logs, and build outputs are ignored. Example credentials must remain placeholders. Preserve an existing local credentials header when following setup instructions.

CAD `output/` is intentionally versioned: geometry changes can produce a large but necessary deliverable diff. The generated release gallery, manifest, and ZIP are excluded. Review source, validation reports, and generated outputs together when changing geometry.

Repository-specific agent skills live under [`.agents/skills/`](../../.agents/skills). They document workflows and conventions; they do not replace the configured compiler, tests, or CI gates. Record the commands actually run and distinguish them from checks that require physical hardware or a real Twitch account.

Use [troubleshooting](troubleshooting.md) to investigate a failed stage, and return to the [guidebook](../README.md) for the complete setup path.

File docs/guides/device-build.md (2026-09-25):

# 🛠️ Build your desk companion

[← Guidebook](../README.md) · [Firmware setup →](firmware-setup.md)

This guide takes you from loose boards to a wired, enclosed Twitch screen. Start with the electronics on your desk, prove the display works, then commit to the enclosure. Tiny screen, excellent main-character energy. ✨

**Build status:** the enclosure is a complete nominal CAD design with exported meshes and validation reports. Its print settings, clone-board dimensions and physical fit still need validation on your actual hardware. The renders below show the CAD model; they are not photographs of a finished print.

Exploded CAD render showing the shell, LCD, retaining ring, ESP32 and removable base

## 1. Gather the parts

### Electronics and tools

| Quantity | Part | Match these details |
| --- | --- | --- |
| 1 | ESP32 DevKit V1 Type-C | Classic ESP32/WROOM-32, **30-pin**, two header rows and four mounting holes; compare your board to the [hardware references](../../twitch-screen-cad-design/refs/hardware/) |
| 1 | Waveshare 1.28inch LCD Module | **Non-touch**, 240 × 240, GC9A01, eight-pin SPI connector |
| 1 | Eight-wire LCD cable/loom | Supplied module cable with connections compatible with your ESP32 headers |
| 1 | USB data cable | USB-C at the board end; must carry data for flashing |
| 1 | USB power source | A computer for upload; a suitable USB power supply for desk use |
| 1 | Relay computer | Runs the backend and stays reachable from the ESP32 over the local network |
| — | Basic tools | Calipers, small screwdrivers, flush cutters/support-removal tools, a slicer and access to a 3D printer |

The [Waveshare product page](https://www.waveshare.com/1.28inch-LCD-Module.htm) identifies the intended GC9A01 module and provides the outline drawing. The visible display is 32.4 mm across; the PCB is 37.5 mm wide and 40.4 mm overall with its tab. Similar-looking touch modules and integrated ESP32 display boards use different layouts.

The ESP32 name alone does not establish enclosure compatibility. USB connector position, header depth, hole spacing and PCB outline vary between clones. Use the [measurement checklist](../../twitch-screen-cad-design/docs/measurement_checklist.md) before buying a substitute or printing the complete shell.

### Enclosure hardware

| Quantity | Part | Design assumption |
| --- | --- | --- |
| 1 each | Shell, base, LCD retainer, face bezel | Four printed parts; a dark face bezel gives the render's contrasting front |
| 4 | M2 × 6 mm pan-head screws | ESP32 mounting; nominal head diameter 3.8 mm |
| 4 | M2.5 × 8 mm low-profile pan-head screws | Base closure; head recesses are 5.2 mm diameter × 1.3 mm deep |
| 2 | M2 × 5 mm pan-head screws | LCD retainer to shell |
| 4 | Adhesive rubber feet | 8 mm diameter × approximately 1.5 mm thick |
| — | Double-sided adhesive film | Approximately 0.15 mm thick for the face insert; compatible with the filament |

These screws form threads in the printed pilot holes. The design does not assume heat-set inserts or a particular thread in the LCD's brass mounts. Test the pilot fit in a small printed coupon first.

## 2. Wire the display

Disconnect USB power before changing wires. Follow the **pin labels**, rather than cable colors: a replacement loom may use a different color order.

| LCD pin | ESP32 board label | GPIO / purpose |
| --- | --- | --- |
| VCC | **3V3** | Module power |
| GND | **GND** | Common ground |
| DIN | **D23** | GPIO 23, SPI data/MOSI |
| CLK | **D18** | GPIO 18, SPI clock |
| CS | **D5** | GPIO 5, chip select |
| DC | **RX2** | GPIO 16, data/command |
| RST | **D4** | GPIO 4, display reset |
| BL | **D15** | GPIO 15, backlight |

On the referenced DevKit, `D23` means GPIO 23 and `RX2` means GPIO 16. **RX2 is a GPIO label here; do not substitute RX0.** The firmware owns GPIO 16 as the LCD data/command signal.

Use the project's 3.3 V wiring even though Waveshare also lists a 5 V module supply option. The eight connections above match [platformio.ini](../../twitch-screen-firmware/platformio.ini) and the wiring comment in [main.cpp](../../twitch-screen-firmware/src/main.cpp). There is no MISO connection or touch-controller wiring in this build.

Keep the SPI wires short and make sure each jumper seats fully. The configured SPI clock is 40 MHz. The firmware drives BL high continuously; day/night dimming is not implemented.

## 3. Prove the electronics before printing

Follow [firmware setup](firmware-setup.md), including its **LAN-reachable simulated relay** startup before the first boot. The separate [simulated-stream tutorial](first-simulated-stream.md) is a local learning exercise: stop its loopback-only instance before starting the device's relay. Keep the boards on a nonconductive surface with their undersides clear of loose screws.

Before proceeding, observe:

- A powered screen with a purple connecting animation.
- A working relay connection followed by live/offline telemetry.
- A simulated notification with readable text and the expected color.
- Stable USB power and no reset loop.

This separates a wiring or network problem from a fit problem. Enclosure assembly becomes much easier once you know the electronics work.

## 4. Measure your boards

The nominal enclosure is approximately **64 × 86 × 78.1 mm**, before feet, with its display face tilted **55° from horizontal**. These are assembly dimensions, not the rotated print footprint.

Record your own measurements in a working copy of the [measurement checklist](../../twitch-screen-cad-design/docs/measurement_checklist.md). Pay particular attention to:

- ESP32 outline, four-hole pattern and the height of plugged-in female headers.
- USB socket position and your cable's complete plastic overmould.
- LCD glass thickness, PCB thickness and connector projection with its cable attached.
- The LCD's four brass mounts; the retainer clears them rather than fastening into them.
- Wire bend space and the service loop needed to lower the removable base.

The nominal ESP32 PCB is 55 × 28 × 1.6 mm, with a 24 × 49 mm hole pattern. These values are provisional clone-board assumptions, not a universal DevKit specification.

Update [parameters.json](../../twitch-screen-cad-design/parameters.json) for differences and follow the [CAD rebuild instructions](../../twitch-screen-cad-design/README.md#rebuild-and-verify). Changing a saved FreeCAD document alone does not regenerate the committed STL or 3MF exports.

## 5. Choose and slice the printable files

| Want to print… | Open this |
| --- | --- |
| All four parts on one plate | [print_plate.3mf](../../twitch-screen-cad-design/output/3mf/print_plate.3mf) |
| Main housing | [shell.stl](../../twitch-screen-cad-design/output/stl/shell.stl) |
| Removable underside | [base.stl](../../twitch-screen-cad-design/output/stl/base.stl) |
| LCD retaining ring | [lcd_retainer.stl](../../twitch-screen-cad-design/output/stl/lcd_retainer.stl) |
| Dark front insert | [face_bezel.stl](../../twitch-screen-cad-design/output/stl/face_bezel.stl) |

Individual printable STL and 3MF files already sit on Z = 0 in their intended print orientation. Files named **`assembly_view_only` contain electronics reference bodies and must not be used as print plates**.

The supplied plate occupies approximately **197 × 151 mm**, before brim and support expansion. Check it against your actual bed and slicer margins. Printing parts individually is useful for a smaller bed, separate colors and early fit checks.

### Starting slicer settings

| Setting | Starting point |
| --- | --- |
| Material | PETG |
| Nozzle | 0.4 mm |
| Layer height | 0.2 mm |
| Perimeters | 4 |
| Top/bottom layers | 5 |
| Infill | 20–30% |
| Shell | Face down as exported; inspect supports for internal bosses and USB roof |
| Base | Underside down; posts up |
| Retainer and bezel | Flat as exported |

**This is a starting profile, not a tested print recipe.** Inspect every layer around the LCD seat, posts, vents and rear USB opening. Keep support contact away from the glass seat. A brim may help the shell's narrow first-layer annulus.

Print the base first to check the ESP32 hole pattern. Confirm screw-pilot fit and bezel/glass clearance before committing to the complete enclosure.

## 6. Assemble the enclosure

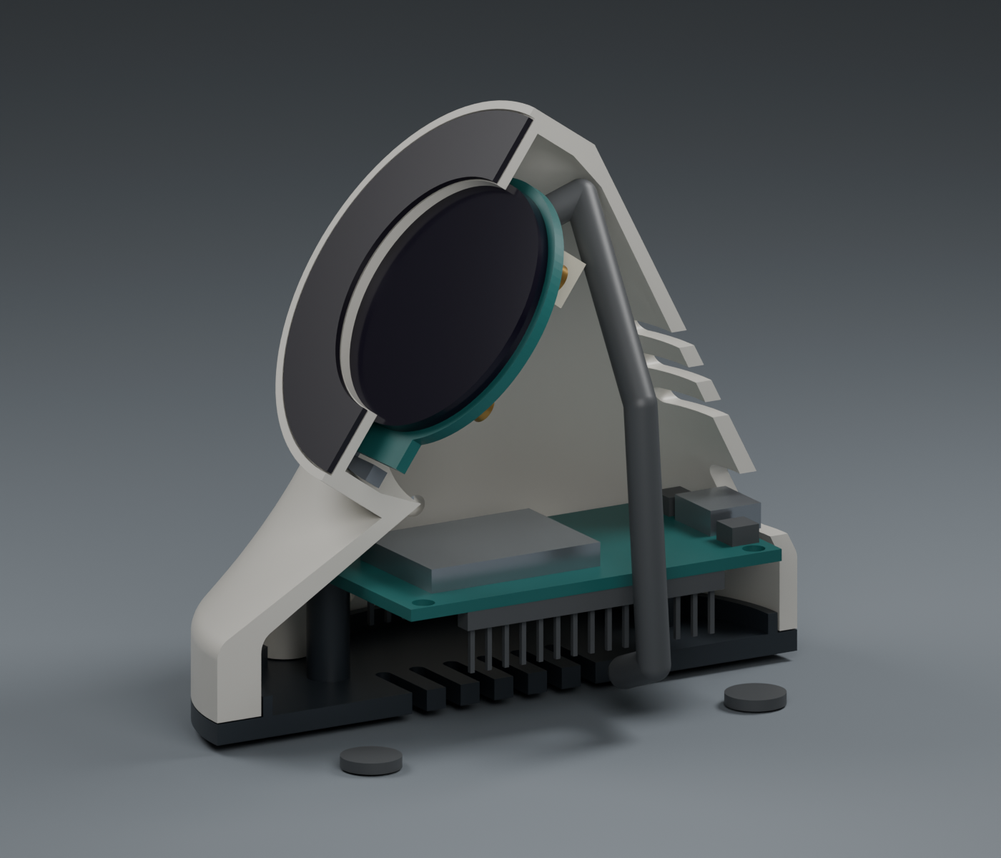
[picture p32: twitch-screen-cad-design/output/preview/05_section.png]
Section CAD render showing internal electronics clearance and the tilted LCD


With power disconnected:

1. Remove supports and loose strands. Check that ventilation slots, locating surfaces and the USB opening are clear.
2. Attach the dark face insert inside the front rim with approximately 0.15 mm adhesive film. Keep adhesive outside the display opening.
3. Remove the display's protective film. Insert the LCD from inside, **tab down and rear connector up**. Check that no printed edge loads the active glass surface.
4. Fit the retainer behind the PCB, matching its connector notch and tab relief. Tighten the two M2 × 5 mm screws lightly and evenly. The retainer holds the PCB perimeter.
5. Mount the ESP32 on the four base posts with the M2 × 6 mm screws. Its **USB-C connector faces the rear**; its PCB antenna faces the front.
6. Reconnect the loom using the wiring table. Route it through the side cavity, away from the glass, screw posts and antenna. Leave enough slack to lower the base before unplugging it.
7. Seat the base locating lip and secure the four M2.5 × 8 mm screws from underneath. Stop if the joint requires force; find the obstruction first.
8. Test USB cable insertion from the rear, then attach the four rubber feet.

The rounded cable body in the render represents a 4.4 mm routing corridor for the eight-wire loom. It does not show individual electrical connections.

## 7. Give it a desk spot

Connect USB, keep the relay running, and repeat the simulated display check after closing the case. Confirm the cable fits without pushing on the PCB and that ventilation remains clear.

EN and BOOT are service buttons on the ESP32 board; access requires removing the base. There are no external screen controls. For daily operation, continue to [using the device](device-use.md). For real channel events, follow [Twitch app setup](twitch-app-setup.md) and [relay setup](relay-setup.md).

## Evidence and design files

- [CAD overview and reproducible export commands](../../twitch-screen-cad-design/README.md)
- [Hardware measurement checklist](../../twitch-screen-cad-design/docs/measurement_checklist.md)
- [Nominal geometry, mesh, assembly and wall reports](../../twitch-screen-cad-design/output/reports/)
- [Mechanical completion audit and its limits](../../twitch-screen-cad-design/docs/completion_audit.md)
- [Troubleshooting](troubleshooting.md)

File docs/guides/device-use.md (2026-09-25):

# 💜 Meet your tiny stream sidekick

[← Guidebook](../README.md) · [Firmware setup](firmware-setup.md) · [Troubleshooting](troubleshooting.md)

Once configured, the device is an automatic display: plug in USB power, keep the relay running and let it do its thing. No app on your phone, no daily pairing ritual. Just a tiny circle doing the most. ✨

The relay computer must stay awake and connected to the network. The ESP32 uses Wi-Fi to reach it; the USB cable supplies power and supports firmware updates/serial diagnostics. Twitch account authorization lives on the relay.

## Understand the three screen states

| Screen | What it means | Your next step |
| --- | --- | --- |
| **CONNECTING…** with purple spinner | The device has not completed its connection to the relay | Wait through a normal restart; investigate Wi-Fi, the relay or its LAN address if it persists |
| **OFFLINE** / “waiting to go live” | The device is connected and the relay's current stream state is offline | Go live or use simulated mode; check relay status if the channel is already live |
| **LIVE** with viewer count | The relay reports a live stream | Enjoy the dashboard; event cards appear automatically |

**OFFLINE is a stream state, not a network error.** A connected display does not by itself prove every Twitch integration is healthy. When data is missing, check the relay's status as described below.

Notification cards appear above the dashboard. Already queued cards can continue to show during a connection interruption, so the connecting screen can be temporarily covered by a card.

## Read the live dashboard

| Element | Meaning |
| --- | --- |
| Red LIVE pill | Relay reports the stream is live |
| `h:mm:ss` timer | Stream uptime; ticks locally every second and is corrected by incoming telemetry |
| Large VIEWERS number | Most recent viewer count delivered by the relay |
| `FLW` chip | Most recently observed total follower count |
| `MSG` chip | Chat messages observed by this relay since the most recent stream-start reset, after configured bot filtering |
| `SUB` chip | Most recently observed total subscriber count |
| Purple edge ring | Chat rate in messages per minute, visually capped at 100 |

The ring is an activity gauge; a full circle means 100 or more messages per minute. It is not a percentage of a follower goal.

Counts use compact `K`, `M` and `B` suffixes to fit the round screen. These are abbreviated display values, not changes to the underlying metrics. For example, 1,234 displays as `1.2K`.

Telemetry is normally broadcast every five seconds. Viewer/follower/subscriber observations can update less often because they depend on upstream polling and permissions. The uptime label still ticks between broadcasts.

On the offline screen, the `FLW`, `MSG` and `SUB` row remains visible. Stream end does not reset the message total; the next stream-start event does. The relay's counters are in memory, so restarting the relay can reset them, and starting it midway through a stream does not backfill earlier chat.

## Meet the notification cards

| Card | Accent | What it carries |
| --- | --- | --- |
| STREAM LIVE | Green | Channel going live |
| STREAM ENDED | Slate | Channel ending, with duration when supplied |
| FOLLOW | Purple | Follower name |
| SUB | Gold | Subscriber, tier and subscription months when available |
| GIFT | Pink | Gifter, quantity and tier when available |
| RAID | Red | Raider and audience size |
| CHAT | Cyan | Chatter and message; message text gets extra space |
| BITS | Light purple | Chatter and Bits amount |
| INFO / MESSAGE / WARNING / ALERT | Kind-specific | Custom notifications published through the relay |

The screen can render these cards when the relay supplies them. Which real Twitch events arrive depends on the relay mode, integrations and account permissions. Cash donations are not a built-in event kind; a third-party integration would need to create a supported generic notification.

Fresh events begin with a full-screen attention flash, then slide in. The relay supplies a hold of **6 seconds for follows and chat**, **8 seconds for subs, gifts and Bits**, and **10 seconds for raids and stream transitions**, plus entrance/exit animation. Manual HTTP cards default to eight seconds unless their request or relay configuration supplies another duration. Chat cards are hidden by the relay's default policy; their messages still count toward chat statistics.

For protocol senders that leave the duration unspecified, the firmware's fallback holds are 2.5 seconds for chat, 5 seconds for stream start/end and 3.5 seconds for other cards. These fallbacks are not the normal durations of cards from this relay.

Replayed cards skip the attention flash but still slide in. The small `#number` is the relay sequence number; it helps diagnose ordering, not viewer count.

Long titles and message bodies end with an ellipsis when they exceed the available space. The current firmware advertises printable-ASCII text support: the relay folds unsupported Unicode instead of promising full emoji or multilingual font coverage. Dark chat-name colors fall back to white for readability.

## Controls, power and settings

This build has **no touch input, navigation menu, notification-dismiss button, brightness control or on-device Wi-Fi setup**. The non-touch LCD and firmware operate as an always-on display.

The board's service buttons are:

- **EN/reset:** restart the ESP32.
- **BOOT:** used with reset/upload to enter the serial bootloader; it is not a screen control.

In the enclosure, remove the base to reach them. For ordinary use, connect or disconnect USB power. Give the relay computer a reliable network connection and keep it awake while streaming.

To change Wi-Fi, relay address or a custom device name, edit the private firmware configuration and [reflash over USB](firmware-setup.md). To change Twitch channel, grants or bot filtering, follow [relay setup](relay-setup.md) and [Twitch app setup](twitch-app-setup.md).

## What happens when the connection drops?

The firmware keeps trying automatically. Its retry delay grows from roughly one second to a 30-second base delay, with jitter; a relay-requested retry floor can extend that. A stable connection eventually resets the retry ramp.

Reconnection can replay retained notifications when the device still holds a usable sequence position. The default relay retention is **64 non-chat events plus 16 chat events**. This is bounded, in-memory recovery, not a durable notification archive.

Practical limits:

- Turning the device off or resetting it clears its replay position. A fresh boot starts from the relay's current sequence instead of requesting old cards.
- Restarting the relay loses its in-memory replay history and can reset its sequence space.
- A long or busy outage can exceed the retained history.
- A queued event is acknowledged before it has necessarily finished displaying.
- Retained replay has no age cutoff, so a recovered card can refer to an earlier stream.

The firmware queue holds eight waiting notifications and pauses incoming event consumption when full. A burst therefore takes time to display. This device is for awareness on your desk; Twitch's own dashboard remains the place to inspect a complete event history.

## Check the relay from your computer

From a shell with the same management token used to start the relay:

```sh
curl --fail-with-body http://127.0.0.1:8080/api/v1/status \
  -H "Authorization: Bearer $RELAY_HTTP_AUTH_API_TOKEN"
curl --fail-with-body http://127.0.0.1:8080/api/v1/devices \
  -H "Authorization: Bearer $RELAY_HTTP_AUTH_API_TOKEN"
```

The first request reports integration and relay readiness; the second lists connected device sessions and counters. An empty device list means the display has not registered a current connection. Basic-auth installations can use the Basic credentials described in [relay setup](relay-setup.md).

The public `/api/v1/health` endpoint checks that the relay process serves HTTP. It intentionally does not prove Twitch is connected. The built-in API documentation is at `http://127.0.0.1:8080/docs`.

## Your first-stream checklist

- [ ] The relay runs on a computer that will remain awake.
- [ ] The screen reaches OFFLINE or LIVE after power-up.
- [ ] A simulated or manual notification has displayed successfully.
- [ ] The correct Twitch channel is configured and the required authorization is granted.
- [ ] Relay status has no unexplained degraded integration.
- [ ] The real stream produces the expected LIVE state and updates.

For setup from scratch, start with [your first simulated stream](first-simulated-stream.md). For a screen that gets stuck, continue to [troubleshooting](troubleshooting.md).

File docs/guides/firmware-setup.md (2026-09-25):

# ⚡ Configure, build and flash the firmware

[← Guidebook](../README.md) · [Build the device](device-build.md) · [Use the device →](device-use.md)

This guide installs the firmware on the classic ESP32 DevKit V1 with the Waveshare GC9A01 LCD. **Flashing** writes the program to the ESP32. Configuration is compiled into that program, so changing Wi-Fi or the relay address requires rebuilding and uploading.

The commands below use a Linux/macOS-style shell from the repository root unless a step changes directory. The native sanitizer target is configured for Linux. Windows command-path differences are listed below; a Windows hardware run is not established by these instructions.

## 1. Check the prerequisites

- [Wire the LCD](device-build.md#2-wire-the-display) and connect the ESP32 with a USB **data** cable.
- Install Git, OpenSSL and Python 3 with virtual-environment support. Debian/Ubuntu may need `python3-venv`; PlatformIO's [Python installation notes](https://docs.platformio.org/en/latest/faq/install-python.html) cover OS differences.
- For native tests, install a host C++ compiler/toolchain. The cross compiler for the ESP32 is downloaded by PlatformIO.
- Have a 2.4 GHz Wi-Fi network and a computer reachable from it to run the relay. The classic WROOM-32 uses the 2.4 GHz band; see [Espressif's module datasheet](https://documentation.espressif.com/esp32-wroom-32_datasheet_en.html).
- The [simulated-stream tutorial](first-simulated-stream.md) is a useful introduction, but its loopback-only listener cannot accept a physical ESP32. A Twitch application is not required for this first device check.

### Start a relay the physical device can reach

Finish and stop any earlier tutorial instance first, using its shutdown step, so ports 8080 and 8099 are free. In a **separate terminal starting at the repository root**, launch this simulated relay:

```sh
cd twitch-screen-relay
export RELAY_HTTP_AUTH_API_TOKEN="$(openssl rand -hex 32)"
RELAY_HTTP_HOST=127.0.0.1 RELAY_HTTP_PORT=8080 \
  RELAY_DEVICE_HOST=0.0.0.0 RELAY_DEVICE_PORT=8099 \
  RELAY_TWITCH_MODE=simulated ./mill run
```

This keeps management HTTP on the relay computer while accepting device TCP connections on its network interfaces. Use a trusted LAN and allow TCP 8099 through the host firewall. The `0.0.0.0` listener address is **not** the address to put in the firmware: `SERVER_HOST` must be this computer's actual LAN address.

Wait for `Device link listening on 0.0.0.0:8099` and `Management API on http://127.0.0.1:8080/docs` in the startup log. **Leave this terminal running through the upload and first-boot check.** Continue the remaining commands in another terminal at the repository root. Stop the relay with Ctrl+C when finished. For an existing configured backend, use its reachable device listener instead; [relay setup](relay-setup.md) explains persistent deployment.

## 2. Install the project's PlatformIO version

From the repository root:

```sh
python3 -m venv .venv-pio
.venv-pio/bin/python -m pip install platformio==6.1.18
.venv-pio/bin/pio --version
```

The final command should identify PlatformIO Core 6.1.18. Keep the explicit virtual-environment paths in subsequent commands; shell activation is unnecessary.

The project uses an isolated, pinned environment for reproducibility. PlatformIO's [installation guide](https://docs.platformio.org/en/latest/core/installation/) describes its general installer options. Avoid installing the project toolchain into your system Python, and run PlatformIO commands **sequentially** because they share a package store.

The first build downloads the pinned ESP32 platform, framework, toolchain and libraries. Allow network access and time for that initial setup.

### Windows path equivalents

In PowerShell, use `py -3 -m venv .venv-pio`, then `.\.venv-pio\Scripts\python.exe` and `.\.venv-pio\Scripts\pio.exe`. From the firmware directory, use `..\.venv-pio\Scripts\pio.exe`. A serial port might be `COM3` instead of `/dev/ttyUSB0`. Use a native Windows USB driver appropriate to the board's actual USB-to-serial chip; do not assume every Type-C clone uses the same one.

## 3. Create the private configuration

Enter the firmware directory and copy the template **only when the private file does not already exist**:

```sh
cd twitch-screen-firmware
if [ ! -e src/credentials.h ]; then
  cp src/credentials.example.h src/credentials.h
fi
```

Open `src/credentials.h` in your editor and replace its placeholders:

```cpp
#pragma once

#define WIFI_SSID "your-2.4ghz-network"
#define WIFI_PASSWORD "your-wifi-password"
#define SERVER_HOST "192.168.1.100"
#define SERVER_PORT 8099
#define DEVICE_ID ""
```

| Setting | What to enter |
| --- | --- |
| `WIFI_SSID` | Exact network name, including case |
| `WIFI_PASSWORD` | Wi-Fi password; escape quotes/backslashes correctly in a C++ string |
| `SERVER_HOST` | Relay computer's LAN IPv4 address or a hostname resolvable by the ESP32; no `http://`, path or port suffix |
| `SERVER_PORT` | Relay device TCP port, normally `8099` |
| `DEVICE_ID` | Leave empty for the automatic identity, or choose a unique readable name |

`127.0.0.1` and `localhost` mean **the ESP32 itself** when used by its firmware. `0.0.0.0` is a server bind address, not the address a device should connect to. Use the relay computer's actual LAN address and reserve it in your router if possible.

Port **8099 is the device link**. Port **8080 is the HTTP management API**. They speak different protocols and cannot be interchanged. Allow the device TCP connection through the host firewall on your trusted LAN; guest Wi-Fi client isolation can prevent it even when both machines have Internet access.

The TCP device connection has no application authentication or encryption. Keep it on a trusted network. Twitch client secrets and management API tokens belong in the relay configuration, not in this header.

### Device identity

An empty `DEVICE_ID` produces `lcd-<chip MAC>` automatically, making it unique per physical ESP32. A custom identity must be **1–31 printable ASCII bytes**, nonblank and unique among connected devices. Use a short value such as `desk-lcd-01`. Longer configured strings are truncated by the firmware and can collide.

Two devices claiming the same identity replace one another at the relay and log `BYE code=9` (`REPLACED`). Leaving the default empty value avoids this common setup trap.

`src/credentials.h` is ignored by Git. Keep it private and preserve it during updates. The compiled firmware also contains these values: treat the resulting firmware binary as private configuration material.

## 4. Verify and compile

Run these from `twitch-screen-firmware/`, one at a time:

```sh
../.venv-pio/bin/pio test -e native
../.venv-pio/bin/pio run -e esp32dev
```

On Linux, also run the sanitizer gate:

```sh
../.venv-pio/bin/pio test -e native-sanitized
```

The `native` target tests codec, session, queue and presentation behavior on the computer. `native-sanitized` repeats the host suites with AddressSanitizer and UndefinedBehaviorSanitizer on Linux. `esp32dev` compiles the actual firmware. Successful commands end with passing test/build results; a firmware build writes `.pio/build/esp32dev/firmware.bin`.

From the repository root, also check the shared protocol fixtures:

```sh
python3 tools/check_protocol_vectors.py
```

These checks establish software behavior and buildability. Physical rendering, wire integrity and recovery during a real Wi-Fi outage need observation on the device.

### What is pinned

The authoritative settings live in [platformio.ini](../../twitch-screen-firmware/platformio.ini):

| Item | Project setting |
| --- | --- |
| Board / framework | `esp32dev` / Arduino |
| ESP32 platform | `espressif32 @ 7.1.2` |
| Arduino framework package | `4.20017.260907+sha.dcc1105b` |
| TFT_eSPI | `2.5.43` |
| LVGL | `9.6.0` |
| Partition layout | `huge_app.csv` |
| LCD SPI clock | 40 MHz |
| Upload / monitor speeds | 460800 / 115200 baud |

The display driver and GPIO mapping are configured by build flags. There is no library `User_Setup.h` to edit. USB upload is the supported update path; this firmware does not implement OTA provisioning or updates.

## 5. Select the serial port

With the board connected, from `twitch-screen-firmware/`:

```sh
../.venv-pio/bin/pio device list
```

Identify the port that belongs to the ESP32. Linux often uses `/dev/ttyUSB0` or `/dev/ttyACM0`, macOS often uses `/dev/cu.*`, and Windows uses `COM` names. Substitute your real port in the commands below.

On Linux, a permission error is usually a host-device access problem. Follow PlatformIO's [udev/group-membership instructions](https://docs.platformio.org/en/stable/core/installation/udev-rules.html), reconnect the board and, when group membership changes, log out and back in. Run your normal build as your own user.

Close any existing serial monitor before uploading so it releases the port.

## 6. Upload

This command writes to the connected ESP32:

```sh
../.venv-pio/bin/pio run -e esp32dev -t upload --upload-port /dev/ttyUSB0
```

When only one board is attached, PlatformIO can usually autodetect the port and the `--upload-port` argument can be omitted. Keep it explicit when several boards are connected.

If upload remains at `Connecting…`, hold the board's **BOOT** button during the upload connection attempt. If necessary, hold BOOT, briefly press EN/reset, and release BOOT once the tool starts writing. Espressif documents this GPIO0-at-reset behavior in [boot mode selection](https://docs.espressif.com/projects/esptool/en/latest/esp32/advanced-topics/boot-mode-selection.html). After a successful write, reset normally without holding BOOT.

Do not erase flash as a routine fix: normal upload already replaces the program. Check cable, port, access permissions and boot mode first.

## 7. Watch the first boot

```sh
../.venv-pio/bin/pio device monitor --port /dev/ttyUSB0 --baud 115200
```

Press EN/reset after opening the monitor to see startup. Look for these source-defined log fragments; numbers and ordering around network events vary:

```text
[app] reset reason=...
[display] synchronous RGB565 buffer=19200 B
[link] connecting...
[link] connected
[link] hello sent, last_seq=0 caps=0x07
[link] welcomed: ...
```

The display first renders **CONNECTING**, then shows the relay's current live/offline state. Simulated mode produces cards without Twitch credentials. A failed connection logs a reason and retries automatically.

Use `Ctrl+C` to leave the monitor. Follow [troubleshooting](troubleshooting.md) if there is no display, no serial port or no `welcomed` message.

## 8. Update an existing device

1. Preserve your ignored `src/credentials.h` and note the currently working firmware commit.
2. Update the repository and read any protocol/configuration changes.
3. Repeat the host checks and ESP32 build.
4. Close the serial monitor, upload over USB and observe startup again.
5. Check a notification, display colors, text fit and reconnection behavior on the physical device.

Firmware and relay must agree on **TSB/3**. The retired NDJSON demo cannot talk to this build. Power cycling clears the firmware's in-memory replay position; it is not a way to recover old notifications.

Continue with [daily use](device-use.md), [relay configuration](relay-setup.md) and [Twitch app registration](twitch-app-setup.md).

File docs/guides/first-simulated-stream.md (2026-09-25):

---
id: first-simulated-stream
title: "Your first simulated stream"
description: "Run the relay locally and learn how simulated Twitch events become statistics and display notifications."
keywords:
  - "Twitch simulator"
  - "TSB/3"
  - "Relay"
  - "Notifications"
---

# Your first simulated stream

Welcome! This tutorial is for someone who can run commands in a terminal and wants to understand what the relay does before wiring a display or registering a Twitch application. You do not need an ESP32, Twitch account, Docker, or Scala knowledge.

By the end, you will understand how to:

- Start a local stream simulation without Twitch credentials.
- Distinguish public health information from protected management information.
- Observe the difference between stream statistics and notification cards.
- Publish a card and identify where an ESP32 joins the pipeline.

We will start the relay, inspect it, watch its figures change, send a card, and stop it. Read from top to bottom. You will use one terminal for the relay and a second for requests.

## Before you start

Use a Linux or macOS terminal with Git, `curl`, OpenSSL, Python 3, and JDK 25 available on `PATH`. Follow [Adoptium's installation guide](https://adoptium.net/installation) to install Java, then check the selected version:

```sh
java -version
```

- `java -version` reports the Java runtime selected by this terminal. Confirm that the reported major version is **25** before continuing.

The bundled launcher downloads Mill 1.1.9 and the configured Temurin JDK 25; on older Linux systems it uses a JVM launcher that needs an existing Java installation to bootstrap. Allow internet access and time for the first toolchain and dependency downloads. Ports 8080 and 8099 must be free on this machine.

This walkthrough uses the repository defaults except for binding both listeners to your own computer. It creates an ignored `.env.tutorial` file in the relay directory for a temporary management token.

## Get the checkout

The existing relay is the runnable example; no separate Scala example module is needed. Start a fresh checkout in **terminal 1**:

```sh
git clone https://github.com/worxbend/twitch-screen.git
cd twitch-screen/twitch-screen-relay
```

- `git clone` downloads the project into `twitch-screen`.
- `cd` goes straight into the relay module where the tutorial commands run. An existing checkout can begin at this same directory.

The [development guide](development.md) lists the build and verification commands for this example and the existing [container smoke companion](../../tools/smoke_container.py).

## 1. Start the source of events

The relay normally takes observations from Twitch. In `simulated` mode, a fixed script supplies those observations to the same downstream code. Let's start it in terminal 1 and leave it running.

```sh
test -f .env.tutorial || (umask 077; openssl rand -hex 32 > .env.tutorial)
export RELAY_HTTP_AUTH_API_TOKEN="$(cat .env.tutorial)"
RELAY_HTTP_HOST=127.0.0.1 RELAY_DEVICE_HOST=127.0.0.1 \
  RELAY_TWITCH_MODE=simulated ./mill --no-server run
```

- `test` preserves a token file from an earlier tutorial run. When it is absent, the parenthesized command creates a random token with owner-only permissions; `umask` applies only inside those parentheses.
- `export` reads that token into the shell environment for the relay. It is separate from a Twitch token. The file contains only the token, and its contents are not executed as shell commands.
- `RELAY_HTTP_HOST` and `RELAY_DEVICE_HOST` bind the HTTP and device listeners to loopback for this local exercise.
- `RELAY_TWITCH_MODE=simulated` selects the scripted source. `./mill --no-server run` starts the application without a persistent Mill server and displays its logs in this terminal.

Look for log messages containing:

```text
Simulating Twitch for 'simulated-channel': an audience event every 12 seconds
Device link listening on 127.0.0.1:8099 (protocol v3, max 64 sessions)
Management API on http://127.0.0.1:8080/docs
```

Timestamps, thread names, and the API's endpoint count surround these messages. A download or compilation phase may precede them. A configuration error or `Address already in use` means startup has failed; resolve the message using [troubleshooting](troubleshooting.md) before continuing. Missing management credentials are a startup error even in simulated mode.

## 2. Ask whether the relay is running

Health tells you that the process can serve HTTP. Status tells you what the relay is doing, and requires the management token. Open **terminal 2**, navigate to this checkout's `twitch-screen-relay` directory, and read the same temporary credential:

```sh
export RELAY_HTTP_AUTH_API_TOKEN="$(cat .env.tutorial)"
```

- `export` reads the token created in terminal 1. Shell variables are not shared between terminals, so this step gives the request client the same credential as the relay.

Keep terminal 2 in that directory for the remaining HTTP steps:

```sh
curl -fsS http://127.0.0.1:8080/api/v1/health
curl -sS -i http://127.0.0.1:8080/api/v1/status
curl -fsS -H "Authorization: Bearer $RELAY_HTTP_AUTH_API_TOKEN" \
  http://127.0.0.1:8080/api/v1/status | python3 -m json.tool
```

- The first request reads public liveness information. `-f` makes HTTP errors fail the command; `-sS` hides progress while keeping error messages.
- The second request deliberately omits credentials. `-i` includes the response headers so you can see its HTTP status.
- The third request supplies the token in the `Authorization` header. The continuation line selects the endpoint, and `python3 -m json.tool` formats its JSON response.

The health response is `{"status":"Up"}`. The request without credentials returns **401** with `{"error":"Invalid management credentials"}`. The authenticated response returns **200**, with `twitch.mode` equal to `Simulated`, `twitch.health` equal to `Connected`, and `deviceLink.connectedDevices` equal to `0`.

Notice that `Connected` describes the simulated source. The detail says `synthetic events, no Twitch connection`; no contact with Twitch is needed. A healthy relay can also have no connected screens.

## 3. Watch the stream figures change

Statistics describe the stream now. The simulator begins in a live state, then periodically supplies totals; the relay publishes the resulting snapshot every five seconds.

```sh
curl -fsS http://127.0.0.1:8080/api/v1/stats | python3 -m json.tool
sleep 35
curl -fsS http://127.0.0.1:8080/api/v1/stats | python3 -m json.tool
```

- The first line reads the public statistics summary and formats it.
- `sleep 35` allows a 30-second simulated totals update and the regular statistics broadcast to occur.
- The final line reads the newer snapshot from the same endpoint.

Immediately after startup, `state` is `Live` but viewer, follower, and subscriber totals are zero. After the first telemetry update, the totals are `120`, `12400`, and `318`. Later updates move through a fixed pattern, so the values depend on how long you have spent reading. `uptimeSeconds` also jumps to a simulated stream age of about 12 minutes on the first totals update; it is not the relay process uptime.

`chatRate` rises as simulated messages arrive every two seconds. This HTTP summary includes state, viewers, followers, subscribers, uptime, and chat rate. The binary `STATS` message also carries the cumulative message count used by the display.

## 4. Read and create notification cards

A notification records something that happened. It has a sequence number and a display duration, while statistics are a replaceable snapshot. Let's inspect the retained notifications and publish one ourselves.

```sh
curl -fsS -H "Authorization: Bearer $RELAY_HTTP_AUTH_API_TOKEN" \
  'http://127.0.0.1:8080/api/v1/notifications?pageSize=5' | python3 -m json.tool
curl -fsS -H "Authorization: Bearer $RELAY_HTTP_AUTH_API_TOKEN" \
  -H 'Content-Type: application/json' \
  -d '{"type":"info","title":"Hello round display","body":"This card came through HTTP","ttlMs":8000}' \
  http://127.0.0.1:8080/api/v1/notifications | python3 -m json.tool
```

- The first request authenticates and reads the five most recent retained notifications. `pageSize` is the query parameter; the quotes preserve the URL as one shell argument.
- The next request uses the same authorization header.
- `Content-Type` identifies the request body as JSON.
- `-d` selects POST and supplies an `info` card with an eight-second display duration.
- The final line selects the notification endpoint and formats the response.

The list contains a `notifications` array, newest first. Over time, the audience script produces `pixelpainter` following, `nightowl` subscribing, `bitbaron` cheering bits, `generouspanda` gifting subscriptions, `streamfriend` raiding, and `quietlurker` following. The seventh audience tick is a Nightbot message that the default bot filter removes. The script then repeats. It also emits a stream-start event at startup; it does not simulate stream endings.

Your POST returns a record with an assigned `seq`, an `id` such as `ntf-0023`, the supplied text, and `ttlMs: 8000`. The sequence and timestamp vary. Sending the POST again creates another card; this API does not deduplicate retries.

You will also see `chat` records even though the default `RELAY_CHAT_NOTIFICATIONS` policy is `hide`. The relay sequences and retains human chat, and counts it in statistics, before deciding whether to send chat cards to a device. The Nightbot line is filtered earlier, so it contributes neither a card nor a chat count.

## 5. Putting it together

Both the simulator and your HTTP request have reached the relay's notification hub. Now inspect the last boundary: the attached devices.

```sh
curl -fsS -H "Authorization: Bearer $RELAY_HTTP_AUTH_API_TOKEN" \
  http://127.0.0.1:8080/api/v1/devices | python3 -m json.tool
```

- The first line supplies management authorization.
- The second line reads the current device connections and formats the response.

The result is `{"devices":[]}`. The successful POST proves that the relay accepted and retained your card. It does not prove that a physical screen received or displayed it.

```mermaid
flowchart LR
  S[Simulated Twitch events] --> B[Event bus]
  B --> R[Card routing]
  B --> T[Statistics]
  P[HTTP notification POST] --> H[Device hub]
  R --> H
  T --> H
  H --> A[HTTP inspection]
  H --> L[TSB/3 over TCP 8099]
  L --> E[ESP32 and round LCD]
```

An ESP32 initiates a persistent TCP connection to port 8099. The relay sends binary `EVENT` and `STATS` frames there; the firmware does not poll this HTTP API. This tutorial bound that listener to loopback. The [firmware setup guide](firmware-setup.md) explains the LAN address and listener settings for a physical device.

The complete runnable example is the existing relay in simulated mode, which you have just exercised from source through its HTTP boundary. Its companion implementation is [SimulatedTwitchSource.scala](../../twitch-screen-relay/src/twitchscreen/relay/twitch/SimulatedTwitchSource.scala). The existing [container smoke script](../../tools/smoke_container.py) extends automated verification through a real TSB/3 handshake and shutdown; its run commands are in the [development guide](development.md#container-checks).

### Running the examples

<details>
<summary>Complete two-terminal workflow</summary>

This is the same workflow in one place. To replay it from scratch, stop the earlier relay first and begin in a parent directory without an existing `twitch-screen` checkout. Keep terminal 1 running after the final command:

```sh
git clone https://github.com/worxbend/twitch-screen.git
cd twitch-screen/twitch-screen-relay
test -f .env.tutorial || (umask 077; openssl rand -hex 32 > .env.tutorial)
export RELAY_HTTP_AUTH_API_TOKEN="$(cat .env.tutorial)"
RELAY_HTTP_HOST=127.0.0.1 RELAY_DEVICE_HOST=127.0.0.1 \
  RELAY_TWITCH_MODE=simulated ./mill --no-server run
```

- `git clone` creates the checkout; `cd` enters the runnable relay module directly.
- `test` preserves an existing tutorial token; the parenthesized command creates a private random token when absent.
- `export` loads that token for the relay.
- The final two lines bind both listeners to loopback and start the simulated source in the foreground.

Wait for the management startup message. Open terminal 2 in the same parent directory where you cloned the repository, then run:

```sh
cd twitch-screen/twitch-screen-relay
export RELAY_HTTP_AUTH_API_TOKEN="$(cat .env.tutorial)"
curl -fsS http://127.0.0.1:8080/api/v1/health
curl -sS -i http://127.0.0.1:8080/api/v1/status
curl -fsS -H "Authorization: Bearer $RELAY_HTTP_AUTH_API_TOKEN" \
  http://127.0.0.1:8080/api/v1/status | python3 -m json.tool
curl -fsS http://127.0.0.1:8080/api/v1/stats | python3 -m json.tool
sleep 35
curl -fsS http://127.0.0.1:8080/api/v1/stats | python3 -m json.tool
curl -fsS -H "Authorization: Bearer $RELAY_HTTP_AUTH_API_TOKEN" \
  'http://127.0.0.1:8080/api/v1/notifications?pageSize=5' | python3 -m json.tool
curl -fsS -H "Authorization: Bearer $RELAY_HTTP_AUTH_API_TOKEN" \
  -H 'Content-Type: application/json' \
  -d '{"type":"info","title":"Hello round display","body":"This card came through HTTP","ttlMs":8000}' \
  http://127.0.0.1:8080/api/v1/notifications | python3 -m json.tool
curl -fsS -H "Authorization: Bearer $RELAY_HTTP_AUTH_API_TOKEN" \
  http://127.0.0.1:8080/api/v1/devices | python3 -m json.tool
```

- `cd` selects the same module; `export` gives this second terminal the server's token.
- The health request checks public liveness. The first status request deliberately omits authentication; the second supplies the Bearer token.
- The two statistics requests surround a 35-second observation interval.
- The first notification request lists recent records. The second authenticates, declares JSON, posts an eight-second info card, and formats its assigned record.
- The final request inspects connected devices. Each `python3 -m json.tool` formats the preceding JSON response.

Expect public health `Up`, unauthenticated status `401`, authenticated status `200`, changing simulated statistics, a newly assigned notification sequence, and an empty device list. No physical screen is required. Finish with the next section's Ctrl+C and token cleanup steps.

</details>

## 6. Stop the simulation and understand reset

The relay's recent cards, statistics, activity, and alerts live in memory. Press **Ctrl+C in terminal 1** and wait for the relay to exit. Then clear that terminal's credential:

```sh
unset RELAY_HTTP_AUTH_API_TOKEN
```

- `unset` removes the temporary credential from terminal 1 after the relay stops.

In terminal 2, remove the tutorial credential file and clear its copy of the token:

```sh
rm .env.tutorial
unset RELAY_HTTP_AUTH_API_TOKEN
```

- `rm` removes the temporary token file used by this walkthrough.
- `unset` removes the token from terminal 2's environment.

The listeners close. Restarting the simulator starts its scripts, counters, and in-memory history again; there is no reset HTTP endpoint.

A device reconnecting during the same relay run can request a finite replay of retained events. A freshly booted device starts from the current sequence and does not receive an old backlog. The replay buffer is not durable storage and does not guarantee recovery after a relay restart. The [architecture reference](../reference/architecture.md#reconnects-and-delivery-limits) explains these boundaries.

## What you've learned

You have:

- Run the simulated source without Twitch credentials or hardware.
- Used public health and statistics endpoints and authenticated management requests.
- Distinguished changing stream snapshots from sequenced notification cards.
- Published a card and located the TSB/3 connection that delivers it to an ESP32.

## Where to go next

- [Firmware setup](firmware-setup.md) connects a prepared board to the relay; [device build](device-build.md) covers the hardware and enclosure.
- [Relay setup](relay-setup.md) covers persistent configuration and deployment options.
- [Twitch application setup](twitch-app-setup.md) replaces simulated observations with a real channel.
- [Development](development.md) lists the automated checks, and [architecture](../reference/architecture.md) explains the implementation boundaries.
- Return to the [guidebook](../README.md) to choose another route.

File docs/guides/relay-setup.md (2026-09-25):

# 🛰️ Run the relay

[Guidebook](../README.md) · [Twitch application setup](twitch-app-setup.md) · [Configuration reference](../reference/relay-configuration.md) · [HTTP API](../reference/http-api.md)

The relay is the always-on middle of your setup: it receives Twitch activity, builds notifications and statistics, and pushes them to the ESP32. Run it on a computer or Linux host that your display can reach over Wi-Fi. Start in simulated mode, then connect Twitch once the device path works. Tiny screen, sensible infrastructure. ✨

## Choose your route 🚦

| Route | Best fit | What you install |
|---|---|---|
| [Native development](#native-development-) | Editing or debugging the relay | Git, a Java bootstrap runtime, curl, OpenSSL; Python 3 for the password helper |
| [Docker Compose](#docker-compose-) | An unattended local relay | Git, Docker Engine/Desktop with Compose v2, OpenSSL |
| [Standalone JAR](#standalone-jar-) | An existing JVM service host | Java 25 to run; the repository's Mill wrapper to build |

The [first simulated stream tutorial](first-simulated-stream.md) gives a shorter learning path. This page covers configuration, persistence, and ongoing operation.

## Native development 💻

Start from the repository root:

```sh
cd twitch-screen-relay
export RELAY_HTTP_AUTH_API_TOKEN="$(openssl rand -hex 32)"
export RELAY_TWITCH_MODE=simulated
./mill run
```

The checked-in launcher pins Mill **1.1.9**, Scala **3.9.0**, and Temurin **25** in [build.mill](../../twitch-screen-relay/build.mill). It downloads the pinned toolchain and dependencies on first use, so allow internet access and extra startup time. A current bootstrap Java runtime on `PATH` avoids launcher setup surprises; using JDK 25 directly is the straightforward option.

The token generation creates a fresh random management credential for this shell. Store it in a password manager for reuse. Running the command again rotates it **only after restarting the relay** with the new value. Other terminals must use the value the running relay received; generating a different token there will produce `401` responses.

Wait for startup logs announcing both listeners:

| Listener | Default | Connects from |
|---|---|---|
| Management HTTP and Swagger | `http://localhost:8080` and `/docs` | Your browser, terminal, and monitoring |
| TSB/3 device TCP | Port `8099` | ESP32 firmware |

In another terminal, confirm the public endpoints:

```sh
curl --fail --silent --show-error http://localhost:8080/api/v1/health
curl --fail --silent --show-error http://localhost:8080/api/v1/stats
```

Health returns `{"status":"Up"}`. Stats contains the latest broadcast state and counters. Public health confirms HTTP liveness; it does not require an attached device or working Twitch authorization.

For private readiness, use the **same management token** in this terminal:

```sh
curl --fail --silent --show-error \
  -H "Authorization: Bearer $RELAY_HTTP_AUTH_API_TOKEN" \
  http://localhost:8080/api/v1/status
```

Stop the native process with **Ctrl+C**. The relay shuts down its listeners and device sessions; devices reconnect when it returns.

## Keep local configuration private 🔐

The native launcher does **not** automatically read a `.env` file. Use exported variables or explicitly source a private shell file that you created and trust.

From `twitch-screen-relay/`, create a file with private permissions:

```sh
umask 077
touch .env.local
chmod 600 .env.local
```

Edit `.env.local` locally and add your settings, replacing the placeholder token with the output of `openssl rand -hex 32`:

```sh
RELAY_HTTP_AUTH_API_TOKEN='replace-with-a-random-private-token'
RELAY_TWITCH_MODE='simulated'
RELAY_CHAT_NOTIFICATIONS='hide'
```

Load it and run:

```sh
set -a
. ./.env.local
set +a
./mill run
```

`set -a` exports the assignments for the relay process; `set +a` restores normal shell behavior. Sourcing executes shell syntax, so only load a file you control. `.env*` files are ignored by this repository, except designated example templates. Credentials should stay outside version control and screenshots.

Changing an environment file does not reconfigure a running relay. Stop it, load the file, and start again. `GET /api/v1/config` shows the resolved settings with designated secrets masked.

### Add browser-friendly Basic authentication

From `twitch-screen-relay/`:

```sh
export RELAY_HTTP_AUTH_BASIC_USERNAME='admin'
export RELAY_HTTP_AUTH_BASIC_PASSWORD_HASH="$(python3 tools/hash_management_password.py)"
```

Start or restart the relay with both variables. The helper asks for a password of at least 12 characters and emits a PBKDF2-SHA256 verifier. Save the verifier in your private environment file **inside single quotes** so its `$` characters remain literal. The plaintext password is what you enter into the browser or a `curl --user admin` prompt.

Either Basic or Bearer authentication is enough for a protected request. Configuring both methods is supported. A partial Basic configuration still prevents startup, even when a valid Bearer token is configured.

## Docker Compose 🐳

From the repository root:

```sh
cd twitch-screen-relay
export RELAY_HTTP_AUTH_API_TOKEN="$(openssl rand -hex 32)"
docker compose up --build -d
docker compose ps
docker compose logs --tail=100 relay
```

The supplied [Compose file](../../twitch-screen-relay/compose.yaml) starts **simulated** mode and publishes host ports **8080** and **8099**. Its authentication variables are taken from your exported environment or Compose `.env` interpolation. Save the same token privately before returning later to restart the stack.

The image uses Temurin 25, runs as the unprivileged `relay` user, and stores Twitch authorization under `/home/relay/data`. Compose mounts this directory as the `relay-data` named volume; Docker prefixes its actual name with the Compose project name. Keep the same project name and volume when updating.

The starting container memory limit is **512 MiB**. `JAVA_OPTS` gives the heap up to 70% of container memory and exits on heap exhaustion. This is a starting budget exercised by the repository's container smoke check; measure your own stream/device workload before treating it as a capacity guarantee.

Useful operations, run from `twitch-screen-relay/`:

| Command | Result |
|---|---|
| `docker compose logs --follow relay` | Follow startup and runtime logs |
| `docker compose restart relay` | Restart with the existing container configuration |
| `docker compose up --build -d` | Rebuild and recreate as needed, preserving the named volume |
| `docker compose stop` | Stop containers and retain them and the data volume |
| `docker compose down` | Remove the stack's containers/network; retain its named volume |

Do not add `--volumes` to `down` when you want to retain saved Twitch consent. A plain `restart` does not apply changed environment variables; use `up -d` to recreate the service with its updated configuration.

### Run live Twitch in Compose

The base file hardcodes `RELAY_TWITCH_MODE: simulated`. Merely exporting `RELAY_TWITCH_MODE=live` does not override that YAML value. Create an override file that explicitly changes it.

First complete [Twitch app registration](twitch-app-setup.md). Then create a private `.env.live` in `twitch-screen-relay/`, with real values in place of the placeholders:

```dotenv
RELAY_HTTP_AUTH_API_TOKEN=replace-with-your-existing-random-management-token
RELAY_TWITCH_CHANNEL=yourchannel
RELAY_TWITCH_CLIENT_ID=replace-with-your-client-id
RELAY_TWITCH_CLIENT_SECRET=replace-with-your-client-secret
RELAY_TWITCH_REDIRECT_URL=http://localhost:8080/api/v1/twitch/callback
```

Create `compose.live.yaml` alongside `compose.yaml`. This file contains variable references, not credentials:

```yaml
services:
  relay:
    environment:
      RELAY_TWITCH_MODE: live
      RELAY_TWITCH_CHANNEL: ${RELAY_TWITCH_CHANNEL:?Set your channel login}
      RELAY_TWITCH_CLIENT_ID: ${RELAY_TWITCH_CLIENT_ID:?Set your client ID}
      RELAY_TWITCH_CLIENT_SECRET: ${RELAY_TWITCH_CLIENT_SECRET:?Set your client secret}
      RELAY_TWITCH_REDIRECT_URL: ${RELAY_TWITCH_REDIRECT_URL:-http://localhost:8080/api/v1/twitch/callback}
      RELAY_TWITCH_EVENTSUB_TRANSPORT: websocket
```

Run the combined configuration:

```sh
chmod 600 .env.live
docker compose --env-file .env.live -f compose.yaml -f compose.live.yaml up --build -d
docker compose --env-file .env.live -f compose.yaml -f compose.live.yaml logs --tail=100 relay
```

Use the same file arguments for future live updates. An exported variable in your shell can override `.env.live` interpolation, so keep those values consistent. Avoid pasting `docker compose config` output into issues: its resolved environment can contain secrets.

Complete the [Bearer consent flow](twitch-app-setup.md#5-start-the-relay-and-grant-consent-) from the browser computer, using an SSH tunnel for a headless host. For browser Basic login, add both Basic settings to `.env.live`; the base Compose file already forwards them. In Compose environment files, single-quote a saved PBKDF2 verifier to preserve its dollar signs.

### Persistence and backups

Only the Twitch token file is persistent application state here. Replay history, sequence state, logs, alerts, and activity are memory-resident and reset with the process. A volume backup preserves the grant; it does not turn the relay into a durable event archive.

Stop the relay before a token-volume backup, use your normal encrypted backup tooling, and protect restoration access as you would a password. Named volumes inherit the image's data-directory ownership. When choosing a bind mount instead, the directory must be writable by UID **10001**, the container's relay user.

## Standalone JAR 📦

Build from `twitch-screen-relay/`:

```sh
./mill assembly
```

Run the generated artifact with Java 25 and your exported configuration:

```sh
java -jar out/assembly.dest/out.jar
```

The token path remains relative to the process working directory. For an OS-managed service, choose a stable working directory, load secrets from a restricted environment file, restart on failure, and preserve the token directory across deployments. The repository does not ship a systemd unit or an automatic release installer.

## Network boundaries and HTTPS 🔒

The two listeners serve different audiences:

```mermaid
flowchart LR
  Twitch["Twitch APIs, IRC, EventSub"] --> Relay["Relay"]
  Browser["Operator browser / API client"] -->|"HTTPS proxy or SSH tunnel"| Relay
  Relay -->|"TSB/3 over TCP 8099"| Device["ESP32 on trusted LAN"]
```

The ESP32 initiates the device connection; the arrow above shows the direction of pushed data. Set firmware `SERVER_HOST` to the relay's **LAN IP or resolvable hostname**, and `SERVER_PORT` to `8099`. `localhost` on the ESP32 refers to the ESP32, not your computer. Reserve the relay's LAN address in your router so a DHCP change does not strand the display.

The device TCP listener has **no authentication or TLS**. Keep port 8099 on a trusted LAN, with firewall access limited to the device network. Do not expose it directly to the internet. Network isolation matters even when the HTTP API has strong credentials.

The HTTP server itself speaks plain HTTP. Use an HTTPS reverse proxy or an SSH tunnel for credential-bearing requests across networks. The supplied Compose port mappings publish on all host interfaces by default; account for that in your firewall or change the HTTP mapping to `127.0.0.1:8080:8080` when a local proxy/tunnel is your only entry point. The container listener should still bind `0.0.0.0` internally.

A reverse proxy must preserve the public **Host** header. The relay does not trust forwarded headers for Basic-auth cross-site checks. Pass `Authorization` through to management routes. Preserve the exact OAuth and EventSub callback paths, and leave those callback routes reachable for their protocol-specific authentication. OAuth state protects the OAuth callback; HMAC verification protects webhook deliveries.

Health, aggregate stats, and Swagger documentation are intentionally public. Put access restrictions in your network/proxy when those should be private too. The current HTTP API is a single-operator management surface: it does not provide per-user roles, accounts, or tenant separation.

## Observe, update, recover 🧰

Use authenticated `/api/v1/status` for Twitch health, connected-device counts, dropped internal-bus events, and buffer/alert counts. `/api/v1/devices` adds per-connection traffic counters; `/api/v1/logs` and `/api/v1/activity` help explain what happened. The [API reference](../reference/http-api.md) includes filters and sample requests.

OpenTelemetry exports are disabled unless configured. To send traces and metrics to an existing collector, from `twitch-screen-relay/`:

```sh
OTEL_TRACES_EXPORTER=otlp OTEL_METRICS_EXPORTER=otlp \
OTEL_EXPORTER_OTLP_ENDPOINT=http://collector:4317 ./mill run
```

Replace `collector` with a reachable collector hostname. Container deployments must explicitly forward these variables in their Compose environment. No collector, Grafana instance, or Prometheus endpoint is installed by this command.

For an update, stop the old process, retain configuration and token storage, build the selected revision, and start with the same environment. Check health, authenticated readiness, and a manual device notification afterward. Devices and relay must both speak **TSB/3**; older NDJSON firmware cannot connect to this relay. Missed notifications are eligible for replay only while retained by the current process: 64 non-chat records by default, plus a separate 16-record chat ring.

For a problem report, include the commit, runtime/OS, selected mode, redacted status, relevant logs, and whether a manual notification arrives. Leave out the environment file, authorization headers, and token JSON. Follow the [troubleshooting guide](troubleshooting.md) for symptoms and the [firmware setup guide](firmware-setup.md) for the other half of the connection.

Source trail: [Compose deployment](../../twitch-screen-relay/compose.yaml), [container image](../../twitch-screen-relay/Dockerfile), [configuration](../../twitch-screen-relay/resources/application.conf), [management authentication](../../twitch-screen-relay/src/twitchscreen/relay/http/ManagementAuth.scala), and [container smoke check](../../tools/smoke_container.py).

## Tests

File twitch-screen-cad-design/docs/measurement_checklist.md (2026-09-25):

# Hardware measurements before fabrication

The four supplied photos establish the configuration, not manufacturing scale.
All dimensions below are editable in `parameters.json` and the FreeCAD
`Parameters` object. **The nominal files are not a physical fit certification.**

| Item | Nominal model | Evidence / action |
| --- | --- | --- |
| LCD circular PCB / overall height | 37.5 / 40.4 mm | Waveshare official outline; confirmed |
| LCD tab width | 14.28 mm | Waveshare official outline; confirmed |
| LCD active diameter | 32.4 mm | Waveshare official specification; confirmed |
| Visible opening | 33.2 mm | Design choice; gives 0.4 mm radial margin around active area |
| LCD glass diameter / thickness | 35 / 1.8 mm | Measure glass and its offset to PCB |
| LCD PCB thickness | 1.6 mm | Measure; affects retainer's contact plane |
| LCD connector envelope | 21 × 6.5 × 6 mm | Measure with supplied cable plugged in; inspect cable exit |
| LCD connector centre | v = +10 mm | Provisional; rotate module so tab points down and connector up |
| LCD brass mount pattern / envelope | 27 × 19 mm; Ø4 × 1.2 mm projection | Provisional clearance model only; measure all four mounts. Retainer has Ø6 reliefs, not mating screw holes |
| ESP32 PCB outline | 55 × 28 × 1.6 mm | Measure exact Type-C board, excluding connector projection |
| ESP32 hole centres / bore | 24 × 49 mm / 3 mm | Measure centre-to-centre and diameter; four visible holes |
| Header row spacing / length | 25.4 / 38.1 mm | Measure actual soldered headers |
| Header + female housing depth | 11 mm below PCB | Measure fully installed jumper housing and allow wire bend |
| USB socket envelope | 9 × 7.5 × 3.4 mm | Measure width, length, height and vertical offset |
| USB beyond PCB rear edge | 2.5 mm | Measure socket's mating face, not shield pad extent |
| USB horizontal offset | 0 mm | Measure relative to PCB centreline |
| USB lower face above PCB top | 0 mm | `UsbBottomOffset`; measure the socket's vertical seating |
| Cable overmould | 14 × 9 mm | Measure the intended USB cable; port is generated from this envelope |
| Overmould corner radius | 2 mm | Rounded rectangular port; measure actual cable profile, set `UsbPlugCornerRadius` to 0 for a square envelope |
| Tallest ESP32 components | shield 3.2 mm above PCB; buttons 2.5 mm | Verify other components do not exceed these local envelopes |
| Shield / buttons XY envelopes | 18 × 25 mm shield, 4 × 4 mm buttons | Measure widths, depths and offsets; all have named parameters |
| Eight-wire loom corridor | Ø4.4 mm | Measure bundle and confirm bends are gentle enough for the actual wires |
| Screw pilot fit | Ø2.1 mm for M2.5; Ø1.7 mm for M2 | Print test holes in the chosen filament; adjust pilot dimensions in geometry if needed |

The retainer grips the LCD PCB perimeter. Its two mounting screws attach to the
enclosure, **not** the LCD's four brass mounting points. Their undocumented
thread size is not an enclosure fastening assumption. Their location and
projection still require measurement to confirm the generous retainer reliefs.

To update: edit parameters, rebuild, run the validation scripts and inspect
the new section render. Within FreeCAD, open `TwitchScreen.FCMacro`, edit the
Parameters object, and recompute. Exports do not update merely by saving FCStd;
copy changed dimensions to `parameters.json` and run the export command.

Print a base and check the ESP32 hole pattern first. Check the bezel opening,
glass seat and connector clearance before tightening the retainer. Use light
torque; no metal screw or printed edge should load the active glass surface.

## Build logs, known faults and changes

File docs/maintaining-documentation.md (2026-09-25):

# ✍️ Maintaining the guidebook

Write for the person doing the next step. The landing page can have personality; a pin number, redirect URL, or recovery instruction needs precision.

## Put information where a reader expects it

| Location | Responsibility |
| :--- | :--- |
| [Root README](../README.md) | Explain the project, show the device, give a first success, and route each audience |
| [Guidebook index](README.md) | Connect users, builders, and developers to a complete journey |
| `docs/guides/` | A linear tutorial or instructions for a specific task |
| `docs/reference/` | Exact configuration, API behavior, and system explanation |
| Component READMEs | Local entry points, commands, tooling, and links to detailed guides |
| Existing protocol/CAD records | Authoritative wire rules and mechanical evidence |
| [Decision records](decisions/README.md) | Context, choices, trade-offs, and consequences |

The [organization decision](decisions/0001-guidebook-structure.md) explains this split. [GitHub’s README guidance](https://docs.github.com/en/repositories/managing-your-repositorys-settings-and-features/customizing-your-repository/about-readmes) informs the landing page; [Diátaxis](https://diataxis.fr/start-here/) informs the separation of learning, tasks, reference, and explanation.

## Check facts against the implementation

Read the source before rewriting an old guide. Use the current code to establish behavior, configuration files for defaults, tests for edge cases, and history for the reason behind a choice. Treat plans and previous review reports as historical evidence, not a guarantee of current behavior.

Link to source for details likely to drift. For external requirements such as Twitch app registration, read the current official documentation and include a direct link. Record the review date. Distinguish a provider requirement from a limitation of this relay.

Avoid claiming a feature exists because a protocol enum names it. Verify which live producer actually emits it and whether the UI supports it. Explain known differences between the HTTP API and wire vocabulary.

## Make commands usable

State prerequisites, the working directory, and which terminal remains running. Separate placeholder values from runnable examples. Explain what a successful command returns, where files are written, and how to stop a service.

For a learning tutorial, use one path, introduce one concept at a time, annotate every command block, and show intermediate results. State learning objectives up front and mirror them in the recap. Task guides can offer clearly labeled choices such as native versus Docker execution.

Use `sh`, `bash`, `json`, `yaml`, `cpp`, or `text` fences as appropriate. Parse shell examples without executing destructive actions. Never test upload, erase, live authorization, or production mutations merely to check prose. Run local simulation with temporary credentials and isolated ports when functional evidence is needed.

The current docs use existing runnable tools as examples. There is no sbt/mdoc documentation module, Docusaurus site, or Scala tutorial companion module in this repository. Do not claim those checks passed or add incompatible embeds that GitHub cannot render. Any future addition of such tooling needs its own scoped change.

## Keep the style friendly and accessible

- Use clear headings and short paragraphs. Put the result or instruction before background detail.
- Use emoji alongside descriptive text; never make an icon the only navigation label.
- Keep jokes in introductions and transitions. Troubleshooting should name the symptom and the next diagnostic action.
- Use repository-relative links for local files. Check every target and section anchor.
- Use descriptive image alt text. Identify renders, mockups, and measured results honestly.
- Reuse the checked-in CAD previews; avoid duplicating large image files.
- Keep centered HTML to the README hero and compact galleries. The instructions should remain readable as ordinary Markdown.
- Prefer GitHub-compatible callouts and code fences. Do not introduce site-specific directives into these pages.

## Record decisions without inventing history

Follow the [ADR convention](decisions/README.md). A new decision needs context, the actual chosen approach, considered alternatives, and consequences. Do not retroactively call a historical design “accepted” or invent alternatives no one evaluated. Source-backed architecture explanations can document current trade-offs without pretending to be an approval record.

Keep old records when a decision changes and link a superseding record. Documentation-only edits do not imply a software release, version bump, or release-note entry.

## Review before sharing

1. Read the complete changed pages, including preserved sections in component READMEs.
2. Follow each reader journey through its links. Check the first-run path without relying on undocumented environment variables.
3. Check local links, headings, anchors, image paths, and alt text; inspect the rendered landing page at desktop and narrow widths.
4. Parse shell blocks and validate JSON/YAML examples. Check commands against the actual tools and configuration.
5. Compare configuration tables and API examples against source, including auth requirements and limits.
6. Use a separate reviewer for factual claims and tutorial structure. Fix findings in the documentation and run the focused checks again.
7. Report what was executed, what was source-reviewed, and what still requires live Twitch or a physical device.

The [documentation review record](../tasks/docs-quality-review.md) applies the requested documentation skills to this revision and records explicit exceptions to their ZIO-specific tooling requirements.

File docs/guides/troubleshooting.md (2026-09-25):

# 🩺 When the tiny circle has opinions

[← Guidebook](../README.md) · [Device use](device-use.md) · [Relay setup](relay-setup.md)

Work from the first layer that fails: **power → display → Wi-Fi → relay TCP → Twitch**. One successful layer narrows the next check. A simulated notification is especially useful because it exercises the display path without needing a live Twitch account.

## Start with the symptom

| Symptom | Start here |
| --- | --- |
| No USB serial port | [USB and upload](#usb-and-upload) |
| Build cannot find PlatformIO or credentials | [Build environment](#build-environment) |
| Black, white or incorrect-color screen | [Display and wiring](#display-and-wiring) |
| CONNECTING never ends | [Connection and networking](#connection-and-networking) |
| Device disconnects repeatedly | [Connection log decoder](#connection-log-decoder) |
| OFFLINE while the channel is live | [Twitch and telemetry](#twitch-and-telemetry) |
| API returns 401 or startup refuses to run | [Management authentication](#management-authentication) |
| Missing, delayed or shortened notifications | [Cards and replay](#cards-and-replay) |
| Enclosure or USB cable does not fit | [Printed parts and assembly](#printed-parts-and-assembly) |

## Build environment

### `ModuleNotFoundError: No module named 'platformio'`

An old PlatformIO virtual environment can break after a host Python upgrade. Use the isolated environment in [firmware setup](firmware-setup.md#2-install-the-projects-platformio-version) and confirm its `pio --version` works before compiling. Do not mix that environment with an old `~/.platformio/penv` executable.

### `credentials.h: No such file or directory`

Create the ignored file from `src/credentials.example.h`, fill in your Wi-Fi and relay settings, then rebuild. The template itself is not used as the active configuration. Preserve an existing private header instead of copying over it.

### Platform downloads or builds fail unexpectedly

Run one PlatformIO install/build/test command at a time. Check Internet access and the **first actual error** before retrying. Use the pinned platform and library versions in `platformio.ini`; a dependency upgrade is a separate development change, not a routine setup step.

`native-sanitized` is the Linux host gate. A missing host compiler or incompatible sanitizer toolchain is different from an ESP32 compilation failure. The command `pio run -e esp32dev` builds the hardware target; it does not run the host tests.

## USB and upload

### The board powers up, but no port appears

Power does not prove the cable carries data. Try a known data cable and a direct USB port, then run `pio device list`. Check which USB-to-serial chip your particular board uses before installing a driver. Match the actual device, not only its connector shape.

### Permission denied or port busy

Close serial monitors and other applications using the port. On Linux, apply [PlatformIO's device-access instructions](https://docs.platformio.org/en/stable/core/installation/udev-rules.html). Group changes require a new login session; reconnect the board after installing udev rules.

### Upload stays at `Connecting…`

Verify the selected port. Hold BOOT during the connection attempt; if needed, hold BOOT and briefly press EN/reset. Release BOOT after writing begins. For the electrical boot-mode explanation, use [Espressif's bootloader guide](https://docs.espressif.com/projects/esptool/en/latest/esp32/advanced-topics/boot-mode-selection.html).

After upload, reset with BOOT released. A board left in download mode will not run the display application.

### Serial text is unreadable or startup is missing

Use **115200 baud**. Open the monitor, then press EN/reset to capture the boot messages. Look for `[app] reset reason=` and the display initialization line. Serial messages can be omitted when the output buffer is full, so a missing individual line is not definitive evidence of a missing action.

## Display and wiring

Disconnect power before reseating wires. Compare each connection with the [wiring table](device-build.md#2-wire-the-display).

| Observation | Likely area | First check |
| --- | --- | --- |
| No backlight | Power, ground or BL | LCD VCC to 3V3, common ground, BL to GPIO 15 |
| Backlight but no UI | SPI/control wiring or wrong module | DIN 23, CLK 18, CS 5, DC **16/RX2**, RST 4; GC9A01 non-touch module |
| All colors systematically wrong | RGB565 byte order | Confirm current `lv_port.cpp` uses `LV_COLOR_FORMAT_RGB565_SWAPPED` |
| Red and blue swap but dark background stays dark | RGB/BGR panel ordering | Confirm module/controller and driver configuration before changing it |
| Image looks like a photographic negative | Panel inversion | Confirm the GC9A01 initialization path |
| Random sparkles, shifted rows, changes when wires move | Connection/signal integrity | Reseat and shorten wires; keep the configured 40 MHz SPI clock |

The expected palette is near-black `#0E0E10`, purple `#9146FF`, red LIVE `#EB0400`, and near-white `#EFEFF1`. A tan/olive background together with a blue LIVE pill suggests byte order; it is different from merely swapping red and blue channels.

The current renderer already uses swapped RGB565. Adding `tft.setSwapBytes(true)` as a second fix can swap the bytes twice. Confirm the checked-out implementation before applying advice from an old experiment or another TFT_eSPI project.

The current port uses one aligned **19,200-byte** draw buffer and synchronous partial flushes. Older project notes describe other buffer layouts. Use [lv_port.cpp](../../twitch-screen-firmware/src/lv_port.cpp) as the current implementation reference.

Fine diagonal lines visible only in a camera photo can be camera/display moiré. Compare with what your eyes see before treating the photo pattern as corrupted pixels.

## Connection and networking

### The screen stays on CONNECTING

1. Confirm the SSID/password in your private firmware configuration and the availability of a **2.4 GHz** network. Changes require a rebuild and upload.
2. Confirm the relay is actually running. On its computer, request `http://127.0.0.1:8080/api/v1/health`.
3. Confirm `SERVER_HOST` is that computer's reachable LAN address. It must not be `localhost`, `127.0.0.1`, `0.0.0.0`, an HTTP URL or a stale DHCP address.
4. Confirm `SERVER_PORT` matches the relay's **device TCP** listener, normally 8099. HTTP 8080 is a separate service.
5. Check the host firewall, container port publishing and router/client-isolation rules. The ESP32 must be able to reach the relay across the LAN.
6. Inspect serial messages at 115200 baud and find the first connection failure below.

A working HTTP health request on the relay computer does not prove TCP 8099 is reachable from Wi-Fi. Likewise, both devices having Internet access does not prove a guest network lets them communicate.

The firmware's connection messages start after Wi-Fi is connected. A persistent connecting animation without link-attempt messages points first toward Wi-Fi or missing serial output; the current application does not print a full Wi-Fi credential/IP diagnostic on every attempt.

### One device works, another keeps reconnecting

Check `DEVICE_ID`. Two physical boards using the same custom name replace each other. Leave it empty for automatic chip-derived identities or assign distinct names no longer than 31 printable ASCII bytes, then rebuild and flash the changed devices.

### Reconnect is slower after several failures

This is expected backoff: the retry base grows to 30 seconds, adds jitter and honors a relay-requested minimum. It resets after 60 seconds of stable streaming. Do not interpret a pause between retries as a permanent stop.

## Connection log decoder

| Serial fragment | Meaning | Action |
| --- | --- | --- |
| `connect failed` / `connect timeout` | DNS or TCP connection did not complete | Verify host, port, relay listener and network access |
| `welcome timeout` | TCP connected but no valid greeting arrived in time | Check that this is the TSB/3 relay and device port |
| `bad handshake` | First inbound frame was not an acceptable greeting | Match firmware/relay versions and inspect the service on that port |
| `wifi lost` | Wi-Fi is down | Check signal and router; the firmware retries automatically |
| `heartbeat timeout` | No usable inbound activity within the device's silence deadline | Check relay health, network interruption and logs |
| `peer closed/read failed` | Socket closed or a read failed | Correlate with relay restart/disconnect logs |
| `write timeout` | Pending output could not complete within its deadline | Check a stalled connection or relay |
| `BYE code=1` | Unsupported protocol version | Update the matching relay/firmware pair; TSB/3 and old NDJSON cannot interoperate |
| `BYE code=3` | Invalid device ID | Use a short nonblank printable ASCII name or the automatic default |
| `BYE code=8` | Relay shutting down | Wait for relay restart |
| `BYE code=9` | Another connection claimed the same device ID | Fix duplicate names |
| `BYE code=10` | Rate limit | Inspect the relay load and honor its retry delay |
| `queue full, refused` | Defensive queue admission refused a new card | Let the queue drain; reconnect/replay is bounded by retained history |
| `close worker allocation failed` | Required firmware transport task was not created | Record build and boot logs; investigate memory/task creation before assuming a network fault |

The complete refusal-code contract is in [TSB/3 §6.7](../../twitch-screen-firmware/docs/PROTOCOL.md). Repeated malformed-frame counters are useful evidence; copy the counter line along with the surrounding failure, not only the last retry message.

## Management authentication

### Relay refuses to start without credentials

Every mode, including `simulated`, needs a management Bearer token or complete Basic credentials. Follow [relay setup](relay-setup.md). A partial Basic configuration or malformed password verifier can reject startup even when other settings look correct.

### HTTP 401 from `/status`, `/devices` or notification injection

Use the same credential configured in the running relay. A new terminal does not automatically inherit an export from another one. Generating a new token only in the client terminal will not match the already running server.

For a Bearer installation, from a shell containing the existing token:

```sh
curl --fail-with-body http://127.0.0.1:8080/api/v1/status \
  -H "Authorization: Bearer $RELAY_HTTP_AUTH_API_TOKEN"
```

Use HTTPS or a trusted local connection for administration; the display's TCP connection uses a different protocol and does not accept this HTTP header.

## Twitch and telemetry

### OFFLINE persists during a real stream

First confirm simulated events work on the display. Then check the relay mode, channel login and `/api/v1/status`. `disabled` mode does not ingest Twitch; `simulated` mode describes a demo stream. Use `live` mode and complete [Twitch app authorization](twitch-app-setup.md) for a real channel.

### Viewer count works, follower or subscriber count does not

Different upstream calls need different grants and channel roles. A missing metric does not establish that the whole relay is disconnected. Inspect `/api/v1/twitch/authorization` and status using your management credential, then compare the granted scopes/account with the [Twitch setup guide](twitch-app-setup.md).

### OAuth redirect fails

Check that the registered Twitch redirect URL exactly matches the relay configuration, including scheme, host, port and path. A `localhost` callback refers to the computer running the browser. Headless/remote hosting needs the browser and callback routing described in [Twitch app setup](twitch-app-setup.md).

### Uptime, totals or ring look surprising

The uptime label ticks every second even though telemetry normally arrives every five seconds. `MSG` is a running observed-message count, while the edge ring is recent messages per minute capped visually at 100. A relay restart resets in-memory aggregation; it cannot reconstruct chat from before it started.

## Cards and replay

- **Cards arrive late during a burst:** they display sequentially, with per-kind hold times. Eight waiting slots and animation time can create a visible backlog.
- **A reset did not recover missed events:** fresh firmware boots have no retained replay position. Replay is bounded and in memory, not a persistent inbox.
- **A reconnect shows an old event:** retained replay has no age cutoff. A card can belong to an earlier stream.
- **Long names or bodies end in dots:** text is deliberately clipped with an ellipsis to fit the circle.
- **Emoji or non-Latin names change:** the firmware advertises ASCII-only text support, so the relay folds unsupported characters.
- **Some bot events never appear:** the relay filters its configured ignored display names upstream. Review the configured list rather than changing the firmware queue.
- **A donation event never appears:** native cash-donation ingestion is not implemented. The protocol reserves that kind; use supported custom-notification integration where appropriate.

See [device use](device-use.md) for the exact display behavior and [the protocol](../../twitch-screen-firmware/docs/PROTOCOL.md) for replay limits.

## Printed parts and assembly

### ESP32 holes, USB port or LCD retainer do not line up

Compare your parts to the [measurement checklist](../../twitch-screen-cad-design/docs/measurement_checklist.md). The model uses provisional dimensions for the clone board, display stack and connectors. Change the parameters and regenerate the exports; scaling the whole enclosure also changes screw sizes, LCD opening and wall thickness.

### The USB plug fits the socket but not the enclosure

Measure the cable's plastic overmould, not only the metal connector. The generated opening depends on `UsbPlugWidth`, `UsbPlugHeight` and `UsbPlugCornerRadius` in the CAD parameters.

### The shell rocks or the base needs force

Check supports, the locating lip, wire routing and post clearance. The base should not pinch the loom. Validate the base and pilot holes with small test prints before tightening the complete assembly.

### A mesh contains boards and a cable-shaped object

You opened an `assembly_view_only` export. Use `print_plate.3mf` or the four individual printable parts from the [build guide](device-build.md#5-choose-and-slice-the-printable-files).

## Collect a useful issue report

Include the repository commit, board/module model, OS, failing command, first relevant error, serial reset/connection messages and relay status. For display faults, include a photo and say whether the fault is visible to the eye. For mechanical faults, include measured dimensions and the exact export used.

Remove passwords, tokens, private credential files and personal notification contents before sharing logs. State which checks actually ran: a successful compile or nominal CAD report is not a physical device test.

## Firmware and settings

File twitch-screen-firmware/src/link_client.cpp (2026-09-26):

#include "link_client.h"

#include <stdarg.h>
#include <array>
#include <stdio.h>
#include <string.h>
#include "notification_wire.h"
#include "proto_codec.h"

// TSB/3 device side. Normative reference: docs/PROTOCOL.md. Section numbers in
// the comments below point at it; where this file and that document disagree,
// that document wins.
//
// There is no JSON here and no character-oriented API anywhere near the socket
// (§2): a partial multi-byte sequence handed to a Reader/String would be
// mangled before the codec ever saw it. Bytes only.

namespace {

// §12 — every timer value is unchanged from v2; only the encoding changed.
constexpr uint32_t CONNECT_TIMEOUT_MS = 3000;
constexpr uint32_t WRITE_TIMEOUT_MS = 3000;
constexpr uint32_t STABLE_STREAM_MS = 60000;
constexpr uint32_t WELCOME_TIMEOUT_MS = 5000;
constexpr uint32_t PING_INTERVAL_MS   = 15000;
constexpr uint32_t RX_TIMEOUT_MS      = 45000;   // inbound silence of any kind
constexpr uint32_t BACKOFF_BASE_MS    = 1000;
constexpr uint32_t BACKOFF_MAX_MS     = 30000;
constexpr uint8_t BACKOFF_MAX_SHIFT = 5;
// Saturation bound for the uint8_t retry counter. It stops ++failures wrapping
// to 0 (which would drop the ramp back to 1 s) and keeps any (failures - 1)
// shift below the 32-bit width of BACKOFF_BASE_MS. The ramp itself saturates
// much earlier, at BACKOFF_MAX_SHIFT.
constexpr uint8_t FAILURES_SATURATE = 31;
static_assert(FAILURES_SATURATE > BACKOFF_MAX_SHIFT + 1 && FAILURES_SATURATE < 32,
              "retry counter bound must cover the backoff ramp and stay below uint32 shift width");

// §12 — the relay's own timers, which WELCOME reports (§6.2). They differ from
// the device's on purpose (the relay is more patient), so a WELCOME is checked
// against these, not against PING_INTERVAL_MS / RX_TIMEOUT_MS.
constexpr uint16_t EXPECTED_RELAY_PING_S = 20;
constexpr uint16_t EXPECTED_RELAY_IDLE_S = 90;

// §6.6 — ACK at most once per 200 ms, coalesced to the highest seq.
constexpr uint32_t ACK_MIN_INTERVAL_MS = 200;

// Bytes lifted off the socket per linkLoop() call. A replay burst of eighty
// EVENTs is 14 kB; draining it in one go would stall LVGL for the duration, so
// it is spread over consecutive 5 ms iterations instead. TCP does the holding.
constexpr uint32_t RX_BUDGET_PER_LOOP = 1024;

// §6.1 capabilities this build actually has. CAP_UTF8_TEXT is deliberately NOT
// set: the built fonts are Montserrat 14/20/28/48, which cover 0x20..0x7e plus
// two extras, so the relay must fold to printable ASCII for us (§9.3). Claiming
// a font we do not have would render squares, not text.
constexpr uint32_t DEVICE_CAPS =
    tsb::CAP_ACK | tsb::CAP_CHAT | tsb::CAP_GENERIC;

enum class State : uint8_t { Idle, Connecting, Connect, Streaming };

struct LinkSession {
  LinkTransport *io = nullptr;
  State state = State::Idle;
  const LinkHooks *hooks = nullptr;

  tsb::FrameReader reader;

  uint32_t nextAttemptAt = 0;
  uint8_t  failures      = 0;
  uint32_t connectedAt   = 0;
  uint32_t lastRxAt      = 0;
  uint32_t lastPingAt    = 0;
  uint32_t streamingAt   = 0;
  uint32_t lastSkipLogAt = 0;
  uint32_t skippedSinceLog = 0;

  // A fixed byte FIFO preserves frame order across short/nonblocking writes.
  std::array<uint8_t, 256> tx;
  size_t txSize = 0;
  size_t txOffset = 0;
  uint32_t txStartedAt = 0;
  std::array<uint8_t, 128> rxChunk;
  size_t rxOffset = 0;
  size_t rxSize = 0;
  bool eventPaused = false;
  uint32_t eventPausedAt = 0;
  uint32_t pauseLimitMs = 2u * EXPECTED_RELAY_IDLE_S * 1000u;

  uint32_t effectiveCaps = 0;   // WELCOME.caps — authoritative for this session
  uint32_t lastAckedSeq  = 0;
  uint32_t lastAckAt     = 0;
  bool     ackPending    = false;

  __attribute__((format(printf, 2, 3))) void logf(const char *format, ...) {
    std::array<char, 240> line;
    va_list args;
    va_start(args, format);
    vsnprintf(line.data(), line.size(), format, args);
    va_end(args);
    io->log(line.data());
  }

  // Enqueue whole frames only. Partial writes remain in this bounded FIFO.
  bool writeFrame(const uint8_t *buf, size_t n) {
    if (n > tx.size() - txSize) {
      reader.noteDropped();
      return false;
    }
    if (txSize == 0) { txStartedAt = io->now(); txOffset = 0; }
    if (txOffset + txSize + n > tx.size()) {
      memmove(tx.data(), tx.data() + txOffset, txSize);
      txOffset = 0;
    }
    memcpy(tx.data() + txOffset + txSize, buf, n);
    txSize += n;
    return true;
  }

  bool sendEncoded(const uint8_t *frame, tsb::EncodeResult result, const char *failure) {
    if (result.ok() && writeFrame(frame, result.size)) return true;
    teardown(failure);
    return false;
  }

  // §12.1 — 1 s doubling to a 30 s cap, plus up to 25 % jitter, forever.
  // `floorMs` raises the floor (BYE.retry_after_s); `forceMax` jumps straight to
  // the cap, which is what §7 requires of BYE(1 UNSUPPORTED_VERSION): a version
  // mismatch needs a reflash, not a retry, and hammering the relay buries the one
  // log line that explains it. BYE(9 REPLACED) takes the cap too, so two devices
  // sharing an id do not evict each other at 1 s.
  void scheduleRetry(uint32_t floorMs, bool forceMax) {
    if (failures < FAILURES_SATURATE) ++failures;
    uint8_t shift = BACKOFF_MAX_SHIFT;
    if (failures <= BACKOFF_MAX_SHIFT + 1) shift = static_cast<uint8_t>(failures - 1);
    uint32_t backoff = forceMax ? BACKOFF_MAX_MS : (BACKOFF_BASE_MS << shift);
    if (backoff > BACKOFF_MAX_MS) backoff = BACKOFF_MAX_MS;   // caps the ramp only
    if (backoff < floorMs) backoff = floorMs;   // §6.7: a minimum, never capped
    backoff += io->jitter(backoff / 4 + 1);   // jitter
    nextAttemptAt = io->now() + backoff;
    logf("[link] retry in %lu ms (attempt %u)\n",
                  (unsigned long)backoff, (unsigned)failures);
  }

  void logCounters() {
    const tsb::Counters &c = reader.counters();
    logf("[link] counters: rx=%lu frames/%lu B tx=%lu B dropped=%lu "
                  "resync=%lu discarded=%lu oversize=%lu unknown=%lu wrongdir=%lu "
                  "short=%lu invalid=%lu\n",
                  (unsigned long)c.framesDecoded, (unsigned long)c.bytesReceived,
                  (unsigned long)c.bytesSent, (unsigned long)c.framesDropped,
                  (unsigned long)c.resyncEvents,
                  (unsigned long)c.discardedBytesTotal,
                  (unsigned long)c.framesOversizeSkipped,
                  (unsigned long)c.framesUnknownType,
                  (unsigned long)c.framesWrongDirection,
                  (unsigned long)c.framesShortPayload,
                  (unsigned long)c.framesInvalidField);
  }

  void teardown(const char *reason, uint32_t floorMs = 0, bool forceMax = false) {
    if (state != State::Idle) {
      logf("[link] down: %s\n", reason);
      logCounters();
    }
    io->close();
    txSize = 0;
    txOffset = 0;
    rxSize = 0;
    rxOffset = 0;
    eventPaused = false;
    state = State::Idle;
    // Drops any half-assembled frame and the §4.5 budget. The §14 lifetime
    // totals survive: they are what diagnoses a link that keeps flapping.
    reader.reset(false);
    effectiveCaps = 0;
    ackPending = false;
    lastAckedSeq = 0;

    scheduleRetry(floorMs, forceMax);
  }

  void sendHello() {
    tsb::TsbHello h;
    tsb::buildHello(h, hooks->getLastSeq(), DEVICE_CAPS, io->deviceId(), io->firmwareVersion());
    std::array<uint8_t, tsb::HEADER_SIZE + tsb::LEN_HELLO> frame;
    const tsb::EncodeResult n = tsb::encodeHello(frame.data(), frame.size(), h);
    if (!sendEncoded(frame.data(), n, "hello write failed")) return;
    logf("[link] hello sent, last_seq=%lu caps=0x%02lx\n",
                  (unsigned long)h.last_seq, (unsigned long)DEVICE_CAPS);
  }

  void sendPing() {
    std::array<uint8_t, tsb::HEADER_SIZE + tsb::LEN_TOKEN> frame;
    const tsb::EncodeResult n =
        tsb::encodePing(frame.data(), frame.size(), io->now() / 1000);
    sendEncoded(frame.data(), n, "ping write failed");
  }

  // §6.3 — a PONG echoes the token byte for byte and must go out as soon as the
  // reader returns, never coalesced behind other work.
  void sendPong(uint32_t token) {
    std::array<uint8_t, tsb::HEADER_SIZE + tsb::LEN_TOKEN> frame;
    const tsb::EncodeResult n = tsb::encodePong(frame.data(), frame.size(), token);
    sendEncoded(frame.data(), n, "pong write failed");
  }

  // §6.6 — informational, rate limited, coalesced to the highest seq the app has
  // actually enqueued. The relay never makes delivery conditional on it.
  void maybeSendAck() {
    if (!ackPending || (effectiveCaps & tsb::CAP_ACK) == 0) return;
    const uint32_t now = io->now();
    if (now - lastAckAt < ACK_MIN_INTERVAL_MS) return;

    const uint32_t seq = hooks->getLastSeq();
    ackPending = false;
    lastAckAt = now;
    if (seq == 0 || seq == lastAckedSeq) return;

    std::array<uint8_t, tsb::HEADER_SIZE + tsb::LEN_TOKEN> frame;
    const tsb::EncodeResult n = tsb::encodeAck(frame.data(), frame.size(), seq);
    if (!sendEncoded(frame.data(), n, "ack write failed")) return;
    lastAckedSeq = seq;
  }

  void handleWelcome(const tsb::TsbWelcome &w) {
    state = State::Streaming;
    streamingAt = io->now();      // reset the ramp only after a stable interval
    effectiveCaps = w.caps & DEVICE_CAPS;
    pauseLimitMs = 2u * (w.idle_timeout_s ? w.idle_timeout_s : EXPECTED_RELAY_IDLE_S) * 1000u;
    lastAckedSeq = 0;

    logf("[link] relay timers: ping=%us idle=%us\n",
         (unsigned)w.ping_interval_s, (unsigned)w.idle_timeout_s);

    // §6.2: max_frame below 256 is logged and otherwise ignored — we keep using
    // 256, which every v3 peer must accept.
    if (w.max_frame < tsb::MIN_RX_MAX) {
      logf("[link] relay max_frame=%u < 256, ignoring\n",
                    (unsigned)w.max_frame);
    }
    // §6.2: the device keeps its own timers; WELCOME reports the relay's. They
    // are compared with the relay's §12 defaults, not with the device's own
    // (which differ on purpose). A mismatch is a real operational fault —
    // someone edited application.conf and believed devices followed.
    if (w.ping_interval_s != 0 && w.ping_interval_s != EXPECTED_RELAY_PING_S) {
      logf("[link] note: relay ping_interval=%us, expected %us\n",
                    (unsigned)w.ping_interval_s, (unsigned)EXPECTED_RELAY_PING_S);
    }
    if (w.idle_timeout_s != 0 && w.idle_timeout_s != EXPECTED_RELAY_IDLE_S) {
      logf("[link] note: relay idle_timeout=%us, expected %us\n",
                    (unsigned)w.idle_timeout_s, (unsigned)EXPECTED_RELAY_IDLE_S);
    }
    // The invariant that actually matters: the relay must wait longer than our
    // ping interval, or it drops a healthy device.
    if (w.idle_timeout_s != 0 &&
        (uint32_t)w.idle_timeout_s * 1000UL <= PING_INTERVAL_MS) {
      logf("[link] WARNING: relay idle_timeout=%us <= device ping "
                    "interval %lus; the relay will drop this link\n",
                    (unsigned)w.idle_timeout_s,
                    (unsigned long)(PING_INTERVAL_MS / 1000));
    }

    LinkWelcome lw;
    lw.latestSeq    = w.latest_seq;
    lw.serverTime   = w.server_time;
    lw.sessionId    = w.session_id;
    lw.caps         = effectiveCaps;
    lw.replayWindow = w.replay_window;
    hooks->onWelcome(lw);

    logf("[link] welcomed: latest_seq=%lu session=%08lx caps=0x%02lx\n",
                  (unsigned long)w.latest_seq, (unsigned long)w.session_id,
                  (unsigned long)w.caps);
  }

  void handleEvent(const tsb::TsbEvent &e, uint8_t frameFlags) {
    Notification n;
    notificationFromEvent(e, frameFlags, n);   // notification_wire.h, host-tested
    if (!hooks->onNotify(n)) {
      teardown("notification refused; reconnect for replay");
      return;
    }
    ackPending = true;   // ACK reports whatever the app actually enqueued (§10.5)
  }

  void handleStats(const tsb::TsbStats &st) const {
    StreamStats s;
    s.viewers         = st.viewers;
    s.msgTotal        = st.msg_total;
    s.uptimeSec       = st.uptime_s;
    s.followers       = st.followers;
    s.subs            = st.subs;
    s.serverTime      = st.server_time;
    s.streamStartedAt = st.stream_started_at;
    s.chatRate        = st.chat_rate;
    s.live            = st.live;     // decoder already folded non-zero to 1
    s.sflags          = st.sflags;
    hooks->onStats(s);
  }

  // §6.7 — BYE is advisory and always the last frame on the connection. Log it,
  // close, do not answer.
  void handleBye(const tsb::TsbBye &b) {
    std::array<char, sizeof(b.reason)> reason;
    memcpy(reason.data(), b.reason, reason.size());
    reason.back() = '\0';
    replaceDisplayControls(reason.data());
    logf("[link] BYE code=%u detail=%u retry_after=%us reason=\"%s\"\n",
                  (unsigned)b.code, (unsigned)b.detail,
                  (unsigned)b.retry_after_s, reason.data());
    const uint32_t floorMs = (uint32_t)b.retry_after_s * 1000UL;
    const bool forceMax = (b.code == tsb::BYE_UNSUPPORTED_VERSION ||
                   b.code == tsb::BYE_REPLACED);
    if (b.code == tsb::BYE_UNSUPPORTED_VERSION) {
      logf("[link] version refused by relay: this device needs a reflash");
    }
    teardown("bye", floorMs, forceMax);
  }

  void dispatch(const tsb::InboundFrame &f) {
    switch (f.header.type) {
      case tsb::T_WELCOME:
        if (state == State::Streaming) teardown("duplicate welcome");
        else handleWelcome(f.as.welcome);
        break;
      case tsb::T_EVENT:      handleEvent(f.as.event, f.header.flags); break;
      case tsb::T_STATS:      handleStats(f.as.stats); break;
      case tsb::T_PING_RELAY: sendPong(f.as.token.value); break;
      case tsb::T_PONG_RELAY: break;   // liveness already noted via lastRxAt
      case tsb::T_BYE:        handleBye(f.as.bye); break;
      default:                break;   // decodeInboundPayload never returns Ok here
    }
  }

  // One complete frame is sitting in the reader. Decode it, apply the session
  // layer rules the codec deliberately leaves to the caller (§7 version, §11.2
  // handshake strictness), then release it.
  bool checkVersion(const tsb::TsbHeader &h) {
    if (h.version == tsb::VERSION || h.type == tsb::T_BYE) return true;
    logf("[link] protocol version %u, expected %u\n",
         (unsigned)h.version, (unsigned)tsb::VERSION);
    teardown("version mismatch");
    return false;
  }

  bool maybePauseEvent(const tsb::TsbHeader &h) {
    if (state == State::Streaming && h.type == tsb::T_EVENT &&
        !hooks->canReceiveNotify()) {
      if (!eventPaused) eventPausedAt = io->now();
      eventPaused = true;
      return true;
    }
    eventPaused = false;
    return false;
  }

  bool enforceHandshakeStrictness(const tsb::TsbHeader &h, tsb::DecodeResult result) {
    if (state != State::Connect) return true;
    if ((h.type == tsb::T_WELCOME || h.type == tsb::T_BYE) &&
        result == tsb::DecodeResult::Ok) return true;
    logf("[link] handshake: type=0x%02x %s\n", (unsigned)h.type,
         tsb::decodeResultName(result));
    teardown("bad handshake");
    return false;
  }

  void noteSkippedFrame(const tsb::TsbHeader &h, tsb::DecodeResult result) {
    ++skippedSinceLog;
    if (io->now() - lastSkipLogAt < 1000) return;
    logf("[link] skipped %lu frame(s); last type=0x%02x %s\n",
         (unsigned long)skippedSinceLog, (unsigned)h.type,
         tsb::decodeResultName(result));
    skippedSinceLog = 0;
    lastSkipLogAt = io->now();
  }

  void deliverFrame() {
    const tsb::TsbHeader h = reader.header();
    if (!checkVersion(h) || maybePauseEvent(h)) return;
    // ANY complete frame, including skipped payloads, proves inbound liveness.
    lastRxAt = io->now();
    tsb::InboundFrame frame;
    const tsb::DecodeResult result = tsb::decodeInboundPayload(
        h, reader.payload(), reader.payloadLength(), frame);
    reader.noteDecode(result);
    reader.consumeFrame();
    if (!enforceHandshakeStrictness(h, result)) return;
    if (result != tsb::DecodeResult::Ok) { noteSkippedFrame(h, result); return; }
    dispatch(frame);
  }

  void readAvailable() {
    uint32_t budget = RX_BUDGET_PER_LOOP;
    while (state != State::Idle && budget > 0) {
      if (reader.hasFrame()) {
        deliverFrame();
        if (state == State::Idle || eventPaused) return;
      }
      if (rxOffset == rxSize) {
        const int n = io->read(rxChunk.data(), rxChunk.size());
        if (n < 0) { teardown("peer closed/read failed"); return; }
        if (n == 0) return;
        rxOffset = 0;
        rxSize = (size_t)n;
      }
      size_t want = rxSize - rxOffset;
      if (want > budget) want = budget;
      const size_t used = reader.feed(rxChunk.data() + rxOffset, want);
      rxOffset += used;
      budget -= used;
      if (reader.isFatal()) { teardown("framing violation"); return; }
      if (used == 0 && !reader.hasFrame()) return;
    }
  }

  void flushOutput() {
    if (txSize == 0) return;
    if (io->now() - txStartedAt >= WRITE_TIMEOUT_MS) {
      teardown("write timeout");
      return;
    }
    const int written = io->write(tx.data() + txOffset, txSize);
    if (written < 0) { teardown("write failed"); return; }
    if (written == 0) return;
    reader.noteSent((uint32_t)written);
    txSize -= (size_t)written;
    txOffset += (size_t)written;
    // Deadline bounds total pending output, not a trickle's inter-write gap.
  }

  void attemptConnect() {
    if (!io->readyForConnect()) return;
    logf("[link] connecting...\n");
    if (!io->startConnect()) { teardown("connect unavailable"); return; }
    state = State::Connecting;
    connectedAt = io->now();
  }

  void finishConnect() {
    const LinkTransport::Connect result = io->connectStatus();
    if (result == LinkTransport::Connect::Failed) {
      teardown("connect failed");
    } else if (result == LinkTransport::Connect::Ready) {
      state = State::Connect;
      reader.reset(false);
      effectiveCaps = 0;
      ackPending = false;
      connectedAt = io->now();
      lastRxAt = connectedAt;
      lastPingAt = connectedAt;
      logf("[link] connected\n");
      sendHello();
    } else if (io->now() - connectedAt >= CONNECT_TIMEOUT_MS) {
      teardown("connect timeout");
    }
  }

  void init(const LinkHooks *h, LinkTransport &transport) {
    *this = LinkSession{};
    hooks = h;
    io = &transport;
    io->begin();
  }

  // True when a session deadline expired and the link was torn down.
  bool checkTimeouts(uint32_t now) {
    if (state == State::Connect && now - connectedAt > WELCOME_TIMEOUT_MS) {
      teardown("welcome timeout");
      return true;
    }
    // Backpressure can hide peer heartbeats, but cannot keep a dead peer online
    // forever. The original pause timestamp survives repeated loop iterations.
    if (eventPaused && now - eventPausedAt >= pauseLimitMs) {
      teardown("notification pause timeout");
      return true;
    }
    if (!eventPaused && now - lastRxAt > RX_TIMEOUT_MS) {
      teardown("heartbeat timeout");
      return true;
    }
    return false;
  }

  bool isUp() const { return state == State::Streaming; }

  void loop() {
    if (!hooks || !io) return;
    io->poll();
    const bool wifiLost = io->takeWifiDisconnect();
    if (wifiLost || !io->wifiConnected()) {
      if (state != State::Idle) teardown("wifi lost");
      return;
    }
    if (state == State::Idle) {
      if ((int32_t)(io->now() - nextAttemptAt) >= 0) attemptConnect();
      return;
    }
    if (state == State::Connecting) {
      finishConnect();
      if (state != State::Connect) return;
    }
    flushOutput();
    if (state == State::Idle) return;
    readAvailable();
    if (state == State::Idle) return;

    const uint32_t now = io->now();
    if (checkTimeouts(now)) return;
    if (state == State::Streaming && now - streamingAt >= STABLE_STREAM_MS)
      failures = 0;
    if (now - lastPingAt > PING_INTERVAL_MS) {
      lastPingAt = now;
      sendPing();
      if (state == State::Idle) return;
    }
    maybeSendAck();
    if (state != State::Idle) flushOutput();
  }

};
LinkSession session;
}  // namespace

void linkInit(const LinkHooks *hooks, LinkTransport &transport) { session.init(hooks, transport); }
bool linkIsUp() { return session.isUp(); }
void linkLoop() { session.loop(); }

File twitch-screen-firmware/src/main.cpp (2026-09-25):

// Round-LCD notification client. Protocol TSB/3: persistent TCP on port 8099,
// fixed-offset binary frames, relay push. See docs/PROTOCOL.md — it is the
// contract, and this file implements §10.2 (baseline) and §10.5 (the queue).
// UI: LVGL (ui_idle / ui_notify).
//
// Wiring (matches build_flags in platformio.ini).
// DevKit V1 silkscreen "D<n>" == GPIO<n>; GPIO16 is silkscreened "RX2".
//   LCD pin  ->  Silkscreen  (GPIO)
//   VCC      ->  3V3
//   GND      ->  GND
//   DIN      ->  D23         (23, VSPI MOSI)
//   CLK      ->  D18         (18, VSPI SCK)
//   CS       ->  D5          (5)
//   DC       ->  RX2         (16)
//   RST      ->  D4          (4)
//   BL       ->  D15         (15, PWM dimmable; tie to 3V3 for always-on)

#include <Arduino.h>
#include <esp_system.h>
#include <esp_task_wdt.h>

#include "app_log.h"
#include "notification.h"
#include "notify_queue.h"
#include "link_client.h"
#include "lv_port.h"
#include "ui_idle.h"
#include "ui_notify.h"

namespace {

// §5: the device notification queue holds at least 8 entries.
constexpr size_t QUEUE_CAP = 8;
constexpr uint32_t WATCHDOG_TIMEOUT_S = 10;
constexpr uint32_t STACK_REPORT_MS = 60000;

// The queue and the sequence accounting live in notify_queue.h so that §10.2
// and §10.5 are covered by the host test rather than only by this comment.
NotifyQueue<QUEUE_CAP> queue;

// §10.2, applied in the order the specification gives.
void onWelcome(const LinkWelcome &w) {
  const NotifyQueue<QUEUE_CAP>::Greet g = queue.greet(w.latestSeq, w.sessionId);
  if (queue.sessionChanged()) {
    appLog("[app] relay session changed: %08lx\n", (unsigned long)w.sessionId);
  }
  if (g == NotifyQueue<QUEUE_CAP>::Greet::Rebaselined) {
    appLog("[app] re-baseline: last_seq=%lu session=%08lx\n",
                  (unsigned long)queue.lastSeq(), (unsigned long)w.sessionId);
  } else {
    appLog("[app] resuming at last_seq=%lu, expecting replay of up to %u\n",
                  (unsigned long)queue.lastSeq(), (unsigned)w.replayWindow);
  }
}

bool onNotify(const Notification &n) {
  const NotifyQueue<QUEUE_CAP>::Offer r = queue.offer(n);

  if (r == NotifyQueue<QUEUE_CAP>::Offer::Duplicate) return true;

  if (r == NotifyQueue<QUEUE_CAP>::Offer::Refused) {
    // §10.5 rule 2: the newest is refused and the high-water mark does not move,
    // so the next greet replays this event instead of stepping over it.
    appLog("[app] queue full, refused #%lu %s (last_seq stays %lu, "
                  "%lu refused, %lu shown)\n",
                  (unsigned long)n.seq, kindLabel(n.kind),
                  (unsigned long)queue.lastSeq(), (unsigned long)queue.refused(),
                  (unsigned long)queue.shown());
    return false;
  }

  if (!kindIsKnown(n.wireKind)) {
    // §6.4.2: rendered as INFO from actor/text, never dropped.
    appLog("[app] new #%lu unknown kind 0x%02x -> INFO: %s\n",
                  (unsigned long)n.seq, (unsigned)n.wireKind, n.actor);
  } else {
    appLog("[app] new #%lu %s%s: %s\n", (unsigned long)n.seq,
                  kindLabel(n.kind), n.replay ? " (replay)" : "", n.actor);
  }
  return true;
}

bool canReceiveNotify() { return queue.size() < QUEUE_CAP; }

uint32_t getLastSeq() { return queue.lastSeq(); }

void onStats(const StreamStats &s) { uiIdleSetStats(s); }

const LinkHooks HOOKS = {onWelcome, onNotify, canReceiveNotify, onStats, getLastSeq};

}  // namespace

void setup() {
  Serial.setTxBufferSize(1024);
  Serial.begin(115200);
  appLog("[app] reset reason=%d\n", (int)esp_reset_reason());

  lvPortInit();
  uiIdleBuild();
  uiNotifyInit();

  lvPortPump(); // render CONNECTING before starting network work
  linkInit(&HOOKS, linkPlatform());
  // IDF 4.4 updates an existing TWDT configuration; do not assume success.
  const esp_err_t watchdog = esp_task_wdt_init(WATCHDOG_TIMEOUT_S, true);
  if (watchdog == ESP_OK) enableLoopWDT();
  const esp_err_t subscribed = esp_task_wdt_status(nullptr);
  appLog("[app] watchdog init=%s loop=%s timeout=%lus\n",
         esp_err_to_name(watchdog), esp_err_to_name(subscribed),
         (unsigned long)WATCHDOG_TIMEOUT_S);
}

void loop() {
  lvPortPump();

  linkLoop();

  uiIdleSetOnline(linkIsUp());

  Notification n;
  if (!uiNotifyBusy() && queue.take(n)) {
    uiNotifyShow(n);
  }

  static uint32_t lastStackReportAt = 0;
  if (millis() - lastStackReportAt >= STACK_REPORT_MS) {
    lastStackReportAt = millis();
    // ESP-IDF reports the task high-water mark in bytes. Hardware runs must
    // exercise rendering/replay to establish the actual minimum headroom.
    appLog("[app] loop stack minimum free=%lu B\n",
           (unsigned long)uxTaskGetStackHighWaterMark(nullptr));
  }
  delay(5);
}

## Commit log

2026-09-25 Checkpoint: relay, firmware, CAD and the TSB/3 protocol specification
    This is a safety checkpoint, not a working state. The relay does not
    compile.
    What is complete and verified:
    - twitch-screen-relay: Scala 3 / Mill backend on JDK 25 — device link,
    event bus, Twitch integration, management API, alerting, observability.
    Was green at 101 tests before the protocol work began.
    - twitch-screen-cad-design: restructured; scripts, CAD output and renders.
    - twitch-screen-firmware/docs/PROTOCOL.md: TSB/3, the custom binary wire
    protocol that supersedes NDJSON v2. 1599 lines, 20 golden test vectors.
    Fixed 8-byte header, little-endian, fixed-offset payload records, no
    monet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
    [TwitchScreen.FCStd, TwitchScreen.blend, TwitchScreen_assembly.step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]
2026-09-25 Replace NDJSON v2 with the TSB/3 binary protocol on both sides
    The relay and the firmware now speak a custom binary protocol over the
    persistent TCP link, specified in twitch-screen-firmware/docs/PROTOCOL.md.
    Wire format
    8-byte header: magic a7 53, version, type, u16 length, flags, and a
    positionally-weighted header check — a plain additive sum collides on
    exactly the one-byte stream shift it exists to catch. Little-endian
    throughout. Fixed-offset, naturally-aligned payload records, so the
    device decodes with a bounds check and a memcpy and neither side can
    disagree about a field that has one offset and one width. A bad header
    shifts the window by one byte rather than tearin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
    [link_client.cpp, main.cpp]
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2026-09-25 Add Twitch OAuth user-token flow to the relay
    Replace the statically configured RELAY_TWITCH_USER_TOKEN with a runtime
    authorization-code flow: GET /api/v1/twitch/authorize redirects to the
    consent screen, the callback exchanges the code and persists the token
    to a token file, and the relay refreshes and validates it from then on.
    GET/DELETE /api/v1/twitch/authorization expose and revoke the held
    token without ever leaking it.
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2026-09-25 fix: keep firmware rendering through reconnects and event bursts
    [link_client.cpp, main.cpp]
2026-09-25 fix: bound notification text and display memory use
    [lv_port.cpp, ui_idle.cpp]
2026-09-25 fix: clarify TSB3 recovery limits and align receiver counters
    [proto_codec.cpp]
2026-09-25 fix: keep teardown and version checks responsive under backpressure
    [link_client.cpp]
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2026-09-25 build: align Netty modules on the patched 4.2.18 release
    Use the Netty BOM to keep all 40 resolved Netty modules aligned. The OSV scan no longer returns the four Netty advisory matches; the 19 API regressions pass. Combined live HTTP and container validation remains the integration gate.
2026-09-25 build: override transitive Jawn parser with the security release
    Resolve jawn-parser_3 1.7.0 to remove both current parser denial-of-service advisory matches. The 19 API regressions pass. Correct the unrelated instrumentation comment without changing its tested version.
2026-09-25 ci: audit resolved runtime dependencies with explicit expiring exceptions
    Query every resolved Maven runtime coordinate and follow per-query OSV pagination. Unknown layouts, incomplete responses and stale or expired exceptions fail the scan. Seven offline regressions cover completeness and exact exception boundaries. Record the current 182-coordinate scan and the source-assessed, one-month legacy configuration exceptions.
2026-09-25 docs: document stable-stream backoff reset and test REPLACED cap
    FW-09: PROTOCOL.md section 12 and 12.1 now describe the implemented
    backoff: the ramp resets only after 60 s of continuous streaming
    (STABLE_STREAM_MS), not on WELCOME, and BYE(1 UNSUPPORTED_VERSION) and
    BYE(9 REPLACED) jump to the 30 s cap. No wire change. The scheduleRetry
    comment in link_client.cpp now names REPLACED (comment only).
    Adds testReplacedAndVersionByeJumpToCap() to test_link_session.
    Validation:
    - Red check: removing the REPLACED clause from handleBye fails the new
    test; source restored and byte-compared.
    - platformio test -e native -e native-sanitized: 10/10 cases pass,
    test_link_session 91 checks, 0 failu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
    [link_client.cpp]
2026-09-25 fix: rebuild the Twitch client when the app token is rejected
    RLY-03: route app-token 401s from Helix stream polling, EventSub
    reconciliation and broadcaster lookup to a session rebuild instead of
    retrying forever against the same client. Extract the supervisor loop
    and pace rebuilds (1 s after restart, 30 s after a failed session).
    Validation: TwitchRecoverySuite 14/14, twitch suites 52/52, full relay
    suite 324 tests, compile -Werror and scalafmt check pass.
2026-09-25 fix: build firmware against LVGL 9 animation API and tighten tests
    - FW-08: replace removed lv_anim_set_playback_duration/lv_anim_set_ready_cb
    usages in ui_idle.cpp and ui_notify.cpp so the esp32dev build compiles
    with the new platformio.ini flag.
    - FW-24: extend link wire and proto codec tests and the custom test runner.
    Validation: red build with the flag alone failed as intended; esp32dev
    build and native test suites pass with the fix (PlatformIO 6.1.18).
    [ui_idle.cpp]
2026-09-25 fix: extract EventSub WebSocket registration from LiveTwitchSource
    - RLY-11: move WebSocket subscription registration into
    WebSocketRegistration with a dedicated suite.
    Validation (twitch-screen-relay/):
    - WebSocketRegistrationSuite x3: 8/8 each run
    - 6 Twitch suites: 60 tests, 0 failed
    - ./mill --no-daemon compile (-Werror): SUCCESS
2026-09-25 docs: add consolidated 4-pass swarm review summary
    21-agent review of twitch-screen-relay (Scala 3) and twitch-screen-firmware
    (C++/PlatformIO): bug hunt, code smells, security/performance, and
    cross-cutting protocol parity. 0 Critical / 2 High / ~45 Medium findings,
    deduplicated, with fix order. New findings complement the RLY/FW/PROTO
    registers in tasks/review-*.md.
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2026-09-25 test: verify EventSub webhook callback is reachable before ingestion (RLY-43)
    - ManagementRoutesSuite afterBind hook sends a signed, unauthenticated
    webhook_callback_verification and asserts the echoed challenge.
    - Shared EventSubSigning test helper replaces duplicated HMAC code.
    - Dependencies.serve() owns the bind-then-startIngestion wiring used by
    Main; StartupOrderSuite proves ingestion starts once, after the port
    accepts connections and serves HTTP.
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2026-09-25 fix(relay): never send reserved BYE 4/6; prove REPLAY ignored on device frames (PROTO-14, PROTO-16)
    Remove the unused ProtocolError.InvalidSequence variant and make byeAdvice an
    exhaustive match, so no error can advise BYE 4 or 6 (reserved, §6.7). Keep the
    ByeCode values for decoding and logging. Add a Mirror-guarded boundary test over
    every variant, plus a DeviceLinkSuite case showing REPLAY-flagged device PING/ACK
    frames are answered and recorded without BYE or skips.
2026-09-25 fix(relay): contain sequence exhaustion without crashing the relay (PROTO-18)
    At SeqNo.Max the hub now refuses publication with a typed
    SequenceExhausted instead of throwing inside the actor. The refusal
    mutates nothing and sends no frame, and it is reported once: an error
    log line and a latched RelayFailure("device-hub", ...), so the router's
    Alert card for that failure cannot loop. StatsAggregator falls back to
    broadcastStats on a refused lifecycle card, so section 6.5 STATS still
    lands and the supervised fork keeps running. POST /notifications maps
    the refusal to a documented 503, and /status gains the additive field
    deviceLink.sequenceExhausted. A private[relay] DeviceHub.startingAt seam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
2026-09-25 fix(relay): validate device-link timers and default TTL in wire units (RLY-25, RLY-16)
    Require idle-timeout and ping-interval to be whole seconds and compare
    them in wire seconds (§6.2, §12); require default-ttl to be a multiple of
    100 ms within u16 deciseconds; replace the magic 18 greeting frames with
    DeviceLinkConfig.GreetingFrames derived from the single ChatReplaySize.
2026-09-25 fix(relay): normalize nullable channel-update fields on the EventSub WebSocket path (RLY-21)
    twitch4j leaves ChannelUpdateV2Event fields null when Twitch omits them,
    so a missing title or category reached the tracker and the activity log as
    the text "null". A pure TwitchEventHandlers.channelUpdated mapper now turns
    a null title or category into "" and a null broadcaster into the configured
    channel, mirroring the webhook's channel.update mapping.
    RLY-21
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2026-09-25 test: make protocol prose parity checks fail closed
    Addresses Kimi H2, cross-cutting protocol drift, gen_vectors zero assertions, and brittle vector anchors. Documents the trusted-LAN and physical-access threat model and bounds stalled replay backpressure. Checks: all 20 golden vectors and 213 prose assertions; 11 Python tool tests.
2026-09-25 fix: validate configuration boundaries and mask unknown secrets
    Addresses Kimi config secret masking, callback casing, scope/timer/buffer validation, auth-default bypass, duplicate readers, hostname/list coercion, and independent config reload findings. ConfigSuite: 31 tests passed; warnings-as-errors compilation passed.
2026-09-25 fix: bound incomplete HTTP reads and tighten auth responses
    Addresses Kimi HTTP read timeout, cleartext-auth warning, magic limits, pipeline-name coupling, host casing, misplaced authentication challenges and dead enum helper findings. Existing Tapir idle timeout verified against pinned sources. Nine ManagementAuthSuite and all management routing tests pass.
2026-09-25 fix: scope telemetry installation and clamp process uptime
    Addresses Kimi unscoped OTel appender, missing metric descriptions and negative uptime findings. Instrumentation scope regression proves log export detaches; OTel linkage and diagnostic suites pass.
2026-09-25 fix: harden protocol boundaries and centralize notification policies
    Address KIMI-P01 through KIMI-P13 from tasks/review-kimi-device.md: timeout values, monotonic budgets, text limits and folding, kind policies, test-only event fixtures, and absent timestamps. Preserve existing golden-vector bytes.
2026-09-25 fix: isolate device hub failures and drain session shutdown
    Address KIMI-D01 through KIMI-D22, KIMI-D24 and KIMI-D27: per-device reclaim policy, cohesive actor state, nonblocking telemetry snapshots, explicit session I/O outcomes, bounded write deadlines, shared private encodings, visible admission failures and socket regressions.
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2026-09-25 fix: bound firmware session stalls and preserve retry state
    Address Kimi firmware duplicate WELCOME, DNS pending, unbounded event pause, capability masking, close-worker retry/null handling, WiFi retry ownership, random jitter, LinkSession extraction, frame dispatch responsibilities, TX compaction and HELLO assertion findings.
    [link_client.cpp]
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2026-09-25 fix: bound firmware display work and surface runtime failures
    Address Kimi nonblocking app logs, watchdog status, hidden LVGL churn, repeated STATS updates, replay entrance, shared presentation/layout policy, asset bounds, allocation failure handling, stack telemetry and count formatting boundary findings.
    [lv_port.cpp, main.cpp]
2026-09-25 fix: redact diagnostic cards before device delivery
    Addresses Kimi cross-cutting trust-boundary sanitization on internal warning and alert cards.
2026-09-25 fix: make Twitch authorization transitions atomic
    Addresses Kimi Medium credential publication, mixed grant reads, unusable authorized status and side-effecting construction; Low terminal refresh failures, abandoned rotated credentials, test-only await and stringly OAuth errors. Extract CSRF state and typed provider errors, preserve actual OAuth HTTP status, and use grant identity when refresh races rejection metadata. Full relay suite passes.
2026-09-25 fix: preserve EventSub redelivery and reconcile every page
    Addresses Kimi Medium dedup-before-dispatch, pagination and obsolete callbacks; Low absent event, dedup cost, duplicate transport mapping and eager bot logging; Nit Optional null round-trips. Share EventSub mapping, mark dedup completed after success, release failed claims, roll back failed lifecycle publication, and prune expired IDs only when due. Preserve subscriptions for other broadcasters and transports. Focused Twitch suites and full relay suite pass.
2026-09-25 fix: plan EventSub subscriptions from requested scopes
    Addresses Kimi H1 and Medium subscription strategy, atomic grant read, typed health components, shared call boundary and poller parameter concerns. Stream subscriptions work with reduced scopes, session health resets quietly and waits for expected EventSub observations, and token providers reject only the grant used by the failed poll. Low recovery noise and dropped failure reason, and Nit retry jitter/dead terminal branch are covered. All Twitch suites pass; full relay suite passed before the final expected-health-component regression fix.
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2026-09-25 fix(tools): name the failing vector when protocol hex is malformed
    Kimi review finding K-133 (Low): check_protocol_vectors.py brittle
    anchors fail with bare tracebacks.
    - Wrap bytes.fromhex in decode_hex so a malformed block reports the
    vector number and its origin (spec file or relay Tsb3Vectors.scala).
    - Extract relay_vectors() and accept an optional PROTOCOL.md path so
    the checker's failure paths are testable.
    - Add tests covering malformed spec/relay hex, anchor errors and the
    CLI argument handling.
    - python3 -m unittest discover -s tools/tests -v: Ran 17 tests, OK
    (new tests failed before the fix: failures=3, errors=2).
    - python3 tools/check_protocol_vectors.py: al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
2026-09-25 fix(firmware): skip redundant STATS label updates in idle UI
    Resolve Kimi review finding K-025: per-STATS label updates are
    unconditional, including the hidden group. A pure render plan
    (stats_render_plan.h) now mirrors the last rendered values so the idle
    UI only touches labels whose text changed and leaves the hidden group
    alone.
    - pio test -e native -e native-sanitized: 10/10 test cases passed
    (test_presentation: 316 checks, 0 failures; -Wall -Wextra -Werror,
    ASan+UBSan)
    - pio run -e esp32dev: SUCCESS; RAM 67,276 B (+48 B vs 67,228 B),
    flash 1,154,969 B (+216 B vs 1,154,753 B)
    - git diff --check: clean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
    [ui_idle.cpp]
2026-09-25 fix(relay-twitch): read TwitchAuth state through one atomic view
    Resolves Kimi review finding K-011 "Non-atomic compound read of
    TwitchAuth state (current, accessToken, scopes)", closing the remaining
    partial gap.
    - Delete the mutable OAuth2Credential handle and the public credential,
    current, accessToken and no-arg missingScopes accessors; every read
    now goes through view, built from a single state.get().
    - Add pure missingScopesOf(granted) shared by view, the
    completeAuthorization warning and the TwitchAuthApi callback, so the
    success page reports scopes of the grant it just installed.
    - Twitch4J receives an immutable credential snapshot per plan.
    - Add three TwitchAuthSuite tests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
2026-09-25 refactor(firmware-tests): emit constexpr instead of static const in vectors
    Addresses Kimi review finding K-115 (Low): "static const in header
    instead of constexpr". The generated test fixture vectors.h still had
    59 static const declarations from six emitter strings in gen_vectors.py.
    The generator now emits constexpr, vectors.h is regenerated, and a
    regression test in tools/tests/test_protocol_vectors.py rejects any
    static const in the generated header.
    - python3 -m unittest discover -s tools/tests -v: Ran 18 tests, OK
    (failed with match='static const' before the fix)
    - python3 tools/check_protocol_vectors.py: all 20 TSB/3 vectors match
    the specification, relay and firmware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
2026-09-25 feat(relay): count and expose device-link over-limit refusals
    Kimi review findings addressed:
    - K-056 (Low): Over-limit connections refused silently (no log/counter).
    DeviceHub now owns an atomic refusal counter; DeviceLinkServer records
    each refusal and warns on the 1st and every 100th with the running total.
    The count is exposed as deviceLink.connectionsRefused on GET /status and
    as the OTel counter relay.device.connections.refused.
    - K-147 (Nit): Accept-failure logging goes silent at the cap. Accept
    failures now log on the 1st and every 10th consecutive failure using a
    non-saturating Long, and the WARN includes the consecutive count.
    Validation (from twitch-screen-relay/):
    -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
2026-09-25 refactor(firmware): decide card entrance in a pure, tested function
    Kimi review finding K-107 (Low): "Replayed cards still play slide-in
    despite comment/§6.4". The on-device behaviour was already correct, but
    no test covered it because ui_notify.cpp is not built in env:native.
    Move the entrance decision into presentation.h as
    entranceFor(replay, kind) -> Entrance {None, Slide, FlashThenSlide}.
    Replay gives None for every kind; live Warning/Alert give
    FlashThenSlide; every other kind gives Slide. ui_notify.cpp stores the
    decision once per card and switches on it in playEntrance and hideStart.
    Timings, call order and flash colour are unchanged.
    - Red: test_presentation failed to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
2026-09-25 perf(firmware): pulse the accent ring only on warning and alert cards
    Fixes Kimi review finding K-118 (Low), "Every live card pays two
    full-screen animations". The infinite accent-ring opacity pulse forced
    layered rendering of nearly the whole panel on every frame of every live
    card's hold. The ring is now static on routine and replayed cards, and
    only live WARNING/ALERT cards pulse it. The decision is the pure
    ringPulses(Entrance) in presentation.h, keyed off entranceFor so
    severity is defined in one place.
    - Red: pio test -e native -f test_presentation failed to compile
    ('ringPulses' was not declared in this scope).
    - Green: 1371 checks, 0 failures (844 before, 527 new).
    - M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
2026-09-25 test(relay): cover PONG write failure and established-session version refusal
    Add session-level regression tests for two Kimi review findings whose
    fixes were already on main; production code does not change.
    - K-057 (Low) Failed PONG write discarded: HubResilienceSuite checks that
    a failed PONG write ends the session with WriteFailed promptly rather
    than at the idle timeout.
    - K-084 (Low) Version-mismatch Refusal duplicated: DeviceLinkSuite checks
    that a frame with another version byte on an established session gets
    BYE(1), detail 3, the 30 s floor, stamped with that version.
    TestRelay.start accepts an optional EventBus and TestRelay.detachReason
    waits for the first DeviceDisconne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
2026-09-25 fix(relay-config): reject unknown config keys and mask unknown paths in /config
    Kimi review finding K-016 (Medium-bug, relay-twitch): "Unknown or
    misspelled secret keys render unmasked in /config".
    - Every config section reader is now strict: a key the section's case
    class does not declare fails startup with UnknownKey at its full path,
    and all unknown keys are reported, not just the first.
    - ConfigKeys.of[A] derives a section's HOCON keys from its Mirror with
    the same CamelCase -> KebabCase mapping ConfigReader.derived uses.
    - Config.SchemaPaths lists every leaf path the typed config reads;
    /config renders any path outside it as ***, keeping the suffix rule as
    defence in depth.
    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
2026-09-25 refactor(firmware): name viewer animation and retry saturation bounds
    Resolve Kimi review finding K-116 (Low, firmware), "Magic numbers (3072,
    15000, shift caps 6/5, watchdog 10)". Most of the named literals already
    had constants; this names the two behavioural literals still bare:
    - ui_idle.cpp: VIEWER_ANIM_MAX = 10000 replaces the repeated 10000 in
    setViewers (counts at or above it skip the count-up animation).
    - link_client.cpp: FAILURES_SATURATE = 31 replaces the bare 31 in
    scheduleRetry, guarded by a static_assert that it covers the backoff
    ramp and stays below the 32-bit shift width.
    Behaviour is unchanged. Validation:
    - pio run -e esp32dev: RAM 67,276 B (+0), Flash 1,154,981 B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
    [link_client.cpp, ui_idle.cpp]
2026-09-25 test(relay): pin empty-rule alert monitor skip and fix K-057 test flake
    - K-072 (Low) Alert monitor runs with zero rules: the guard was already on
    main; new AlertMonitorSuite pins that no "alerts" bus subscriber starts
    when no rules are configured, and that one starts when a rule exists.
    - K-094 (Low) Rule knowledge shotgun (AlertRule + MonitorState): rule logic
    already lives in AlertRule.check; fix the stale [[MonitorState.check]]
    scaladoc link in AlertMonitor.
    Also fix a flake in the K-057 HubResilienceSuite test: the failing socket's
    flush() was guarded, so a late STATS flush could fail and close the socket
    before the PING arrived (ReadFailed inste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
2026-09-25 fix(relay-http): enforce a whole-request deadline that trickled bodies cannot extend
    Kimi review finding K-017: No idle/read timeout on HTTP listener
    (slowloris). RequestReadTimeout sits after the codec, so every decoded
    body chunk reset it; a body trickled one byte (or one chunk) at a time
    could hold a connection open almost indefinitely, and 128 such
    connections exhausted the listener, including bodies drained after an
    early 401.
    Add a per-connection RequestDeadline handler, placed after the codec and
    before the read timeout and body limit. It starts a timer on HttpRequest,
    cancels it on LastHttpContent, never extends it for plain HttpContent,
    and cancels it on channelInactive/handlerRemo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
2026-09-25 test(relay-http): pin the plaintext management-credential warning on non-loopback binds
    Addresses Kimi review finding K-018 "Cleartext management credentials
    with no warning (plain HTTP, host 0.0.0.0 default)". The WARN already
    existed but was untested; extract HttpApi.isLoopback and the warning
    text so the loopback classification (case-insensitive, IPv4, IPv6,
    bracketed IPv6) and the once-per-bind warning are covered by three new
    ManagementAuthSuite tests. Behavior and message text are unchanged.
    - testOnly ManagementAuthSuite: 14 tests, 0 failed
    - testOnly twitchscreen.relay.http.* and observability.*: 0 failed
    (one pre-existing K-017 trickle-test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
2026-09-26 fix: address Sonar findings in tools, firmware and CI
    - check_protocol_vectors: parse spec vectors line by line instead of a
    backtracking regex; drop the CLI path argument (tests call run(path))
    - audit_relay_dependencies: split Maven cache paths on "/https/" instead
    of a leading ".+" regex
    - firmware atomics: use default sequentially consistent ordering
    - bound string scans: strnlen in packWireString and the ESP32 log sink,
    aggregate init/memcpy instead of strcpy for stat chip texts, and
    strnlen/snprintf in host tests
    - CI: install platformio from wheels only (--only-binary :all:)
    [proto_codec.cpp]
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
